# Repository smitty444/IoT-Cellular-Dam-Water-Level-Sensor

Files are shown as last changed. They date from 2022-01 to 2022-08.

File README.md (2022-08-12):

# IOT-Cellular-Dam-Water-Level-Sensor
This is an Arduino Mega based stage sensor developed by interns at the South Carolina Department of Health and Environmental Control (SC DHEC) Dam Safety Program. The purpose of this sensor is to provide a low-cost, open-source alternative to traditional gaging equipment. Both an ultrasonic sensor and a pressure transducer are used to measure stage, and all data is sent via the Hologram cellular network to a graphic user interface (GUI) hosted on Adafruit IO. *Note: this repository was formerly named "DHEC-Stage-Sensor".

<p align="center">
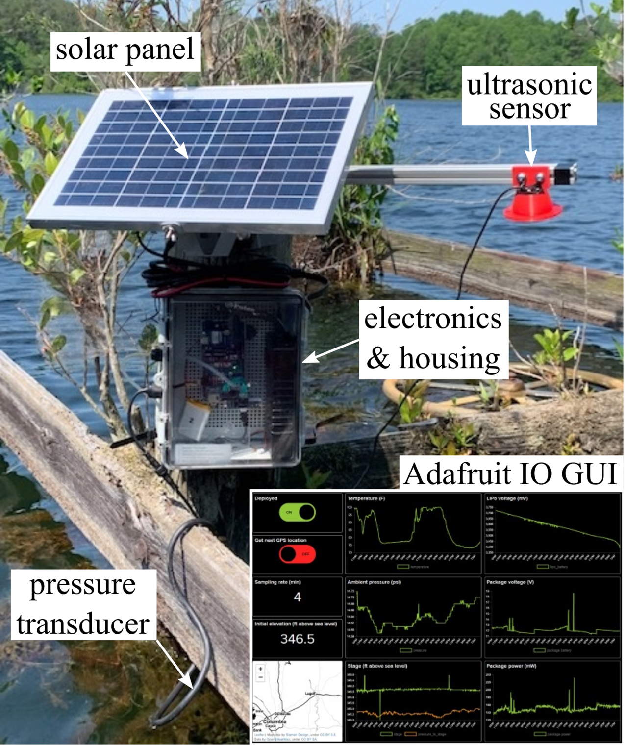
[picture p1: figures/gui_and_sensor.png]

</p>
<p align="center">
Figure 1: Sensor deployed on the primary spillway of a dam transmitting data to the GUI.
</p>

## characteristic data
contains validation data for the sensor, as well as test data for filtering, pressure transducer calibration

## code
contains all the Arduino code for the sensor

## EDA
contains all electronic design automation (EDA) files for the custom datalogging and power PCBs

## field tests
contains data for all field tests performed with the sensor package, as well as Python scripts for visualizing data

# Citation
Cite as:

@Misc{Smith2022DHECStageSensor,     
  author = {Corinne Smith and Parker Lovett and John McCain and Austin Downey},  
  howpublished = {GitHub},  
  title  = {DHEC Stage Sensor},
  year   = {2022},  
  groups = {ARTS-Lab},    
  url    = {https://github.com/ARTS-Laboratory/IoT-Cellular-Dam-Water-Level-Sensor },   
}

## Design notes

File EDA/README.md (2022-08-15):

## Overview
1. All PCBs were designed running KiCAD 6.0
2. Custom schematic symbols are located in lib_and_pretty\ARTS-Lab.lib
3. Custom footprint symbols are located in lib_and_pretty\dhec.pretty

## Datalogger PCB
The datalogger PCB is the main data acquisition and saving board. It contains the DS3231 real-time clock, microSD card module, MPRLS ambient pressure sensor, JSN-SR04 ultrasonic sensor, pressure transducer port, and indicator LEDs. 

<p align="center">
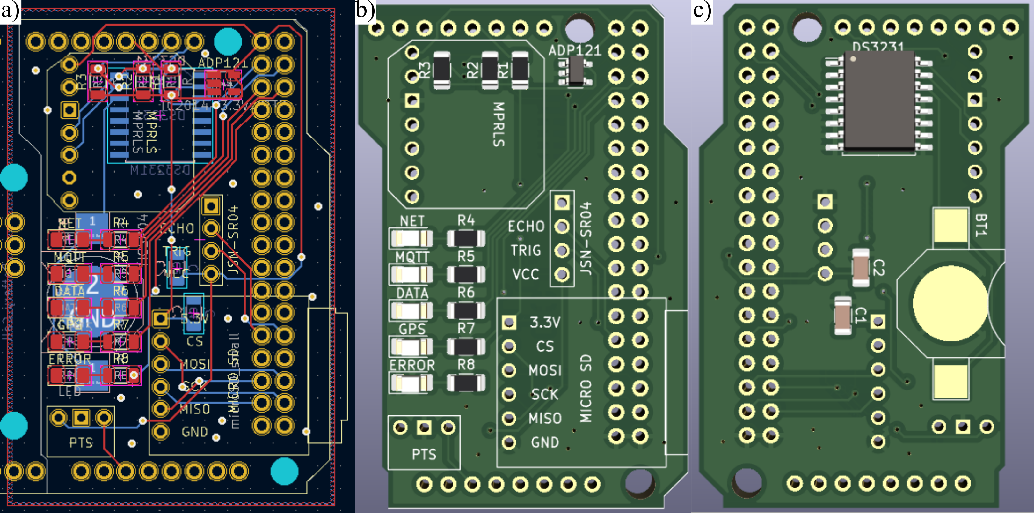
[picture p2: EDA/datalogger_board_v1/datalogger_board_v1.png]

</p>
<p align="center">
Figure 1: Datalogger board showing a) the PCB layout and the 3D rendering of the PCB b) front and c) back.
</p>

## Power control PCB
The power control PCB is used to monitor the package battery voltage and regulate the voltage to 5V for powering the Arduino Mega. It contains the INA219 current sensor and a barrel battery connector. 

<p align="center">
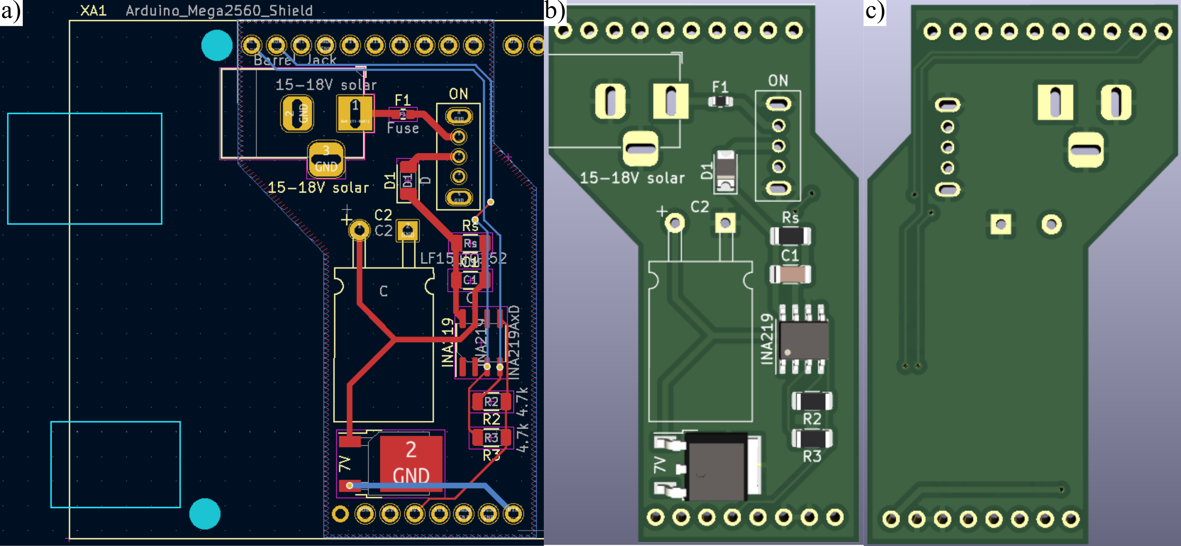
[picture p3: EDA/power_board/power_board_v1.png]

</p>
<p align="center">
Figure 1: Power control board showing a) the PCB layout and the 3D rendering of the PCB b) front and c) back.
</p>

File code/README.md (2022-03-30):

# debugging
- folder contains small sketches for troubleshooting sensors, logic flows, etc

# libraries 
- contains all the necessary libraries for codes

# water level sensor
- contains all codes created for water level sensor package

# syphon sensor
- contains all codes created for the syphon on/off sensor package

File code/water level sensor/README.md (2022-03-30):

# v1.1.x
- contains all codes from early development
- milestones: gps toggle, deployment toggle, sensor communication

# v1.2.x
- focus on power saving modes
- adaptive sampling
- milestones: RTC power down (minutes and seconds), FONA power down

# v2.x
- codes to be used with the v1 of EDA

# WLS_MQTT_toAdafruitIO_v6_STABLE
- Shawn's code for his dashboard, unedited

# working_AdafruitIO_MQTT_Demo_v2_stable
- botletics demo code configured for the SIM7000A hardware
- Publishing feeds: temperature, humidity
- Subscribing feeds: led toggle, led selection
- Outdated from current Adafruit IO dashboard

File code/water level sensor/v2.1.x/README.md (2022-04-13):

# WHS_v2.1.0.ino
- integrate DDASA v1
- Sampling rate can exceed keepAlive time
- built off of WHS_v2.0
- Publishing feeds: location, ultrasonic stage, pressure stage, temperature, ambient pressure, update gps, fona LiPo
- Subscribing feeds: deployment toggle, sampling rate, initial elevation, update gps

# WHS_v2.1.0.noSPI.ino
- Excludes error messages that stop code when SD card or MPRLS are not working
- this was made purely for a quick field test
- datalogging board experienced some issues at the SPI ports from getting wet
- use when you care about just stage readings

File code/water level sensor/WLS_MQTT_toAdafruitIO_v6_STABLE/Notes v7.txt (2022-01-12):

*****Full Disclosure*****

The DHEC-developed version of this arduino app that uses MQTT was never intended to be more than proof-of-concept for further development, and to facilitate USC senior design testing.

This program is based off of a 'Botletics' tutorial & SIMCom Library similar to that which was used for the original USC demo. 

The Botletics SIMCom library has significant limitations & liabilities. Particularly, any elements on the session and transport layers of cellular communication are certainly outside of [frazerss]'s ability to assimilate with confidence with the available resources.

"Substantially advanced cellular networking is indistinguishable from magic." -> Thus there may be inefficiencies or completely backwards problems that are due to misinterpretation of a function's function.

---- At some point, a substantial overhaul of this code may be warranted, if not absolutely necessary. ----

*****Botletics Library, Demo, and Schematic GitHub*****
https://github.com/botletics/SIM7000-LTE-Shield

*****Accessing *****
ZIP File access and extraction:
Extract "Arduino_Functional_Libraries_v7_1-6-2022.zip" and place (beware copying and replacing) the 'Arduino' folder in a user's documents folder.

(If issues exist in running v7, 'v6 Stable' is a version that was burned into a zip with all of the necessary included libraries in the same directory for cross-person sending, but there are some minor updates in apparently necessary delay timings from v6 to v7)

*****SSF Known Issues*****

PRIORITY:
***USB logging is completely non-functional at this time, this should be a priority for data review.
***Pressure sensor is returning exclusively 5V (max PSI reading). Likely broken or otherwise shorted.
**Library management in Arduino environment is problematic, and inhibits attempts at source control.
*Ultrasonic sensor variability during tests at USC was problematic. (Rainfall/interference, moisture, noise... all may play factors in U/S sensor issues.)

NORMAL:
**Suspect that the complete enclosure of cellular antenna substantially decreases cellular transport-level issues.
*High-level functions can likely be optimized for memory and time optimization. (Lower-level library functions may prove to be limiting factor.)
*Subscription Checking of the Publish Frequency Control feed is irregular at best
*Variable Names are Problematic
*Email event can probably be deactivated until data calibration issues can be sorted

LOW:
*Substantial potential for memory optimization exists
*Must break up JSON publish strings into three separate publish events
*Email event process likely needs significant revision

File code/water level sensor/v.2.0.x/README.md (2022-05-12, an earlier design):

# WHS_v2.0 (STABLE)
- compatible with datalogging shield
- AT+CSCLK=1, sleep mode controlled by DTR pin
- copied over, formerly v2.0.1
- Sampling rate does not exceed 5 minutes
- any connectivity issues experienced should be from poor environment or network provider's side
- Publishing feeds: location, ultrasonic stage, pressure stage, temperature, ambient pressure, update gps
- Subscribing feeds: deployment toggle, sampling rate, initial elevation, update gps

# WHS_v2.0.1.ino
- added fona lipo feed

# WHS_v2.0.2.ino
- allow maximum delay to exceed 5 minutes

# WHS_v2.0.3.ino
- add external temperature sensor

# WHS_v2.0.4.ino
- add voltage sensor and integrate with power board

# WHS_v2.0.5.ino
- add median filtering technique

# WHS_v2.0.6.ino
- copied from WHS_v2.0.4
- does not have the median filter in order to send raw data and post process
- add contact sensor feed

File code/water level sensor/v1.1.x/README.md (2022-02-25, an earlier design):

## WHS_v1.1
- created by Corinne
- Publishing feeds: temperature, pressure, stage
- Subscribing feeds: deployment toggle, sampling rate, initial sea level elevation
- main feature is adding a while loop in the setup that will take in all subscriptions
to initialize parameters, then only start data collection once the deployment button
is toggled

## WHS_v1.1.2 
- created by Corinne
- same feeds as v1.1
- pressure sensor added

## WHS_v1.1.3
- created by Corinne
- added location feed & GPS functionality
- added indicator LEDs to display when network is connected, MQTT is connected, data is being collected, the GPS is found, and publishing errors
- NOTE: the Adafrut_FONA.h library had to be modified for this code to suppress a Not Authorized to Connect error

## WHS_v1.1.4
- created by Corinne
- Publishing feeds: location, ultrasonic stage, pressure stage, temperature, ambient pressure
- Subscribing feeds: deployment toggle, sampling rate, initial elevation
- classic datalogger setup with clock and SD card for back up saving

## WHS_v1.1.5
- created by Corinne
- Publishing feeds: location, ultrasonic stage, pressure stage, temperature, ambient pressure, update gps
- Subscribing feeds: deployment toggle, sampling rate, initial elevation, update gps
- gps toggle button that allows you to manually decide when to update the gps to save power

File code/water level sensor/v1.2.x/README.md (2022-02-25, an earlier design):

## WHS_v1.2
- created by Corinne
- Publishing feeds: location, ultrasonic stage, pressure stage, temperature, ambient pressure, update gps, contact sensor
- Subscribing feeds: deployment toggle, sampling rate, initial elevation, update gps
- Incorporate low power mode for Arduino using RTC interrupts
- Only turn GPS on when the update gps toggle is on

## WHS_v1.2.1
- created by Corinne
- add a way to turn off cellular shield

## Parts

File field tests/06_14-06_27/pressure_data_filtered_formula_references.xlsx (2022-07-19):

id |  | value | date | time |  | feet of water offset | true depth | voltage | psi | abs pressure | ambient press | dP | depth | elevation
0F1QFYVAEFYBZHAM9GJWP2SV0E | 151 | 151.78 | 2022-06-14 | 13:09:45 | 17:09:45 | 0 | 1.301 | 0.7253828564 | 1.611961903 | 15.1869619 | 14.6 | 0.586961903 | 1.354003718 | 151.83
0F1QG139KX82V4ZYH7KR3G48CX | 151.06 | 151.84 | 2022-06-14 | 13:13:41 | 17:13:41 | 0.06 | 1.361 | 0.7357771464 | 1.635060325 | 15.21006033 | 14.6 | 0.6100603254 | 1.407287159 | 151.89
0F1QG3CHB8T8NPH5HD4ACRRRBK | 151.14 | 151.92 | 2022-06-14 | 13:17:41 | 17:17:41 | 0.14 | 1.441 | 0.7496361998 | 1.665858222 | 15.24085822 | 14.6 | 0.6408582219 | 1.478331746 | 151.96
0F1QG5NQHE0MTKQ9ETVQTGRFEW | 151.14 | 151.92 | 2022-06-14 | 13:21:41 | 17:21:41 | 0.14 | 1.441 | 0.7496361998 | 1.665858222 | 15.24085822 | 14.6 | 0.6408582219 | 1.478331746 | 151.96
0F1QG7Z2CVQ63WZD7V3MQ28S5T | 151.12 | 151.9 | 2022-06-14 | 13:25:41 | 17:25:41 | 0.12 | 1.421 | 0.7461714365 | 1.658158748 | 15.23315875 | 14.65 | 0.5831587478 | 1.345230599 | 151.82
0F1QGA8717PRDDPKBXBNQ1ER00 | 151.14 | 151.92 | 2022-06-14 | 13:29:40 | 17:29:40 | 0.14 | 1.441 | 0.7496361998 | 1.665858222 | 15.24085822 | 14.65 | 0.5908582219 | 1.362991746 | 151.84
0F1QGCHERRWTEKFDR71H8WXR1A | 151.14 | 151.92 | 2022-06-14 | 13:33:41 | 17:33:41 | 0.14 | 1.441 | 0.7496361998 | 1.665858222 | 15.24085822 | 14.65 | 0.5908582219 | 1.362991746 | 151.84
0F1QGETQB1AMFHYKPXFV95ZX4M | 151.14 | 151.92 | 2022-06-14 | 13:37:41 | 17:37:41 | 0.14 | 1.441 | 0.7496361998 | 1.665858222 | 15.24085822 | 14.68 | 0.5608582219 | 1.293787746 | 151.77
0F1QGH3W16ESDVFEXGNHHS7G7K | 151.14 | 151.92 | 2022-06-14 | 13:41:40 | 17:41:40 | 0.14 | 1.441 | 0.7496361998 | 1.665858222 | 15.24085822 | 14.68 | 0.5608582219 | 1.293787746 | 151.77
0F1QGKD2ZEFWESAWC9PJ93G201 | 151.17 | 151.95 | 2022-06-14 | 13:45:40 | 17:45:40 | 0.17 | 1.471 | 0.7548333449 | 1.677407433 | 15.25240743 | 14.68 | 0.5724074331 | 1.320429467 | 151.80
0F1QGNPFANJTFF0W9ET0W8PPWH | 151.14 | 151.92 | 2022-06-14 | 13:49:41 | 17:49:41 | 0.14 | 1.441 | 0.7496361998 | 1.665858222 | 15.24085822 | 14.69 | 0.5508582219 | 1.270719746 | 151.75
0F1QGQZKA3WBH2EQ65C9JQ2H5F | 151.14 | 151.92 | 2022-06-14 | 13:53:40 | 17:53:40 | 0.14 | 1.441 | 0.7496361998 | 1.665858222 | 15.24085822 | 14.69 | 0.5508582219 | 1.270719746 | 151.75
0F1QGT8VQ2ZMKZ7XHMDJZ4H097 | 151.14 | 151.92 | 2022-06-14 | 13:57:40 | 17:57:40 | 0.14 | 1.441 | 0.7496361998 | 1.665858222 | 15.24085822 | 14.69 | 0.5508582219 | 1.270719746 | 151.75
0F1QGWJ2S78MJJN4AVYY8BM9JH | 151.14 | 151.92 | 2022-06-14 | 14:01:40 | 18:01:40 | 0.14 | 1.441 | 0.7496361998 | 1.665858222 | 15.24085822 | 14.68 | 0.5608582219 | 1.293787746 | 151.77
0F1QGYVCRMBKWJKBB6CYV2XN2K | 151.14 | 151.92 | 2022-06-14 | 14:05:41 | 18:05:41 | 0.14 | 1.441 | 0.7496361998 | 1.665858222 | 15.24085822 | 14.68 | 0.5608582219 | 1.293787746 | 151.77
0F1QH14JZR3X72SJE46X6843ZD | 151.14 | 151.92 | 2022-06-14 | 14:09:40 | 18:09:40 | 0.14 | 1.441 | 0.7496361998 | 1.665858222 | 15.24085822 | 14.68 | 0.5608582219 | 1.293787746 | 151.77
0F1QH3DTSTZVMQBQB5XMWGNT9E | 151.17 | 151.95 | 2022-06-14 | 14:13:40 | 18:13:40 | 0.17 | 1.471 | 0.7548333449 | 1.677407433 | 15.25240743 | 14.68 | 0.5724074331 | 1.320429467 | 151.80
0F1QH5Q2F9WPZRH8V6Y13HDPKT | 151.14 | 151.92 | 2022-06-14 | 14:17:40 | 18:17:40 | 0.14 | 1.441 | 0.7496361998 | 1.665858222 | 15.24085822 | 14.69 | 0.5508582219 | 1.270719746 | 151.75
0F1QH80DAJTYSQ5RYWSQDKKD96 | 151.2 | 151.98 | 2022-06-14 | 14:21:41 | 18:21:41 | 0.2 | 1.501 | 0.7600304899 | 1.688956644 | 15.26395664 | 14.7 | 0.5639566443 | 1.300935187 | 151.78
0F1QHA9H8QEXPMEGT4PWZ9SFG4 | 151.17 | 151.95 | 2022-06-14 | 14:25:40 | 18:25:40 | 0.17 | 1.471 | 0.7548333449 | 1.677407433 | 15.25240743 | 14.7 | 0.5524074331 | 1.274293467 | 151.75
0F1QHCJW1DS4NK0EKEC0HZB0EE | 151.23 | 152.01 | 2022-06-14 | 14:29:41 | 18:29:41 | 0.23 | 1.531 | 0.765227635 | 1.700505855 | 15.27550586 | 14.69 | 0.5855058555 | 1.350644907 | 151.83
0F1QHEW350KSXNPD6PHTD1EY2F | 151.26 | 152.04 | 2022-06-14 | 14:33:41 | 18:33:41 | 0.26 | 1.561 | 0.77042478 | 1.712055067 | 15.28705507 | 14.7 | 0.5870550666 | 1.354218628 | 151.83
0F1QHH5HT3P9SJ2SEA1AG9F6N7 | 151.29 | 152.07 | 2022-06-14 | 14:37:41 | 18:37:41 | 0.29 | 1.591 | 0.775621925 | 1.723604278 | 15.29860428 | 14.69 | 0.6086042778 | 1.403928348 | 151.88
0F1QHKEHRSPR0GGMSQKV6AM2ZD | 151.26 | 152.04 | 2022-06-14 | 14:41:41 | 18:41:41 | 0.26 | 1.561 | 0.77042478 | 1.712055067 | 15.28705507 | 14.69 | 0.5970550666 | 1.377286628 | 151.86
0F1QHNQQXT7P05WJ9JHZJPAENQ | 151.26 | 152.04 | 2022-06-14 | 14:45:40 | 18:45:40 | 0.26 | 1.561 | 0.77042478 | 1.712055067 | 15.28705507 | 14.7 | 0.5870550666 | 1.354218628 | 151.83
0F1QHR12TX8Z382AK9DCKRP3R2 | 151.26 | 152.04 | 2022-06-14 | 14:49:41 | 18:49:41 | 0.26 | 1.561 | 0.77042478 | 1.712055067 | 15.28705507 | 14.69 | 0.5970550666 | 1.377286628 | 151.86
0F1QHTACWEWY4BMYBCQE9Q6CET | 151.2 | 151.98 | 2022-06-14 | 14:53:41 | 18:53:41 | 0.2 | 1.501 | 0.7600304899 | 1.688956644 | 15.26395664 | 14.69 | 0.5739566443 | 1.324003187 | 151.80
0F1QHWKP9QFEBF3839DNB256W7 | 151.2 | 151.98 | 2022-06-14 | 14:57:40 | 18:57:40 | 0.2 | 1.501 | 0.7600304899 | 1.688956644 | 15.26395664 | 14.69 | 0.5739566443 | 1.324003187 | 151.80
0F1QHYWPX1HHM8S75CBKBZRE50 | 151.2 | 151.98 | 2022-06-14 | 15:01:40 | 19:01:40 | 0.2 | 1.501 | 0.7600304899 | 1.688956644 | 15.26395664 | 14.69 | 0.5739566443 | 1.324003187 | 151.80
0F1QJ1608KPG8FPBM2KSMH5S5V | 151.17 | 151.95 | 2022-06-14 | 15:05:41 | 19:05:41 | 0.17 | 1.471 | 0.7548333449 | 1.677407433 | 15.25240743 | 14.69 | 0.5624074331 | 1.297361467 | 151.78
0F1QJ3F76Q78NHN6ZEVKMX6C82 | 151.17 | 151.95 | 2022-06-14 | 15:09:40 | 19:09:40 | 0.17 | 1.471 | 0.7548333449 | 1.677407433 | 15.25240743 | 14.69 | 0.5624074331 | 1.297361467 | 151.78
0F1QJ5RHAJD3SEBYJR37ZEH3ZN | 151.17 | 151.95 | 2022-06-14 | 15:13:41 | 19:13:41 | 0.17 | 1.471 | 0.7548333449 | 1.677407433 | 15.25240743 | 14.69 | 0.5624074331 | 1.297361467 | 151.78
0F1QJ81R95CX469VGSXE1AYVKZ | 151.17 | 151.95 | 2022-06-14 | 15:17:41 | 19:17:41 | 0.17 | 1.471 | 0.7548333449 | 1.677407433 | 15.25240743 | 14.69 | 0.5624074331 | 1.297361467 | 151.78
0F1QJAAYHFSHD758DZTADFVSWG | 151.14 | 151.92 | 2022-06-14 | 15:21:40 | 19:21:40 | 0.14 | 1.441 | 0.7496361998 | 1.665858222 | 15.24085822 | 14.69 | 0.5508582219 | 1.270719746 | 151.75
0F1QJCM8HMCRXHDDMF30N70W11 | 151.17 | 151.95 | 2022-06-14 | 15:25:41 | 19:25:41 | 0.17 | 1.471 | 0.7548333449 | 1.677407433 | 15.25240743 | 14.69 | 0.5624074331 | 1.297361467 | 151.78
0F1QJEXH3GYR92TQBGHQBG2522 | 151.17 | 151.95 | 2022-06-14 | 15:29:41 | 19:29:41 | 0.17 | 1.471 | 0.7548333449 | 1.677407433 | 15.25240743 | 14.69 | 0.5624074331 | 1.297361467 | 151.78
0F1QJH6PMW4N09NXM6473J2HQS | 151.17 | 151.95 | 2022-06-14 | 15:33:41 | 19:33:41 | 0.17 | 1.471 | 0.7548333449 | 1.677407433 | 15.25240743 | 14.69 | 0.5624074331 | 1.297361467 | 151.78
0F1QJKFY8AEG5YP94NH3JV5DXD | 151.17 | 151.95 | 2022-06-14 | 15:37:41 | 19:37:41 | 0.17 | 1.471 | 0.7548333449 | 1.677407433 | 15.25240743 | 14.69 | 0.5624074331 | 1.297361467 | 151.78
0F1QJNS62PM5QD77MH7W9TA7ZY | 151.17 | 151.95 | 2022-06-14 | 15:41:41 | 19:41:41 | 0.17 | 1.471 | 0.7548333449 | 1.677407433 | 15.25240743 | 14.69 | 0.5624074331 | 1.297361467 | 151.78
0F1QJR2G54Y1QBSRTNJN4HJQ63 | 151.14 | 151.92 | 2022-06-14 | 15:45:41 | 19:45:41 | 0.14 | 1.441 | 0.7496361998 | 1.665858222 | 15.24085822 | 14.69 | 0.5508582219 | 1.270719746 | 151.75
0F1QJTBPAV9J0P5KJMD68VT30A | 151.14 | 151.92 | 2022-06-14 | 15:49:41 | 19:49:41 | 0.14 | 1.441 | 0.7496361998 | 1.665858222 | 15.24085822 | 14.69 | 0.5508582219 | 1.270719746 | 151.75
0F1QJWN0EJ5J41K7QHQS26ZBD2 | 151.14 | 151.92 | 2022-06-14 | 15:53:41 | 19:53:41 | 0.14 | 1.441 | 0.7496361998 | 1.665858222 | 15.24085822 | 14.69 | 0.5508582219 | 1.270719746 | 151.75
0F1QJYY84AHWGCVGEHRTKYXTQ4 | 151.14 | 151.92 | 2022-06-14 | 15:57:41 | 19:57:41 | 0.14 | 1.441 | 0.7496361998 | 1.665858222 | 15.24085822 | 14.69 | 0.5508582219 | 1.270719746 | 151.75
0F1QK17DHNHSKHKQSR9G6F03DA | 151.14 | 151.92 | 2022-06-14 | 16:01:41 | 20:01:41 | 0.14 | 1.441 | 0.7496361998 | 1.665858222 | 15.24085822 | 14.69 | 0.5508582219 | 1.270719746 | 151.75
0F1QK3GQPGHY10DYW15T73S1H0 | 151.14 | 151.92 | 2022-06-14 | 16:05:41 | 20:05:41 | 0.14 | 1.441 | 0.7496361998 | 1.665858222 | 15.24085822 | 14.69 | 0.5508582219 | 1.270719746 | 151.75
0F1QK5SZCJNHWB0ASRJ95C4T3A | 151.14 | 151.92 | 2022-06-14 | 16:09:41 | 20:09:41 | 0.14 | 1.441 | 0.7496361998 | 1.665858222 | 15.24085822 | 14.69 | 0.5508582219 | 1.270719746 | 151.75
0F1QK834RN8857MMYFCC8VR9WD | 151.14 | 151.92 | 2022-06-14 | 16:13:41 | 20:13:41 | 0.14 | 1.441 | 0.7496361998 | 1.665858222 | 15.24085822 | 14.69 | 0.5508582219 | 1.270719746 | 151.75
0F1QKACCKG0642WV16YA1866ZP | 151.14 | 151.92 | 2022-06-14 | 16:17:41 | 20:17:41 | 0.14 | 1.441 | 0.7496361998 | 1.665858222 | 15.24085822 | 14.69 | 0.5508582219 | 1.270719746 | 151.75
0F1QKCNN31MVMAGVY06E0Q1BRX | 151.14 | 151.92 | 2022-06-14 | 16:21:41 | 20:21:41 | 0.14 | 1.441 | 0.7496361998 | 1.665858222 | 15.24085822 | 14.69 | 0.5508582219 | 1.270719746 | 151.75
0F1QKEYSP0FJZR5V6EMSYEAK5E | 151.14 | 151.92 | 2022-06-14 | 16:25:40 | 20:25:40 | 0.14 | 1.441 | 0.7496361998 | 1.665858222 | 15.24085822 | 14.69 | 0.5508582219 | 1.270719746 | 151.75
0F1QKH85D59T2HNA5D07PWZCV5 | 151.14 | 151.92 | 2022-06-14 | 16:29:41 | 20:29:41 | 0.14 | 1.441 | 0.7496361998 | 1.665858222 | 15.24085822 | 14.69 | 0.5508582219 | 1.270719746 | 151.75
0F1QKKHBHG8KKVD4TS4V467DXR | 151.14 | 151.92 | 2022-06-14 | 16:33:41 | 20:33:41 | 0.14 | 1.441 | 0.7496361998 | 1.665858222 | 15.24085822 | 14.69 | 0.5508582219 | 1.270719746 | 151.75
0F1QKNTHP81FREDE5ZSQKSV1TG | 151.14 | 151.92 | 2022-06-14 | 16:37:40 | 20:37:40 | 0.14 | 1.441 | 0.7496361998 | 1.665858222 | 15.24085822 | 14.69 | 0.5508582219 | 1.270719746 | 151.75
0F1QKR3RQTRWPXHRP9J5MR3167 | 151.14 | 151.92 | 2022-06-14 | 16:41:40 | 20:41:40 | 0.14 | 1.441 | 0.7496361998 | 1.665858222 | 15.24085822 | 14.69 | 0.5508582219 | 1.270719746 | 151.75
0F1QKTD194HBHXE9RQZGS89DYQ | 151.12 | 151.9 | 2022-06-14 | 16:45:40 | 20:45:40 | 0.12 | 1.421 | 0.7461714365 | 1.658158748 | 15.23315875 | 14.69 | 0.5431587478 | 1.252958599 | 151.73
0F1QKWPEEEAV9ZGG4HN8V1579D | 151.14 | 151.92 | 2022-06-14 | 16:49:41 | 20:49:41 | 0.14 | 1.441 | 0.7496361998 | 1.665858222 | 15.24085822 | 14.69 | 0.5508582219 | 1.270719746 | 151.75
0F1QKYZJ8R3HWW0SGXSGPSWNAG | 151.12 | 151.9 | 2022-06-14 | 16:53:41 | 20:53:41 | 0.12 | 1.421 | 0.7461714365 | 1.658158748 | 15.23315875 | 14.69 | 0.5431587478 | 1.252958599 | 151.73
0F1QM18TT7S4J0H4X0E32W1DN7 | 151.12 | 151.9 | 2022-06-14 | 16:57:41 | 20:57:41 | 0.12 | 1.421 | 0.7461714365 | 1.658158748 | 15.23315875 | 14.7 | 0.5331587478 | 1.229890599 | 151.71
0F1QM3J1RD6YDTWNCB6RCZTFP6 | 150.64 | 151.42 | 2022-06-14 | 17:01:40 | 21:01:40 | -0.36 | 0.941 | 0.6630171159 | 1.473371369 | 15.04837137 | 14.69 | 0.3583713687 | 0.8266910734 | 151.31
0F1QM5V76KHYRDR2E5BC4QZ4EQ | 150.75 | 151.53 | 2022-06-14 | 17:05:40 | 21:05:40 | -0.25 | 1.051 | 0.6820733144 | 1.515718476 | 15.09071848 | 14.7 | 0.3907184764 | 0.9013093814 | 151.38
0F1QM84FRCTBAJWQE1NGNDS9J6 | 150.75 | 151.53 | 2022-06-14 | 17:09:40 | 21:09:40 | -0.25 | 1.051 | 0.6820733144 | 1.515718476 | 15.09071848 | 14.7 | 0.3907184764 | 0.9013093814 | 151.38
0F1QMADW6QHFQF2ND4VW70Z72B | 150.75 | 151.53 | 2022-06-14 | 17:13:41 | 21:13:41 | -0.25 | 1.051 | 0.6820733144 | 1.515718476 | 15.09071848 | 14.7 | 0.3907184764 | 0.9013093814 | 151.38
0F1QMCQ0SYFAEZEDKD7WZ7G5PB | 150.75 | 151.53 | 2022-06-14 | 17:17:41 | 21:17:41 | -0.25 | 1.051 | 0.6820733144 | 1.515718476 | 15.09071848 | 14.7 | 0.3907184764 | 0.9013093814 | 151.38
0F1QMF08JKHN80V4RMWJJMXXD2 | 150.75 | 151.53 | 2022-06-14 | 17:21:41 | 21:21:41 | -0.25 | 1.051 | 0.6820733144 | 1.515718476 | 15.09071848 | 14.7 | 0.3907184764 | 0.9013093814 | 151.38
0F1QMH9HWDCJDDJK0V79CA6A9K | 150.75 | 151.53 | 2022-06-14 | 17:25:41 | 21:25:41 | -0.25 | 1.051 | 0.6820733144 | 1.515718476 | 15.09071848 | 14.69 | 0.4007184764 | 0.9243773814 | 151.40
0F1QMKJPKK2HZ5Q703MN6ZS0JX | 150.75 | 151.53 | 2022-06-14 | 17:29:40 | 21:29:40 | -0.25 | 1.051 | 0.6820733144 | 1.515718476 | 15.09071848 | 14.69 | 0.4007184764 | 0.9243773814 | 151.40
0F1QMNW30TQWF9K7009J92015W | 150.75 | 151.53 | 2022-06-14 | 17:33:41 | 21:33:41 | -0.25 | 1.051 | 0.6820733144 | 1.515718476 | 15.09071848 | 14.69 | 0.4007184764 | 0.9243773814 | 151.40
0F1QMR57JZ0NMFDN6ZGY6GJ3MP | 150.75 | 151.53 | 2022-06-14 | 17:37:41 | 21:37:41 | -0.25 | 1.051 | 0.6820733144 | 1.515718476 | 15.09071848 | 14.69 | 0.4007184764 | 0.9243773814 | 151.40
0F1QMTEF9YZDDHE0YRJJARZZS0 | 150.75 | 151.53 | 2022-06-14 | 17:41:41 | 21:41:41 | -0.25 | 1.051 | 0.6820733144 | 1.515718476 | 15.09071848 | 14.69 | 0.4007184764 | 0.9243773814 | 151.40
0F1QMWQQ2GS6Q6ACJPJP37VF0X | 150.72 | 151.5 | 2022-06-14 | 17:45:41 | 21:45:41 | -0.28 | 1.021 | 0.6768761694 | 1.504169265 | 15.07916927 | 14.69 | 0.3891692652 | 0.8977356611 | 151.38
0F1QMZ0Y1156Y9W0KHY6T3D91T | 150.72 | 151.5 | 2022-06-14 | 17:49:41 | 21:49:41 | -0.28 | 1.021 | 0.6768761694 | 1.504169265 | 15.07916927 | 14.69 | 0.3891692652 | 0.8977356611 | 151.38
0F1QN1A7CQ30WWF90R8JZWZ50M | 150.75 | 151.53 | 2022-06-14 | 17:53:41 | 21:53:41 | -0.25 | 1.051 | 0.6820733144 | 1.515718476 | 15.09071848 | 14.69 | 0.4007184764 | 0.9243773814 | 151.40
0F1QN3KDGY08BZXRHJ2H41THG6 | 150.75 | 151.53 | 2022-06-14 | 17:57:41 | 21:57:41 | -0.25 | 1.051 | 0.6820733144 | 1.515718476 | 15.09071848 | 14.69 | 0.4007184764 | 0.9243773814 | 151.40
0F1QN5X11C8HZA2TAGQ7TZ7AEZ | 150.75 | 151.53 | 2022-06-14 | 18:01:42 | 22:01:42 | -0.25 | 1.051 | 0.6820733144 | 1.515718476 | 15.09071848 | 14.69 | 0.4007184764 | 0.9243773814 | 151.40
0F1QN85XSKTXW6XC1DFEWW0PJ9 | 150.75 | 151.53 | 2022-06-14 | 18:05:41 | 22:05:41 | -0.25 | 1.051 | 0.6820733144 | 1.515718476 | 15.09071848 | 14.69 | 0.4007184764 | 0.9243773814 | 151.40
0F1QNAF8PQR1J5NREPAAAQDTER | 150.72 | 151.5 | 2022-06-14 | 18:09:41 | 22:09:41 | -0.28 | 1.021 | 0.6768761694 | 1.504169265 | 15.07916927 | 14.69 | 0.3891692652 | 0.8977356611 | 151.38
0F1QNCRD9MHBD8CG2B719N604C | 150.72 | 151.5 | 2022-06-14 | 18:13:41 | 22:13:41 | -0.28 | 1.021 | 0.6768761694 | 1.504169265 | 15.07916927 | 14.69 | 0.3891692652 | 0.8977356611 | 151.38
0F1QNF1RZ5JVDR73VFX626NASY | 150.72 | 151.5 | 2022-06-14 | 18:17:41 | 22:17:41 | -0.28 | 1.021 | 0.6768761694 | 1.504169265 | 15.07916927 | 14.69 | 0.3891692652 | 0.8977356611 | 151.38
0F1QNHB1H2A8EW8JRN73NGRANF | 150.72 | 151.5 | 2022-06-14 | 18:21:41 | 22:21:41 | -0.28 | 1.021 | 0.6768761694 | 1.504169265 | 15.07916927 | 14.69 | 0.3891692652 | 0.8977356611 | 151.38
0F1QNKM30WZKZDHA56Z5TBNVRP | 150.72 | 151.5 | 2022-06-14 | 18:25:40 | 22:25:40 | -0.28 | 1.021 | 0.6768761694 | 1.504169265 | 15.07916927 | 14.69 | 0.3891692652 | 0.8977356611 | 151.38
0F1QNNXFDBXK4BAPXHNT3KKG0X | 150.72 | 151.5 | 2022-06-14 | 18:29:41 | 22:29:41 | -0.28 | 1.021 | 0.6768761694 | 1.504169265 | 15.07916927 | 14.69 | 0.3891692652 | 0.8977356611 | 151.38
0F1QNR6SH5PAE1SP3FW4YSGFJZ | 150.72 | 151.5 | 2022-06-14 | 18:33:41 | 22:33:41 | -0.28 | 1.021 | 0.6768761694 | 1.504169265 | 15.07916927 | 14.69 | 0.3891692652 | 0.8977356611 | 151.38
0F1QNTGDRYSB87WTRSD91Y7BMH | 150.72 | 151.5 | 2022-06-14 | 18:37:42 | 22:37:42 | -0.28 | 1.021 | 0.6768761694 | 1.504169265 | 15.07916927 | 14.69 | 0.3891692652 | 0.8977356611 | 151.38
0F1QNWS53RMRXVJ8WDTHKVMK0S | 150.72 | 151.5 | 2022-06-14 | 18:41:41 | 22:41:41 | -0.28 | 1.021 | 0.6768761694 | 1.504169265 | 15.07916927 | 14.68 | 0.3991692652 | 0.9208036611 | 151.40
0F1QNZ2C1ZHN5MAS0V98Q2499B | 150.72 | 151.5 | 2022-06-14 | 18:45:40 | 22:45:40 | -0.28 | 1.021 | 0.6768761694 | 1.504169265 | 15.07916927 | 14.68 | 0.3991692652 | 0.9208036611 | 151.40
0F1QP1BHGYNKMRF8RAQVPWY7DN | 150.72 | 151.5 | 2022-06-14 | 18:49:40 | 22:49:40 | -0.28 | 1.021 | 0.6768761694 | 1.504169265 | 15.07916927 | 14.68 | 0.3991692652 | 0.9208036611 | 151.40
0F1QP3MVJF6QWBRE3EX1HTS0XS | 150.72 | 151.5 | 2022-06-14 | 18:53:41 | 22:53:41 | -0.28 | 1.021 | 0.6768761694 | 1.504169265 | 15.07916927 | 14.68 | 0.3991692652 | 0.9208036611 | 151.40
0F1QP5Y9M3W5F6NT47X63DASH0 | 150.72 | 151.5 | 2022-06-14 | 18:57:41 | 22:57:41 | -0.28 | 1.021 | 0.6768761694 | 1.504169265 | 15.07916927 | 14.68 | 0.3991692652 | 0.9208036611 | 151.40
0F1QP87FRMEYCNQ9KJJP6D1336 | 150.72 | 151.5 | 2022-06-14 | 19:01:41 | 23:01:41 | -0.28 | 1.021 | 0.6768761694 | 1.504169265 | 15.07916927 | 14.68 | 0.3991692652 | 0.9208036611 | 151.40
0F1QPAGJV74DAY9RN2G6RC9K6W | 150.72 | 151.5 | 2022-06-14 | 19:05:41 | 23:05:41 | -0.28 | 1.021 | 0.6768761694 | 1.504169265 | 15.07916927 | 14.68 | 0.3991692652 | 0.9208036611 | 151.40
0F1QPCSYH5ZG1RYC1CYK7P9K9Q | 150.69 | 151.47 | 2022-06-14 | 19:09:41 | 23:09:41 | -0.31 | 0.991 | 0.6716790243 | 1.492620054 | 15.06762005 | 14.69 | 0.3776200541 | 0.8710939407 | 151.35
0F1QPF31KECNS9D4F0DKJ25TKJ | 150.69 | 151.47 | 2022-06-14 | 19:13:41 | 23:13:41 | -0.31 | 0.991 | 0.6716790243 | 1.492620054 | 15.06762005 | 14.68 | 0.3876200541 | 0.8941619407 | 151.37
0F1QPHC9C5VPGH0G72CEKKDT1P | 150.72 | 151.5 | 2022-06-14 | 19:17:41 | 23:17:41 | -0.28 | 1.021 | 0.6768761694 | 1.504169265 | 15.07916927 | 14.68 | 0.3991692652 | 0.9208036611 | 151.40
0F1QPKNHVF27DD7JB36ZS0GJKH | 150.72 | 151.5 | 2022-06-14 | 19:21:41 | 23:21:41 | -0.28 | 1.021 | 0.6768761694 | 1.504169265 | 15.07916927 | 14.69 | 0.3891692652 | 0.8977356611 | 151.38
0F1QPNYPKQQ6733ESBDQRGAZ28 | 150.69 | 151.47 | 2022-06-14 | 19:25:40 | 23:25:40 | -0.31 | 0.991 | 0.6716790243 | 1.492620054 | 15.06762005 | 14.68 | 0.3876200541 | 0.8941619407 | 151.37
0F1QPR83QSHJWA6A84XXRHNC8M | 150.72 | 151.5 | 2022-06-14 | 19:29:41 | 23:29:41 | -0.28 | 1.021 | 0.6768761694 | 1.504169265 | 15.07916927 | 14.69 | 0.3891692652 | 0.8977356611 | 151.38
0F1QPTH6R0113CA0EWA63P40QK | 150.69 | 151.47 | 2022-06-14 | 19:33:40 | 23:33:40 | -0.31 | 0.991 | 0.6716790243 | 1.492620054 | 15.06762005 | 14.69 | 0.3776200541 | 0.8710939407 | 151.35
0F1QPWTHNRVT65VQW155R9QESM | 150.69 | 151.47 | 2022-06-14 | 19:37:41 | 23:37:41 | -0.31 | 0.991 | 0.6716790243 | 1.492620054 | 15.06762005 | 14.69 | 0.3776200541 | 0.8710939407 | 151.35
0F1QPZ3TXY1D6YRJTP37ADG7FS | 150.69 | 151.47 | 2022-06-14 | 19:41:41 | 23:41:41 | -0.31 | 0.991 | 0.6716790243 | 1.492620054 | 15.06762005 | 14.69 | 0.3776200541 | 0.8710939407 | 151.35
0F1QQ1CZKNS2QMAN5MM49VY6R8 | 150.72 | 151.5 | 2022-06-14 | 19:45:41 | 23:45:41 | -0.28 | 1.021 | 0.6768761694 | 1.504169265 | 15.07916927 | 14.69 | 0.3891692652 | 0.8977356611 | 151.38
0F1QQ3P6GV067T1BD49N6QMSDX | 150.69 | 151.47 | 2022-06-14 | 19:49:41 | 23:49:41 | -0.31 | 0.991 | 0.6716790243 | 1.492620054 | 15.06762005 | 14.69 | 0.3776200541 | 0.8710939407 | 151.35
0F1QQ5ZKS98QNKWZSGD3Y6M8CP | 150.69 | 151.47 | 2022-06-14 | 19:53:41 | 23:53:41 | -0.31 | 0.991 | 0.6716790243 | 1.492620054 | 15.06762005 | 14.69 | 0.3776200541 | 0.8710939407 | 151.35
0F1QQ88N88SK169JFQMPTA59SF | 150.69 | 151.47 | 2022-06-14 | 19:57:40 | 23:57:40 | -0.31 | 0.991 | 0.6716790243 | 1.492620054 | 15.06762005 | 14.69 | 0.3776200541 | 0.8710939407 | 151.35
0F1QQAHZC1QEMMQRM5TDCPSBKY | 150.72 | 151.5 | 2022-06-14 | 20:01:41 | 0:01:41 | -0.28 | 1.021 | 0.6768761694 | 1.504169265 | 15.07916927 | 14.68 | 0.3991692652 | 0.9208036611 | 151.40
0F1QQCV6AZ199D9GY729S5WFGV | 150.69 | 151.47 | 2022-06-14 | 20:05:41 | 0:05:41 | -0.31 | 0.991 | 0.6716790243 | 1.492620054 | 15.06762005 | 14.68 | 0.3876200541 | 0.8941619407 | 151.37
0F1QQF4J30P7NMF78EB097J1J9 | 150.69 | 151.47 | 2022-06-14 | 20:09:41 | 0:09:41 | -0.31 | 0.991 | 0.6716790243 | 1.492620054 | 15.06762005 | 14.68 | 0.3876200541 | 0.8941619407 | 151.37
0F1QQHDPK6SKN2WH50BKAYDFQB | 150.69 | 151.47 | 2022-06-14 | 20:13:41 | 0:13:41 | -0.31 | 0.991 | 0.6716790243 | 1.492620054 | 15.06762005 | 14.68 | 0.3876200541 | 0.8941619407 | 151.37
0F1QQKPXJVZXYP8PZDJZT4JA2P | 150.69 | 151.47 | 2022-06-14 | 20:17:41 | 0:17:41 | -0.31 | 0.991 | 0.6716790243 | 1.492620054 | 15.06762005 | 14.68 | 0.3876200541 | 0.8941619407 | 151.37
0F1QQP0ARK0XNCHRAMYKS6K2CF | 150.69 | 151.47 | 2022-06-14 | 20:21:41 | 0:21:41 | -0.31 | 0.991 | 0.6716790243 | 1.492620054 | 15.06762005 | 14.68 | 0.3876200541 | 0.8941619407 | 151.37
0F1QQR9DVJBBX5K5WVEBD3SJAW | 150.69 | 151.47 | 2022-06-14 | 20:25:41 | 0:25:41 | -0.31 | 0.991 | 0.6716790243 | 1.492620054 | 15.06762005 | 14.68 | 0.3876200541 | 0.8941619407 | 151.37
0F1QQTJM3QENKQPK52SDF1BZ1S | 150.69 | 151.47 | 2022-06-14 | 20:29:41 | 0:29:41 | -0.31 | 0.991 | 0.6716790243 | 1.492620054 | 15.06762005 | 14.68 | 0.3876200541 | 0.8941619407 | 151.37
0F1QQWVY47G019YFTMZZ1DQFTP | 150.69 | 151.47 | 2022-06-14 | 20:33:41 | 0:33:41 | -0.31 | 0.991 | 0.6716790243 | 1.492620054 | 15.06762005 | 14.68 | 0.3876200541 | 0.8941619407 | 151.37
0F1QQZ549XQVVHGPFWB8TKZVQ9 | 150.69 | 151.47 | 2022-06-14 | 20:37:41 | 0:37:41 | -0.31 | 0.991 | 0.6716790243 | 1.492620054 | 15.06762005 | 14.68 | 0.3876200541 | 0.8941619407 | 151.37
0F1QR1ECVPXKDGPKDNKMB9YRHP | 150.69 | 151.47 | 2022-06-14 | 20:41:41 | 0:41:41 | -0.31 | 0.991 | 0.6716790243 | 1.492620054 | 15.06762005 | 14.68 | 0.3876200541 | 0.8941619407 | 151.37
0F1QR3QP4VXAHSERBKVGXHYJF3 | 150.69 | 151.47 | 2022-06-14 | 20:45:41 | 0:45:41 | -0.31 | 0.991 | 0.6716790243 | 1.492620054 | 15.06762005 | 14.68 | 0.3876200541 | 0.8941619407 | 151.37
0F1QR6108J6EF2JGHJG85DSJ15 | 150.69 | 151.47 | 2022-06-14 | 20:49:41 | 0:49:41 | -0.31 | 0.991 | 0.6716790243 | 1.492620054 | 15.06762005 | 14.68 | 0.3876200541 | 0.8941619407 | 151.37
0F1QR8A1QNW4JX9SZ8WNSS496R | 150.69 | 151.47 | 2022-06-14 | 20:53:40 | 0:53:40 | -0.31 | 0.991 | 0.6716790243 | 1.492620054 | 15.06762005 | 14.67 | 0.3976200541 | 0.9172299407 | 151.40
0F1QRAKBWGTDKNG0YDQB189M2Z | 150.67 | 151.45 | 2022-06-14 | 20:57:41 | 0:57:41 | -0.33 | 0.971 | 0.668214261 | 1.48492058 | 15.05992058 | 14.67 | 0.3899205799 | 0.8994687938 | 151.38
0F1QRCWJVYAN37KC6GHGGA40A0 | 150.69 | 151.47 | 2022-06-14 | 21:01:41 | 1:01:41 | -0.31 | 0.991 | 0.6716790243 | 1.492620054 | 15.06762005 | 14.67 | 0.3976200541 | 0.9172299407 | 151.40
0F1QRF5YG1FXAFASEKH84VE788 | 150.69 | 151.47 | 2022-06-14 | 21:05:41 | 1:05:41 | -0.31 | 0.991 | 0.6716790243 | 1.492620054 | 15.06762005 | 14.67 | 0.3976200541 | 0.9172299407 | 151.40
0F1QRHF0QX74VSHSC8T7BHPDW6 | 150.69 | 151.47 | 2022-06-14 | 21:09:40 | 1:09:40 | -0.31 | 0.991 | 0.6716790243 | 1.492620054 | 15.06762005 | 14.67 | 0.3976200541 | 0.9172299407 | 151.40
0F1QRKRA2Q0BK9J8KQJHCKGJJZ | 150.69 | 151.47 | 2022-06-14 | 21:13:41 | 1:13:41 | -0.31 | 0.991 | 0.6716790243 | 1.492620054 | 15.06762005 | 14.67 | 0.3976200541 | 0.9172299407 | 151.40
0F1QRP1JJTPZX69E2KYJGKQW4D | 150.69 | 151.47 | 2022-06-14 | 21:17:41 | 1:17:41 | -0.31 | 0.991 | 0.6716790243 | 1.492620054 | 15.06762005 | 14.67 | 0.3976200541 | 0.9172299407 | 151.40
0F1QRRASK0TD53RQ1XGNR1KXCD | 150.69 | 151.47 | 2022-06-14 | 21:21:41 | 1:21:41 | -0.31 | 0.991 | 0.6716790243 | 1.492620054 | 15.06762005 | 14.67 | 0.3976200541 | 0.9172299407 | 151.40
0F1QRTM23304CBQ77SD2A2RSGH | 150.67 | 151.45 | 2022-06-14 | 21:25:41 | 1:25:41 | -0.33 | 0.971 | 0.668214261 | 1.48492058 | 15.05992058 | 14.67 | 0.3899205799 | 0.8994687938 | 151.38
0F1QRWX927B1JBFJNVXPPXA3JN | 150.69 | 151.47 | 2022-06-14 | 21:29:41 | 1:29:41 | -0.31 | 0.991 | 0.6716790243 | 1.492620054 | 15.06762005 | 14.67 | 0.3976200541 | 0.9172299407 | 151.40
0F1QRZ6K79D886JZ76V014M8BQ | 150.67 | 151.45 | 2022-06-14 | 21:33:41 | 1:33:41 | -0.33 | 0.971 | 0.668214261 | 1.48492058 | 15.05992058 | 14.67 | 0.3899205799 | 0.8994687938 | 151.38
0F1QS1FX95BBXK5A8T6K7Y88JT | 150.67 | 151.45 | 2022-06-14 | 21:37:41 | 1:37:41 | -0.33 | 0.971 | 0.668214261 | 1.48492058 | 15.05992058 | 14.67 | 0.3899205799 | 0.8994687938 | 151.38
0F1QS3S2N4WBXXFVCNNKKRAYDV | 150.69 | 151.47 | 2022-06-14 | 21:41:41 | 1:41:41 | -0.31 | 0.991 | 0.6716790243 | 1.492620054 | 15.06762005 | 14.67 | 0.3976200541 | 0.9172299407 | 151.40
0F1QS62AEF9H9218XX7W8J6M0Y | 150.67 | 151.45 | 2022-06-14 | 21:45:41 | 1:45:41 | -0.33 | 0.971 | 0.668214261 | 1.48492058 | 15.05992058 | 14.67 | 0.3899205799 | 0.8994687938 | 151.38
0F1QS8BE7C0B6239N4E7ZBBWX9 | 150.67 | 151.45 | 2022-06-14 | 21:49:40 | 1:49:40 | -0.33 | 0.971 | 0.668214261 | 1.48492058 | 15.05992058 | 14.67 | 0.3899205799 | 0.8994687938 | 151.38
0F1QSAMP1537KTSNA1F33A57AS | 150.69 | 151.47 | 2022-06-14 | 21:53:40 | 1:53:40 | -0.31 | 0.991 | 0.6716790243 | 1.492620054 | 15.06762005 | 14.67 | 0.3976200541 | 0.9172299407 | 151.40
0F1QSCY0VMGSBGBFZRQAE2TT65 | 150.67 | 151.45 | 2022-06-14 | 21:57:41 | 1:57:41 | -0.33 | 0.971 | 0.668214261 | 1.48492058 | 15.05992058 | 14.67 | 0.3899205799 | 0.8994687938 | 151.38
0F1QSF77VP6T1M4SXQ5S35G00T | 150.67 | 151.45 | 2022-06-14 | 22:01:41 | 2:01:41 | -0.33 | 0.971 | 0.668214261 | 1.48492058 | 15.05992058 | 14.67 | 0.3899205799 | 0.8994687938 | 151.38
0F1QSHGEW8AZV4TBNBXQ5K0PCN | 150.67 | 151.45 | 2022-06-14 | 22:05:41 | 2:05:41 | -0.33 | 0.971 | 0.668214261 | 1.48492058 | 15.05992058 | 14.67 | 0.3899205799 | 0.8994687938 | 151.38
0F1QSKSXKXG4FACEJH337YRD5F | 150.67 | 151.45 | 2022-06-14 | 22:09:41 | 2:09:41 | -0.33 | 0.971 | 0.668214261 | 1.48492058 | 15.05992058 | 14.67 | 0.3899205799 | 0.8994687938 | 151.38
0F1QSP30PREK2YR7PNGWX6P1V9 | 150.67 | 151.45 | 2022-06-14 | 22:13:41 | 2:13:41 | -0.33 | 0.971 | 0.668214261 | 1.48492058 | 15.05992058 | 14.67 | 0.3899205799 | 0.8994687938 | 151.38
0F1QSRC6268360CX8RBE815Z3Y | 150.67 | 151.45 | 2022-06-14 | 22:17:41 | 2:17:41 | -0.33 | 0.971 | 0.668214261 | 1.48492058 | 15.05992058 | 14.67 | 0.3899205799 | 0.8994687938 | 151.38
0F1QSTNC7VCCS73F28JE4SXGGQ | 150.67 | 151.45 | 2022-06-14 | 22:21:40 | 2:21:40 | -0.33 | 0.971 | 0.668214261 | 1.48492058 | 15.05992058 | 14.68 | 0.3799205799 | 0.8764007938 | 151.36
0F1QSWYNJMD387W1N0196T9J1G | 150.67 | 151.45 | 2022-06-14 | 22:25:41 | 2:25:41 | -0.33 | 0.971 | 0.668214261 | 1.48492058 | 15.05992058 | 14.68 | 0.3799205799 | 0.8764007938 | 151.36
0F1QSZ7Y2YY5JRN3RJECTMZANG | 150.67 | 151.45 | 2022-06-14 | 22:29:41 | 2:29:41 | -0.33 | 0.971 | 0.668214261 | 1.48492058 | 15.05992058 | 14.68 | 0.3799205799 | 0.8764007938 | 151.36
0F1QT1H49CHSTATM46C65THWZF | 150.67 | 151.45 | 2022-06-14 | 22:33:41 | 2:33:41 | -0.33 | 0.971 | 0.668214261 | 1.48492058 | 15.05992058 | 14.68 | 0.3799205799 | 0.8764007938 | 151.36
0F1QT3TDKDFQZS0RJG5EZR49FC | 150.67 | 151.45 | 2022-06-14 | 22:37:41 | 2:37:41 | -0.33 | 0.971 | 0.668214261 | 1.48492058 | 15.05992058 | 14.68 | 0.3799205799 | 0.8764007938 | 151.36
0F1QT63MJXT4CX3QDAXVNM68FB | 150.67 | 151.45 | 2022-06-14 | 22:41:41 | 2:41:41 | -0.33 | 0.971 | 0.668214261 | 1.48492058 | 15.05992058 | 14.68 | 0.3799205799 | 0.8764007938 | 151.36
0F1QT8CX3BMEB60F4BZ39G0D76 | 150.67 | 151.45 | 2022-06-14 | 22:45:41 | 2:45:41 | -0.33 | 0.971 | 0.668214261 | 1.48492058 | 15.05992058 | 14.68 | 0.3799205799 | 0.8764007938 | 151.36
0F1QTAP416PFF9M6PPK700T7GX | 150.67 | 151.45 | 2022-06-14 | 22:49:41 | 2:49:41 | -0.33 | 0.971 | 0.668214261 | 1.48492058 | 15.05992058 | 14.68 | 0.3799205799 | 0.8764007938 | 151.36
0F1QTCZDAPKFS8AHM909S9ASAY | 150.67 | 151.45 | 2022-06-14 | 22:53:41 | 2:53:41 | -0.33 | 0.971 | 0.668214261 | 1.48492058 | 15.05992058 | 14.68 | 0.3799205799 | 0.8764007938 | 151.36
0F1QTF8JRDQ70WFQ4Q5NJH23ZN | 150.67 | 151.45 | 2022-06-14 | 22:57:41 | 2:57:41 | -0.33 | 0.971 | 0.668214261 | 1.48492058 | 15.05992058 | 14.68 | 0.3799205799 | 0.8764007938 | 151.36
0F1QTHHV8W2D1B71VSA0GS84M9 | 150.64 | 151.42 | 2022-06-14 | 23:01:41 | 3:01:41 | -0.36 | 0.941 | 0.6630171159 | 1.473371369 | 15.04837137 | 14.68 | 0.3683713687 | 0.8497590734 | 151.33
0F1QTKV71DACPTQBD7X1G4KCH9 | 150.67 | 151.45 | 2022-06-14 | 23:05:41 | 3:05:41 | -0.33 | 0.971 | 0.668214261 | 1.48492058 | 15.05992058 | 14.68 | 0.3799205799 | 0.8764007938 | 151.36
0F1QTP4H0R9ZJR0TD9KWB7BMQ9 | 150.67 | 151.45 | 2022-06-14 | 23:09:41 | 3:09:41 | -0.33 | 0.971 | 0.668214261 | 1.48492058 | 15.05992058 | 14.68 | 0.3799205799 | 0.8764007938 | 151.36
0F1QTRDHTPZVZMKZX3T41WAQ5W | 150.67 | 151.45 | 2022-06-14 | 23:13:40 | 3:13:40 | -0.33 | 0.971 | 0.668214261 | 1.48492058 | 15.05992058 | 14.68 | 0.3799205799 | 0.8764007938 | 151.36
0F1QTTPRPH7X6QJRJNA19YTN8M | 150.67 | 151.45 | 2022-06-14 | 23:17:40 | 3:17:40 | -0.33 | 0.971 | 0.668214261 | 1.48492058 | 15.05992058 | 14.69 | 0.3699205799 | 0.8533327938 | 151.33
0F1QTX021PHPH2Q0BZA058XKE9 | 150.67 | 151.45 | 2022-06-14 | 23:21:41 | 3:21:41 | -0.33 | 0.971 | 0.668214261 | 1.48492058 | 15.05992058 | 14.68 | 0.3799205799 | 0.8764007938 | 151.36
0F1QTZ986RZCQ44B3SG2HN9W3J | 150.64 | 151.42 | 2022-06-14 | 23:25:40 | 3:25:40 | -0.36 | 0.941 | 0.6630171159 | 1.473371369 | 15.04837137 | 14.69 | 0.3583713687 | 0.8266910734 | 151.31
0F1QV1JGRE26VANE0NFH4R8YDC | 150.67 | 151.45 | 2022-06-14 | 23:29:41 | 3:29:41 | -0.33 | 0.971 | 0.668214261 | 1.48492058 | 15.05992058 | 14.69 | 0.3699205799 | 0.8533327938 | 151.33
0F1QV3VPXJYCVHSZZG2WC0RQHM | 150.67 | 151.45 | 2022-06-14 | 23:33:40 | 3:33:40 | -0.33 | 0.971 | 0.668214261 | 1.48492058 | 15.05992058 | 14.69 | 0.3699205799 | 0.8533327938 | 151.33
0F1QV6508K23YEE6P0WZJF6H05 | 150.67 | 151.45 | 2022-06-14 | 23:37:41 | 3:37:41 | -0.33 | 0.971 | 0.668214261 | 1.48492058 | 15.05992058 | 14.69 | 0.3699205799 | 0.8533327938 | 151.33
0F1QV8EDEJTEQ5DVN6KJ885DXS | 150.64 | 151.42 | 2022-06-14 | 23:41:41 | 3:41:41 | -0.36 | 0.941 | 0.6630171159 | 1.473371369 | 15.04837137 | 14.68 | 0.3683713687 | 0.8497590734 | 151.33
0F1QVAQN7F30F77ZE8WW81WDF0 | 150.64 | 151.42 | 2022-06-14 | 23:45:41 | 3:45:41 | -0.36 | 0.941 | 0.6630171159 | 1.473371369 | 15.04837137 | 14.69 | 0.3583713687 | 0.8266910734 | 151.31
0F1QVD0VJP3KB567FZM12A7S29 | 150.64 | 151.42 | 2022-06-14 | 23:49:41 | 3:49:41 | -0.36 | 0.941 | 0.6630171159 | 1.473371369 | 15.04837137 | 14.69 | 0.3583713687 | 0.8266910734 | 151.31
0F1QVF9YEN5185RPKPNP23B2JT | 150.64 | 151.42 | 2022-06-14 | 23:53:40 | 3:53:40 | -0.36 | 0.941 | 0.6630171159 | 1.473371369 | 15.04837137 | 14.68 | 0.3683713687 | 0.8497590734 | 151.33
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

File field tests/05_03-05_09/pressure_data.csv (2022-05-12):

id |  | feed_id | date | time |  |  | value
0F0NM4S50VX3K3744G95AQ6EK7 | 153.01 | 1794775 | 5/3/2022 | 10:58:27 AM | 14:58:30 | UTC | 153.01 | 0
0F0NM778ZT6YJ29SDN1WS446D6 | 153.09 | 1794775 | 5/3/2022 | 11:02:42 AM | 15:02:46 | UTC | 153.09 | 0
0F0NM7PZAJ7N5NQTHC47W7PFFZ | 153.12 | 1794775 | 5/3/2022 | 11:03:34 AM | 15:03:37 | UTC | 153.12 | 0
0F0NMA4S4FKK5X24CGH8P9DR20 | 153.12 | 1794775 | 5/3/2022 | 11:07:49 AM | 15:07:52 | UTC | 153.12 | 0
0F0NMCC022KWT0ZRA8JDBR6H4S | 153.12 | 1794775 | 5/3/2022 | 11:11:42 AM | 15:11:45 | UTC | 153.12 | 0
0F0NMEMET3ZCJVNTS8WVAYCKJJ | 153.12 | 1794775 | 5/3/2022 | 11:15:40 AM | 15:15:43 | UTC | 153.12 | 0
0F0NMGXX07V62XDFR1RS785052 | 153.12 | 1794775 | 5/3/2022 | 11:19:40 AM | 15:19:44 | UTC | 153.12 | 0
0F0NMK6XGF462M2W4XGKRZ92FG | 153.12 | 1794775 | 5/3/2022 | 11:23:40 AM | 15:23:43 | UTC | 153.12 | 0
0F0NMNG4JK2VRXZ86WFCZS0Y11 | 153.12 | 1794775 | 5/3/2022 | 11:27:40 AM | 15:27:43 | UTC | 153.12 | 0
0F0NMQSGXMFGSHGC2J19MR7J3R | 153.12 | 1794775 | 5/3/2022 | 11:31:40 AM | 15:31:43 | UTC | 153.12 | 0
0F0NMT2Q3MCWVYYNPHZJ7SGPWS | 153.09 | 1794775 | 5/3/2022 | 11:35:40 AM | 15:35:43 | UTC | 153.09 | 0
0F0NMWC21DFESC6Z1T1TXHVRM4 | 153.09 | 1794775 | 5/3/2022 | 11:39:40 AM | 15:39:43 | UTC | 153.09 | 0
0F0NMYN6M2VWKR5J20NE51P7DC | 153.06 | 1794775 | 5/3/2022 | 11:43:40 AM | 15:43:43 | UTC | 153.06 | 0
0F0NN0YF4F4S1R4GF0364R85NT | 153.03 | 1794775 | 5/3/2022 | 11:47:40 AM | 15:47:43 | UTC | 153.03 | 0
0F0NN37MHXBP02WVQBM3XPQREF | 153.03 | 1794775 | 5/3/2022 | 11:51:40 AM | 15:51:43 | UTC | 153.03 | 0
0F0NN5H0ZKQ19MZ1RWY6KDSFY2 | 153.06 | 1794775 | 5/3/2022 | 11:55:40 AM | 15:55:43 | UTC | 153.06 | 0
0F0NN7TAASSYRXF5CW7X36Q2ME | 153.01 | 1794775 | 5/3/2022 | 11:59:40 AM | 15:59:44 | UTC | 153.01 | 0
0F0NNA3BSDHWQ23M2X836WQ5MW | 153.01 | 1794775 | 5/3/2022 | 12:03:40 PM | 16:03:43 | UTC | 153.01 | 0
0F0NNCCZ9CHQJHCQKJXAG2RYK5 | 153.01 | 1794775 | 5/3/2022 | 12:07:41 PM | 16:07:44 | UTC | 153.01 | 0
0F0NNENXPD6QSYYAZHSKABYSY6 | 153.01 | 1794775 | 5/3/2022 | 12:11:40 PM | 16:11:43 | UTC | 153.01 | 0
0F0NNGZ3V7AYGKFH3ENWW3Y0GT | 153.01 | 1794775 | 5/3/2022 | 12:15:40 PM | 16:15:43 | UTC | 153.01 | 0
0F0NNK8DYPMHYCZ06FDZ57G52C | 152.98 | 1794775 | 5/3/2022 | 12:19:40 PM | 16:19:43 | UTC | 152.98 | 0
0F0NNNHQBZXQQGZGXPWS0V0SNB | 152.98 | 1794775 | 5/3/2022 | 12:23:40 PM | 16:23:43 | UTC | 152.98 | 0
0F0NNQTSGF25HAR49CA9G4H1HJ | 152.98 | 1794775 | 5/3/2022 | 12:27:40 PM | 16:27:43 | UTC | 152.98 | 0
0F0NNT45746ZCX5S8BD7K6AQTB | 152.95 | 1794775 | 5/3/2022 | 12:31:40 PM | 16:31:43 | UTC | 152.95 | 0
0F0NNWD9S4E3XJH4CCBAS137X6 | 152.95 | 1794775 | 5/3/2022 | 12:35:40 PM | 16:35:43 | UTC | 152.95 | 0
0F0NNYPR0KX1ZZVZ5BZZ90Y1J4 | 152.92 | 1794775 | 5/3/2022 | 12:39:40 PM | 16:39:44 | UTC | 152.92 | 0
0F0NP10ESVD6W9PWJD098MNKR6 | 152.92 | 1794775 | 5/3/2022 | 12:43:40 PM | 16:43:45 | UTC | 152.92 | 0
0F0NP392R1MJRQBSTFCMW4EQD4 | 152.95 | 1794775 | 5/3/2022 | 12:47:40 PM | 16:47:43 | UTC | 152.95 | 0
0F0NP5JDFZR766JSR3429X432Q | 152.95 | 1794775 | 5/3/2022 | 12:51:40 PM | 16:51:43 | UTC | 152.95 | 0
0F0NP7VRC9XJB8CS617Y7F9ER2 | 152.92 | 1794775 | 5/3/2022 | 12:55:41 PM | 16:55:44 | UTC | 152.92 | 0
0F0NPA4RA23PE22B4DS1KFPNJE | 152.92 | 1794775 | 5/3/2022 | 12:59:40 PM | 16:59:43 | UTC | 152.92 | 0
0F0NPCE4627GX0GZTNSVJF4SQH | 152.92 | 1794775 | 5/3/2022 | 1:03:40 PM | 17:03:43 | UTC | 152.92 | 0
0F0NPEQE1HS668T4WTQJ8YR5JK | 152.92 | 1794775 | 5/3/2022 | 1:07:40 PM | 17:07:44 | UTC | 152.92 | 0
0F0NPH0GB23ZQ8T29KT9CWSRH1 | 152.92 | 1794775 | 5/3/2022 | 1:11:40 PM | 17:11:43 | UTC | 152.92 | 0
0F0NPK9RVKC056SGP83WRXZF97 | 152.92 | 1794775 | 5/3/2022 | 1:15:40 PM | 17:15:43 | UTC | 152.92 | 0
0F0NPNK28NM2ESJWV0YE1TZ67E | 152.92 | 1794775 | 5/3/2022 | 1:19:40 PM | 17:19:43 | UTC | 152.92 | 0
0F0NPQW7JJ63YHZ68JBSBKS28N | 152.89 | 1794775 | 5/3/2022 | 1:23:40 PM | 17:23:43 | UTC | 152.89 | 0
0F0NPT5FD4Y4NYHCSDFQ08VMJ1 | 152.86 | 1794775 | 5/3/2022 | 1:27:40 PM | 17:27:43 | UTC | 152.86 | 0
0F0NPWERMSPP2WQMHD9BD79PDP | 152.86 | 1794775 | 5/3/2022 | 1:31:40 PM | 17:31:43 | UTC | 152.86 | 0
0F0NPYR165F48VCCAT75320SX6 | 152.86 | 1794775 | 5/3/2022 | 1:35:40 PM | 17:35:43 | UTC | 152.86 | 0
0F0NQ119PCKRM9QPPEZR76779M | 152.86 | 1794775 | 5/3/2022 | 1:39:40 PM | 17:39:43 | UTC | 152.86 | 0
0F0NQ3AHJ9SCBFNB15GDCZ0YQQ | 152.84 | 1794775 | 5/3/2022 | 1:43:40 PM | 17:43:43 | UTC | 152.84 | 0
0F0NQ5KQM3E8YBQ6D067Q22VHD | 152.84 | 1794775 | 5/3/2022 | 1:47:40 PM | 17:47:43 | UTC | 152.84 | 0
0F0NQ7X4VW7TM8M7EVG1JC9Y8F | 152.84 | 1794775 | 5/3/2022 | 1:51:41 PM | 17:51:44 | UTC | 152.84 | 0
0F0NQA68PFSHKP0KT5ZSP4J75C | 152.84 | 1794775 | 5/3/2022 | 1:55:40 PM | 17:55:43 | UTC | 152.84 | 0
0F0NQCFE42GDTGEQPGJ9R7CSR9 | 152.84 | 1794775 | 5/3/2022 | 1:59:40 PM | 17:59:43 | UTC | 152.84 | 0
0F0NQERN2FQYQ3PMXW5KA1EA42 | 152.81 | 1794775 | 5/3/2022 | 2:03:40 PM | 18:03:43 | UTC | 152.81 | 0
0F0NQH36878VDM1795XT71MZDS | 152.84 | 1794775 | 5/3/2022 | 2:07:43 PM | 18:07:47 | UTC | 152.84 | 0
0F0NQKB5BGRKCYNM5ZHH27TS6A | 152.84 | 1794775 | 5/3/2022 | 2:11:40 PM | 18:11:43 | UTC | 152.84 | 0
0F0NQNMBJD21YVAQBH21SSE8RQ | 152.84 | 1794775 | 5/3/2022 | 2:15:40 PM | 18:15:43 | UTC | 152.84 | 0
0F0NQQXM37AZD2S8JGJ94RC2X2 | 152.84 | 1794775 | 5/3/2022 | 2:19:40 PM | 18:19:43 | UTC | 152.84 | 0
0F0NQT6V2RDGESKYN0NF6AEQVE | 152.84 | 1794775 | 5/3/2022 | 2:23:40 PM | 18:23:43 | UTC | 152.84 | 0
0F0NQWG3JC79KDF4Z4S1R6Q0CS | 152.81 | 1794775 | 5/3/2022 | 2:27:40 PM | 18:27:43 | UTC | 152.81 | 0
0F0NQYSQVV9SS3J8MD0WZ2TT77 | 152.84 | 1794775 | 5/3/2022 | 2:31:41 PM | 18:31:44 | UTC | 152.84 | 0
0F0NR12NG3B4FCVYSNNJPYY5J2 | 152.84 | 1794775 | 5/3/2022 | 2:35:40 PM | 18:35:43 | UTC | 152.84 | 0
0F0NR3BTYC85MX544SKYCJ8HM6 | 152.84 | 1794775 | 5/3/2022 | 2:39:40 PM | 18:39:43 | UTC | 152.84 | 0
0F0NR5N4XEMN4FK0973QEYEHMG | 152.84 | 1794775 | 5/3/2022 | 2:43:40 PM | 18:43:43 | UTC | 152.84 | 0
0F0NR7YKRM71TB8X6JBF2W2HWG | 152.81 | 1794775 | 5/3/2022 | 2:47:41 PM | 18:47:44 | UTC | 152.81 | 0
0F0NRA7J2BAT6GD49CH1E1BR9Y | 152.84 | 1794775 | 5/3/2022 | 2:51:40 PM | 18:51:43 | UTC | 152.84 | 0
0F0NRCGR9AS1TBSZ53GYVXZKPA | 152.84 | 1794775 | 5/3/2022 | 2:55:40 PM | 18:55:43 | UTC | 152.84 | 0
0F0NRET4PH2TTAE5503C9J25YC | 152.84 | 1794775 | 5/3/2022 | 2:59:40 PM | 18:59:43 | UTC | 152.84 | 0
0F0NRH3B01GVW7KACS8FE2N6CD | 152.89 | 1794775 | 5/3/2022 | 3:03:40 PM | 19:03:43 | UTC | 152.89 | 0
0F0NRKCFGT6JNJJP7781YH35RD | 152.84 | 1794775 | 5/3/2022 | 3:07:40 PM | 19:07:43 | UTC | 152.84 | 0
0F0NRNNTDG2K136V1J2P58VCJH | 152.84 | 1794775 | 5/3/2022 | 3:11:40 PM | 19:11:43 | UTC | 152.84 | 0
0F0NRQZ9YG6X7DMP52YGW1VE8N | 152.86 | 1794775 | 5/3/2022 | 3:15:41 PM | 19:15:44 | UTC | 152.86 | 0
0F0NRT88BGPG6Q986P4B6DZ124 | 152.75 | 1794775 | 5/3/2022 | 3:19:40 PM | 19:19:43 | UTC | 152.75 | 0
0F0NRWHG2C415A9MGR937QJ5AV | 152.27 | 1794775 | 5/3/2022 | 3:23:40 PM | 19:23:43 | UTC | 152.27 | 0
0F0NRYTWHAZF9W060E8D6G7TCJ | 151.96 | 1794775 | 5/3/2022 | 3:27:40 PM | 19:27:43 | UTC | 151.96 | 0
0F0NS1485PY186C3YH4N4J6DA6 | 152.55 | 1794775 | 5/3/2022 | 3:31:41 PM | 19:31:44 | UTC | 152.55 | 0
0F0NS3DAF222948WJBKT3XD34S | 152.61 | 1794775 | 5/3/2022 | 3:35:40 PM | 19:35:43 | UTC | 152.61 | 0
0F0NS5PF2EC5270KPK4FZEKKV1 | 152.64 | 1794775 | 5/3/2022 | 3:39:40 PM | 19:39:43 | UTC | 152.64 | 0
0F0NS7ZQM6JGQ80SN15VZ60HD6 | 152.64 | 1794775 | 5/3/2022 | 3:43:40 PM | 19:43:43 | UTC | 152.64 | 0
0F0NSA90525SE10H0V78N74HXT | 152.64 | 1794775 | 5/3/2022 | 3:47:40 PM | 19:47:43 | UTC | 152.64 | 0
0F0NSCJ7Y52HA8JV654BAHNYPM | 152.61 | 1794775 | 5/3/2022 | 3:51:40 PM | 19:51:43 | UTC | 152.61 | 0
0F0NSEVEWBQH8K3591HHESS4FA | 152.64 | 1794775 | 5/3/2022 | 3:55:40 PM | 19:55:43 | UTC | 152.64 | 0
0F0NSH4N2F9RK3RM2C7BDEXX6Q | 152.64 | 1794775 | 5/3/2022 | 3:59:40 PM | 19:59:43 | UTC | 152.64 | 0
0F0NSKDWSVD5SPT728E4ZDGWFK | 152.61 | 1794775 | 5/3/2022 | 4:03:40 PM | 20:03:43 | UTC | 152.61 | 0
0F0NSNQ6459N4537DKTR9EVHWF | 152.61 | 1794775 | 5/3/2022 | 4:07:40 PM | 20:07:43 | UTC | 152.61 | 0
0F0NSR0DVNH9X0T44WA660RERA | 152.64 | 1794775 | 5/3/2022 | 4:11:40 PM | 20:11:43 | UTC | 152.64 | 0
0F0NST9NRP3PDFWDKA0EK9KQJT | 152.64 | 1794775 | 5/3/2022 | 4:15:40 PM | 20:15:43 | UTC | 152.64 | 0
0F0NSWSDCHXTHCBPT6C6T2MK1B | 152.64 | 1794775 | 5/3/2022 | 4:20:04 PM | 20:20:04 | UTC | 152.64 | 0
0F0NSX6P104E1384GKACYSM65P | 152.61 | 1794775 | 5/3/2022 | 4:20:45 PM | 20:20:48 | UTC | 152.61 | 0
0F0NSZEF2A9HPQ7FKM7MT6Q42B | 152.61 | 1794775 | 5/3/2022 | 4:24:40 PM | 20:24:43 | UTC | 152.61 | 0
0F0NT1QNB2EKK9WAC6AWHQD71D | 152.58 | 1794775 | 5/3/2022 | 4:28:40 PM | 20:28:43 | UTC | 152.58 | 0
0F0NT40W7D8GNVFRYBG1TPARFB | 152.58 | 1794775 | 5/3/2022 | 4:32:40 PM | 20:32:43 | UTC | 152.58 | 0
0F0NTAYN4AH2BC0RF8RWQNBAW3 | 152.5 | 1794775 | 5/3/2022 | 4:44:46 PM | 20:44:50 | UTC | 152.5 | 0
0F0NVTN8NJWKSF9RRD8Z9BH88F | 152.53 | 1794775 | 5/3/2022 | 6:08:09 PM | 22:08:12 | UTC | 152.53 | 0
0F0NVWP569BB1TYSY9SRK7V9A3 | 152.58 | 1794775 | 5/3/2022 | 6:11:41 PM | 22:11:45 | UTC | 152.58 | 0
0F0NVYZ184BHKP3HQ9A9Z77ZSX | 152.75 | 1794775 | 5/3/2022 | 6:15:40 PM | 22:15:43 | UTC | 152.75 | 0
0F0NW18HJB342A824CWSXRV7VN | 152.86 | 1794775 | 5/3/2022 | 6:19:41 PM | 22:19:44 | UTC | 152.86 | 0
0F0NW3PC8F1YFF8E8XRAG5DDVZ | 152.92 | 1794775 | 5/3/2022 | 6:23:56 PM | 22:23:59 | UTC | 152.92 | 0
0F0NW5TMMQ94DNY4RBFG7VH595 | 152.95 | 1794775 | 5/3/2022 | 6:27:40 PM | 22:27:43 | UTC | 152.95 | 0
0F0NW83TRZW82YG33K8A5KK3WN | 153.01 | 1794775 | 5/3/2022 | 6:31:40 PM | 22:31:43 | UTC | 153.01 | 0
0F0NWAD1RZCCN33HVC02AM4M6T | 153.06 | 1794775 | 5/3/2022 | 6:35:40 PM | 22:35:43 | UTC | 153.06 | 0
0F0NWCPCN1JFP7CZA5VD5NPE2W | 153.09 | 1794775 | 5/3/2022 | 6:39:40 PM | 22:39:43 | UTC | 153.09 | 0
0F0NWEZGGB6HXT54VPKWRE0JRH | 153.12 | 1794775 | 5/3/2022 | 6:43:39 PM | 22:43:43 | UTC | 153.12 | 0
0F0NWH8TN2G7HVV9GMXBWXKBS9 | 153.15 | 1794775 | 5/3/2022 | 6:47:40 PM | 22:47:43 | UTC | 153.15 | 0
0F0NWKJ4MJ9BNX58YPEFJ0WW0N | 153.15 | 1794775 | 5/3/2022 | 6:51:40 PM | 22:51:43 | UTC | 153.15 | 0
0F0NWNVNRTR8JQYH66JVN45JK7 | 153.17 | 1794775 | 5/3/2022 | 6:55:40 PM | 22:55:44 | UTC | 153.17 | 0
0F0NWR4KHBSJBSP0Y2Y1MCXH9J | 153.2 | 1794775 | 5/3/2022 | 6:59:40 PM | 22:59:43 | UTC | 153.2 | 0
0F0NWTDSQEMBMGHBK56JNNWB3W | 153.2 | 1794775 | 5/3/2022 | 7:03:40 PM | 23:03:43 | UTC | 153.2 | 0
0F0NWWPYZPGGM14BA0TV9P4RVW | 153.23 | 1794775 | 5/3/2022 | 7:07:39 PM | 23:07:43 | UTC | 153.23 | 0
0F0NWZ0AMNWRY58WMX17XAJDGF | 153.23 | 1794775 | 5/3/2022 | 7:11:40 PM | 23:11:43 | UTC | 153.23 | 0
0F0NX19G0K9WW27TEGHGPHF5S6 | 153.23 | 1794775 | 5/3/2022 | 7:15:40 PM | 23:15:43 | UTC | 153.23 | 0
0F0NX3JQ0ZMDKNT7KV749VDCGP | 153.23 | 1794775 | 5/3/2022 | 7:19:40 PM | 23:19:43 | UTC | 153.23 | 0
0F0NX5VYQM0PYY9BT4CYQ6HDK0 | 153.26 | 1794775 | 5/3/2022 | 7:23:40 PM | 23:23:43 | UTC | 153.26 | 0
0F0NX859M2WH07CQARWVESD6XT | 153.26 | 1794775 | 5/3/2022 | 7:27:40 PM | 23:27:43 | UTC | 153.26 | 0
0F0NXAEHBVW6564PH8DHSG677V | 153.26 | 1794775 | 5/3/2022 | 7:31:40 PM | 23:31:43 | UTC | 153.26 | 0
0F0NXCQN6ZJ7F67X99H1W5S372 | 153.29 | 1794775 | 5/3/2022 | 7:35:39 PM | 23:35:43 | UTC | 153.29 | 0
0F0NXF0ZC2CC01B62WDXNQMKN1 | 153.32 | 1794775 | 5/3/2022 | 7:39:40 PM | 23:39:43 | UTC | 153.32 | 0
0F0NXHA8MSKACDYBEN6987G9G5 | 153.32 | 1794775 | 5/3/2022 | 7:43:40 PM | 23:43:43 | UTC | 153.32 | 0
0F0NXKKE32MEHNB2CWBG5MG72S | 153.32 | 1794775 | 5/3/2022 | 7:47:40 PM | 23:47:43 | UTC | 153.32 | 0
0F0NXNX3257C10SX5X57PTRGMP | 153.34 | 1794775 | 5/3/2022 | 7:51:40 PM | 23:51:44 | UTC | 153.34 | 0
0F0NXR5VYENPWWNR66V7X1DCYK | 153.37 | 1794775 | 5/3/2022 | 7:55:39 PM | 23:55:43 | UTC | 153.37 | 0
0F0NXTF6VJRBD65A23PDTHQ8K6 | 153.37 | 1794775 | 5/3/2022 | 7:59:40 PM | 23:59:43 | UTC | 153.37 | 0
0F0NXWRFBMQQBKR755A2XY1JFN | 153.37 | 1794775 | 5/3/2022 | 8:03:40 PM | 0:03:43 | UTC | 153.37 | 0
0F0NXZ1MWA8BFTET8V2Z8TPYEJ | 153.4 | 1794775 | 5/3/2022 | 8:07:40 PM | 0:07:43 | UTC | 153.4 | 0
0F0NY1B0G4VACH2ZXEW55PRJYB | 153.4 | 1794775 | 5/3/2022 | 8:11:40 PM | 0:11:43 | UTC | 153.4 | 0
0F0NY3M7G37KNGSVJCZ904EAV2 | 153.43 | 1794775 | 5/3/2022 | 8:15:40 PM | 0:15:43 | UTC | 153.43 | 0
0F0NY5XEEDME2J7FHK6205M3EK | 153.43 | 1794775 | 5/3/2022 | 8:19:40 PM | 0:19:43 | UTC | 153.43 | 0
0F0NY86NBQM4T8SQWAFKFRC422 | 153.43 | 1794775 | 5/3/2022 | 8:23:40 PM | 0:23:43 | UTC | 153.43 | 0
0F0NYAG9MYERQJEJYT74EJ8QPE | 153.46 | 1794775 | 5/3/2022 | 8:27:41 PM | 0:27:44 | UTC | 153.46 | 0
0F0NYCSDEPRD4PBPHMNPCE3R9Q | 153.46 | 1794775 | 5/3/2022 | 8:31:41 PM | 0:31:44 | UTC | 153.46 | 0
0F0NYF2BTCSBJ93357N2AS3D5Z | 153.46 | 1794775 | 5/3/2022 | 8:35:40 PM | 0:35:43 | UTC | 153.46 | 0
0F0NYHBN9R3J0QH7GXSX0DJCNJ | 153.49 | 1794775 | 5/3/2022 | 8:39:40 PM | 0:39:43 | UTC | 153.49 | 0
0F0NYKMSQXTCACNEY5NN40KNHP | 153.46 | 1794775 | 5/3/2022 | 8:43:40 PM | 0:43:43 | UTC | 153.46 | 0
0F0NYNY5DPVSKW7EMY5D9S2JSX | 153.49 | 1794775 | 5/3/2022 | 8:47:40 PM | 0:47:43 | UTC | 153.49 | 0
0F0NYR7A13NB5NEWK5AEE3JE6H | 153.49 | 1794775 | 5/3/2022 | 8:51:40 PM | 0:51:43 | UTC | 153.49 | 0
0F0NYTGKB3D2B7KKTY053739QR | 153.49 | 1794775 | 5/3/2022 | 8:55:40 PM | 0:55:43 | UTC | 153.49 | 0
0F0NYWT0MXN3J90V53353S8948 | 153.49 | 1794775 | 5/3/2022 | 8:59:40 PM | 0:59:44 | UTC | 153.49 | 0
0F0NYZ32YJVRZ82XX9H4WRD7XS | 153.49 | 1794775 | 5/3/2022 | 9:03:40 PM | 1:03:43 | UTC | 153.49 | 0
0F0NZ1CAKVXNJJDWRYAMCXC1B9 | 153.49 | 1794775 | 5/3/2022 | 9:07:40 PM | 1:07:43 | UTC | 153.49 | 0
0F0NZ3NHJGMBBYJPWKVY723XS0 | 153.51 | 1794775 | 5/3/2022 | 9:11:40 PM | 1:11:43 | UTC | 153.51 | 0
0F0NZ5Z13EJ05CAYTT0P45SZ13 | 153.51 | 1794775 | 5/3/2022 | 9:15:40 PM | 1:15:44 | UTC | 153.51 | 0
0F0NZ87YQYSWRX4G4N9CBHW1ZQ | 153.51 | 1794775 | 5/3/2022 | 9:19:39 PM | 1:19:43 | UTC | 153.51 | 0
0F0NZAH9J5V25K571HNED0BG8S | 153.51 | 1794775 | 5/3/2022 | 9:23:40 PM | 1:23:43 | UTC | 153.51 | 0
0F0NZCTGN5KJ1PCKFS2TN6BNAQ | 153.51 | 1794775 | 5/3/2022 | 9:27:40 PM | 1:27:43 | UTC | 153.51 | 0
0F0NZF3S2C5ZGEZ2NC76VF689C | 153.51 | 1794775 | 5/3/2022 | 9:31:40 PM | 1:31:43 | UTC | 153.51 | 0
0F0NZHCYGA8G87D1EZN0K5DZTB | 153.51 | 1794775 | 5/3/2022 | 9:35:40 PM | 1:35:43 | UTC | 153.51 | 0
0F0NZKP7WXDM30KJTXMSPFRF1J | 153.51 | 1794775 | 5/3/2022 | 9:39:40 PM | 1:39:43 | UTC | 153.51 | 0
0F0NZNZN3DEZKF9PHCQ5JPSVQW | 153.54 | 1794775 | 5/3/2022 | 9:43:40 PM | 1:43:43 | UTC | 153.54 | 0
0F0NZR8Q9XF7TWVXBXXJ6DWYB1 | 153.54 | 1794775 | 5/3/2022 | 9:47:40 PM | 1:47:43 | UTC | 153.54 | 0
0F0NZTHY9KSPSE25D6ZJJKH023 | 153.54 | 1794775 | 5/3/2022 | 9:51:40 PM | 1:51:43 | UTC | 153.54 | 0
0F0NZWV6T0GW31651XZ1WS6BH0 | 153.57 | 1794775 | 5/3/2022 | 9:55:40 PM | 1:55:43 | UTC | 153.57 | 0
0F0NZZ4C8JM529MN5YBYT30H9B | 153.54 | 1794775 | 5/3/2022 | 9:59:39 PM | 1:59:43 | UTC | 153.54 | 0
0F0P01DT7FV8V1RB0R3GE5GQHF | 153.57 | 1794775 | 5/3/2022 | 10:03:40 PM | 2:03:43 | UTC | 153.57 | 0
0F0P03PYVJHD0MVAKRPFD13WET | 153.54 | 1794775 | 5/3/2022 | 10:07:40 PM | 2:07:43 | UTC | 153.54 | 0
0F0P0603HPSNMXG70742QBH7XV | 153.57 | 1794775 | 5/3/2022 | 10:11:39 PM | 2:11:43 | UTC | 153.57 | 0
0F0P089C0AYWCKWVXTZW1EFJSZ | 153.57 | 1794775 | 5/3/2022 | 10:15:40 PM | 2:15:43 | UTC | 153.57 | 0
0F0P0AJZEMP30SBCPR4TFTYABM | 153.57 | 1794775 | 5/3/2022 | 10:19:40 PM | 2:19:44 | UTC | 153.57 | 0
0F0P0CVVPF5JVB3CRGMPCS9D68 | 153.57 | 1794775 | 5/3/2022 | 10:23:40 PM | 2:23:43 | UTC | 153.57 | 0
0F0P0F52J02WTYAHPGKS82NDKH | 153.57 | 1794775 | 5/3/2022 | 10:27:39 PM | 2:27:43 | UTC | 153.57 | 0
0F0P0HECK1T1BPBY3NSDWXXRJM | 153.57 | 1794775 | 5/3/2022 | 10:31:40 PM | 2:31:43 | UTC | 153.57 | 0
0F0P0KQJQ9KFEG1PEAVSMKS6MJ | 153.6 | 1794775 | 5/3/2022 | 10:35:40 PM | 2:35:43 | UTC | 153.6 | 0
0F0P0P0TG3G002HWYN6H1AK0T1 | 153.6 | 1794775 | 5/3/2022 | 10:39:40 PM | 2:39:43 | UTC | 153.6 | 0
0F0P0RA5CDF785DHQ8BE29835G | 153.6 | 1794775 | 5/3/2022 | 10:43:40 PM | 2:43:43 | UTC | 153.6 | 0
0F0P0TKBJCW0R8P3QA8RY1YPCE | 153.6 | 1794775 | 5/3/2022 | 10:47:40 PM | 2:47:43 | UTC | 153.6 | 0
0F0P0WWGYAQWV4S6ZSE39XJEEA | 153.6 | 1794775 | 5/3/2022 | 10:51:39 PM | 2:51:43 | UTC | 153.6 | 0
0F0P0Z5WPVHHBQJ98NA3JZKJYR | 153.6 | 1794775 | 5/3/2022 | 10:55:40 PM | 2:55:43 | UTC | 153.6 | 0
0F0P11F7FHRD8DC44VDD6F814D | 153.6 | 1794775 | 5/3/2022 | 10:59:40 PM | 2:59:43 | UTC | 153.6 | 0
0F0P13R908NK98P7VQPE2NK81N | 153.6 | 1794775 | 5/3/2022 | 11:03:40 PM | 3:03:43 | UTC | 153.6 | 0
0F0P161JCTN30P0V4GQM8R8WRN | 153.6 | 1794775 | 5/3/2022 | 11:07:40 PM | 3:07:43 | UTC | 153.6 | 0
0F0P18ATWRSY4ZH97VP6NF76FP | 153.63 | 1794775 | 5/3/2022 | 11:11:40 PM | 3:11:43 | UTC | 153.63 | 0
0F0P1AM1T15KVT2TNN77F88QRP | 153.63 | 1794775 | 5/3/2022 | 11:15:40 PM | 3:15:43 | UTC | 153.63 | 0
0F0P1CX80KZ28B5A4ZDKFP5PEE | 153.63 | 1794775 | 5/3/2022 | 11:19:40 PM | 3:19:43 | UTC | 153.63 | 0
0F0P1F6J5FVC2PNXBP080DHJ5V | 153.6 | 1794775 | 5/3/2022 | 11:23:40 PM | 3:23:43 | UTC | 153.6 | 0
0F0P1HFS2H35KS8PC778DX70VB | 153.6 | 1794775 | 5/3/2022 | 11:27:40 PM | 3:27:43 | UTC | 153.6 | 0
0F0P1KS0T7QHTXM6ERGGDHNV2S | 153.63 | 1794775 | 5/3/2022 | 11:31:40 PM | 3:31:43 | UTC | 153.63 | 0
0F0P1P2675DCXZ0SS6KHWXPBZ2 | 153.63 | 1794775 | 5/3/2022 | 11:35:39 PM | 3:35:43 | UTC | 153.63 | 0
0F0P1RBE1599FJ8GEVX15D7FWA | 153.63 | 1794775 | 5/3/2022 | 11:39:39 PM | 3:39:43 | UTC | 153.63 | 0
0F0P1TMPG8W92EP9BMNKQA683C | 153.63 | 1794775 | 5/3/2022 | 11:43:40 PM | 3:43:43 | UTC | 153.63 | 0
0F0P1WXY7QC7TWACHAWCNGTMFK | 153.63 | 1794775 | 5/3/2022 | 11:47:40 PM | 3:47:43 | UTC | 153.63 | 0
0F0P1Z75726XAS6EQ788NNCVP9 | 153.63 | 1794775 | 5/3/2022 | 11:51:39 PM | 3:51:43 | UTC | 153.63 | 0
0F0P21GFC23FSKJ7EWSQ2ZRYT4 | 153.65 | 1794775 | 5/3/2022 | 11:55:40 PM | 3:55:43 | UTC | 153.65 | 0
0F0P23SMRB0HCJHETJM1YR3QYF | 153.63 | 1794775 | 5/3/2022 | 11:59:39 PM | 3:59:43 | UTC | 153.63 | 0
0F0P262YSJXN4PW1G8KSQ129K2 | 153.63 | 1794775 | 5/4/2022 | 12:03:40 AM | 4:03:43 | UTC | 153.63 | 0
0F0P28C52RVD9XMSP4ADD0ZPJ9 | 153.63 | 1794775 | 5/4/2022 | 12:07:40 AM | 4:07:43 | UTC | 153.63 | 0
0F0P2ANE9BZY3WM293S80F2SBA | 153.63 | 1794775 | 5/4/2022 | 12:11:40 AM | 4:11:43 | UTC | 153.63 | 0
0F0P2CYP29P3VA85P3TK22QJQV | 153.63 | 1794775 | 5/4/2022 | 12:15:40 AM | 4:15:43 | UTC | 153.63 | 0
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

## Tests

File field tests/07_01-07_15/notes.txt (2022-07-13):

Deployed on Spring lake dam

Initial sea level: 178.9 but read as 178

** BATTERY CHANGES **
7/5/22: changed out small lipo battery, sea level was 178.16 + 0.9

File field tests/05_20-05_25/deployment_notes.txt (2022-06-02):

----------------------------------------------------------------
Deployment Dates: May 20 2022 11:07 - May 25 2022 10:51
Deployment Location: Clemson Sandhills Dam
Rain event?: Yes, May 21
Cause of failure: small LiPo battery discharged
----------------------------------------------------------------
Notes:
- Solar panel was effective in charging the 12V battery back to full each day
- Solar panel was mounted in full sun
- Package and solar panel mounted on primary spillway
- Temperature exceeded 100F, at which point the temperature sensor stopped sending data to Adafruit, even though other sensors would

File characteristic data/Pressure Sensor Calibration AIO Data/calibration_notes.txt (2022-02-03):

- The offset tends to change, but the slope remains relativley constant at 0.027
- one way to address this is to not let the sensor get dry
- if we put the sensor in water and set the initial elevation, then we only have to care about the change 
   in water depth, i.e. the slope

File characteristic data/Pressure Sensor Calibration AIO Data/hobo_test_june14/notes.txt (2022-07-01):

This HOBO sensor system was deployed with the DHEC sensor from June 14 - June 26 2022. 
The primary purpose is to determine a function to calibrate the pressure transducer.
Data from the DHEC sensor is found in field_tests/06_14-06_26

HOBO sensor serial numbers: 
Wet sensor SN: 1181041
Dry sensor SN: 1181936

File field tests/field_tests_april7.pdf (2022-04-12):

# Field Tests

### Corinne Smith

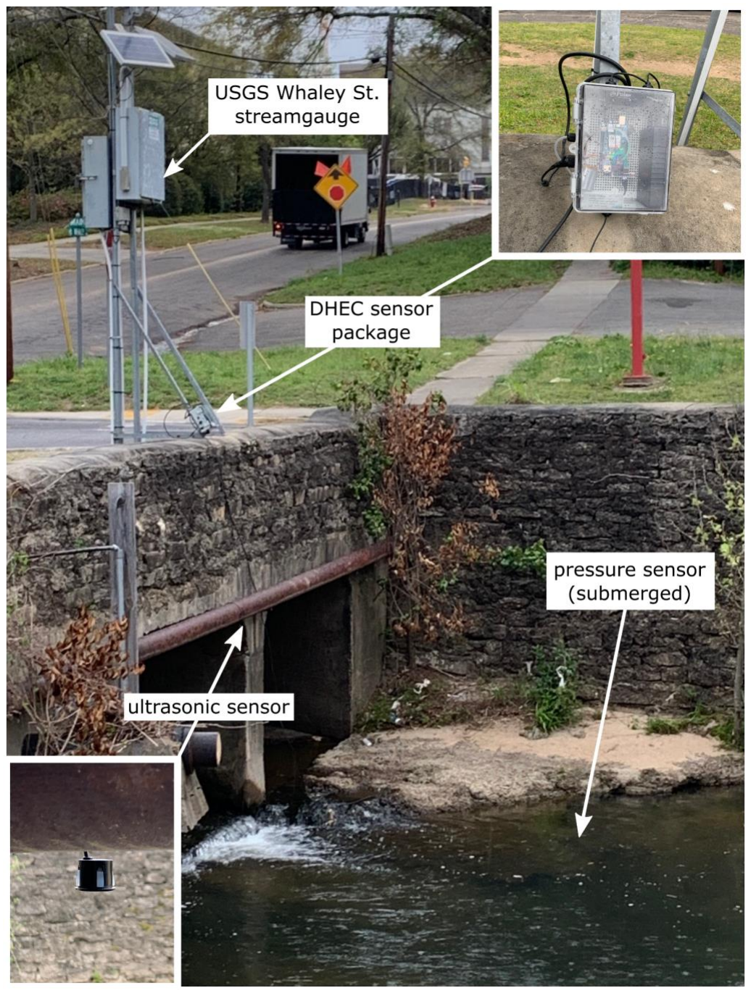
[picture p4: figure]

3/31

- Fixed on USGS Whaley St streamgage
- Ultrasonic sensor was fixed to the pipe, pressure sensor was not fixed
- Caused problems to pressure sensor when the flow rate picked up
- Solution: deploy pressure sensor to the side of the main flow
- Data session: 9:00 – 18:32
- Cause of failure: network would not reconnect, so Adafruit IO was completely unresponsive
- Possibly encountered a Network Denied status
- Ultrasonic had noisy readings between major rainfall periods
- Possible something was stuck under the sensor that gave false readings

## Results

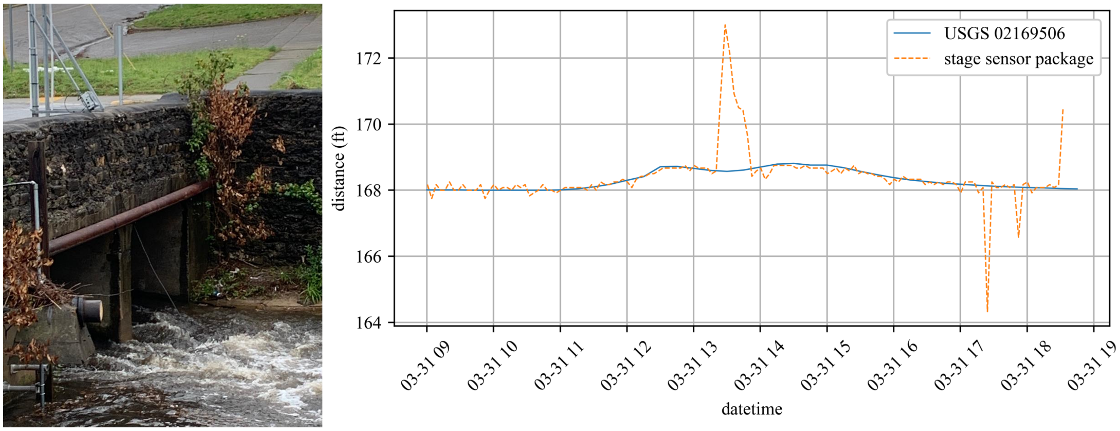
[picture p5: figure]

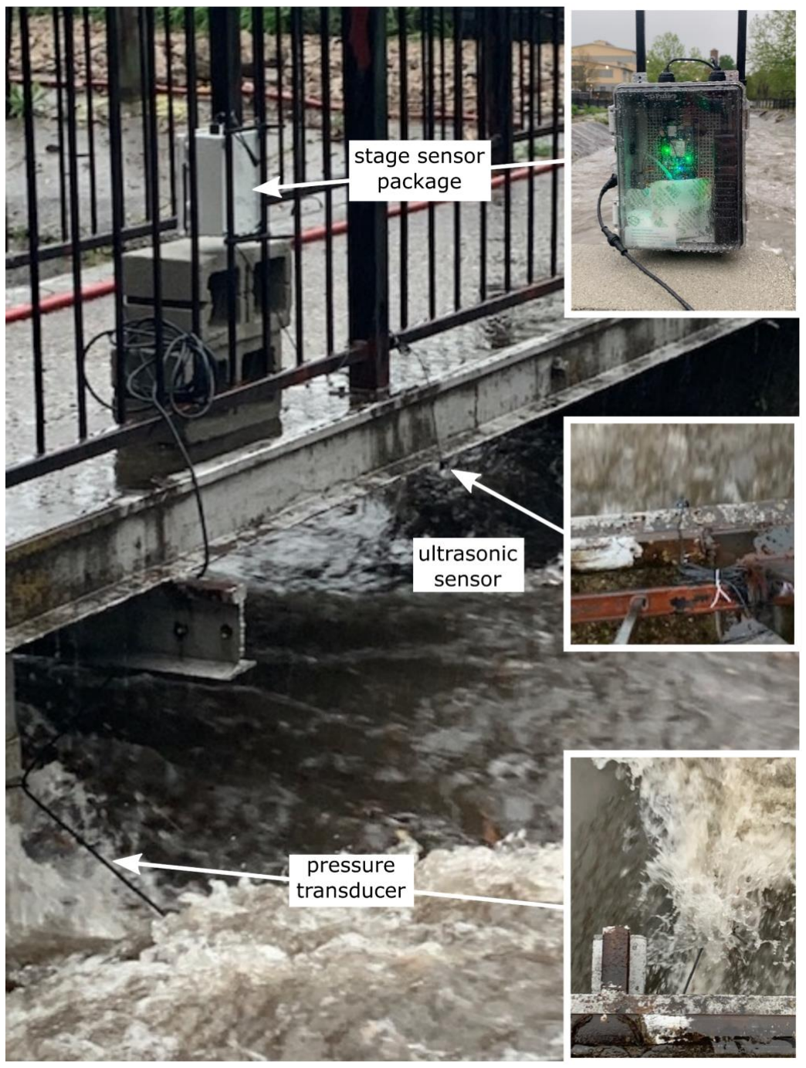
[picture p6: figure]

4/5

- Severe thunderstorms and tornado warning
- Deployed behind 300 Main on bridge
- Channel profile differs from USGS; peaks should line up, but magnitude may not
- Pressure sensor was secured to bridge leg, ultrasonic sensor was draped over side
- Data collection timeframe: 13:50 – 20:42
- Cause of failure: waterproofing issues shorted datalogging board
- Solution: add glue to further waterproof area around cable glands
- Some noisy readings on ultrasonic sensor towards end of deployment
- Possible cause: sensor may not be as “waterproof” as datasheet claims

## Results

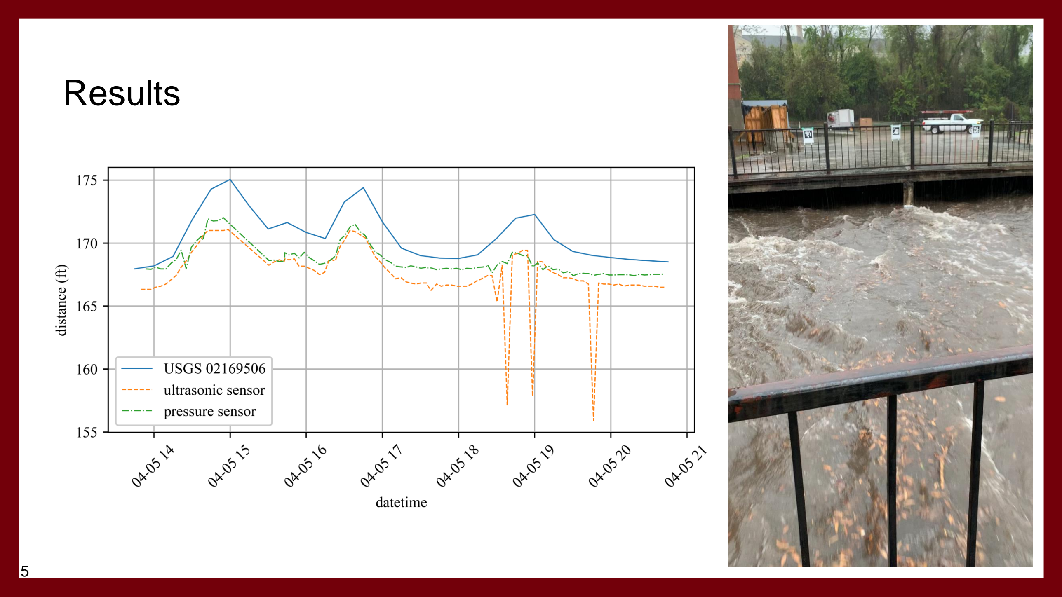
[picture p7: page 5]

4/6-4/7

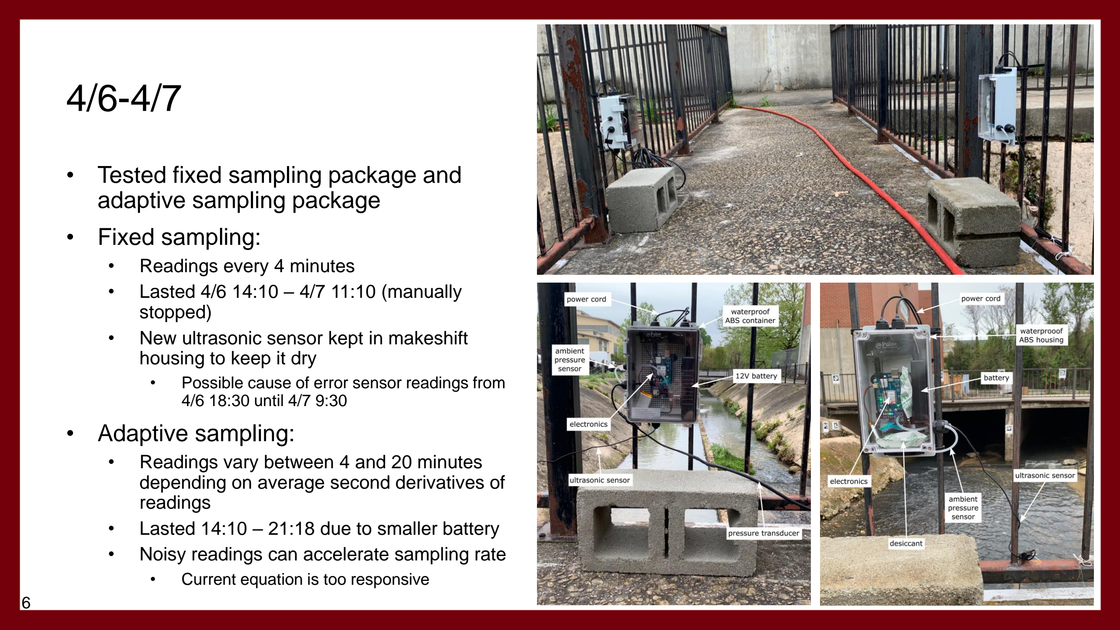
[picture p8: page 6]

- Tested fixed sampling package and adaptive sampling package
- Fixed sampling:
- Readings every 4 minutes
- Lasted 4/6 14:10 – 4/7 11:10 (manually stopped)
- New ultrasonic sensor kept in makeshift housing to keep it dry
- Possible cause of error sensor readings from 4/6 18:30 until 4/7 9:30
- Adaptive sampling:
- Readings vary between 4 and 20 minutes depending on average second derivatives of readings
- Lasted 14:10 – 21:18 due to smaller battery
- Noisy readings can accelerate sampling rate
- Current equation is too responsive

## Results

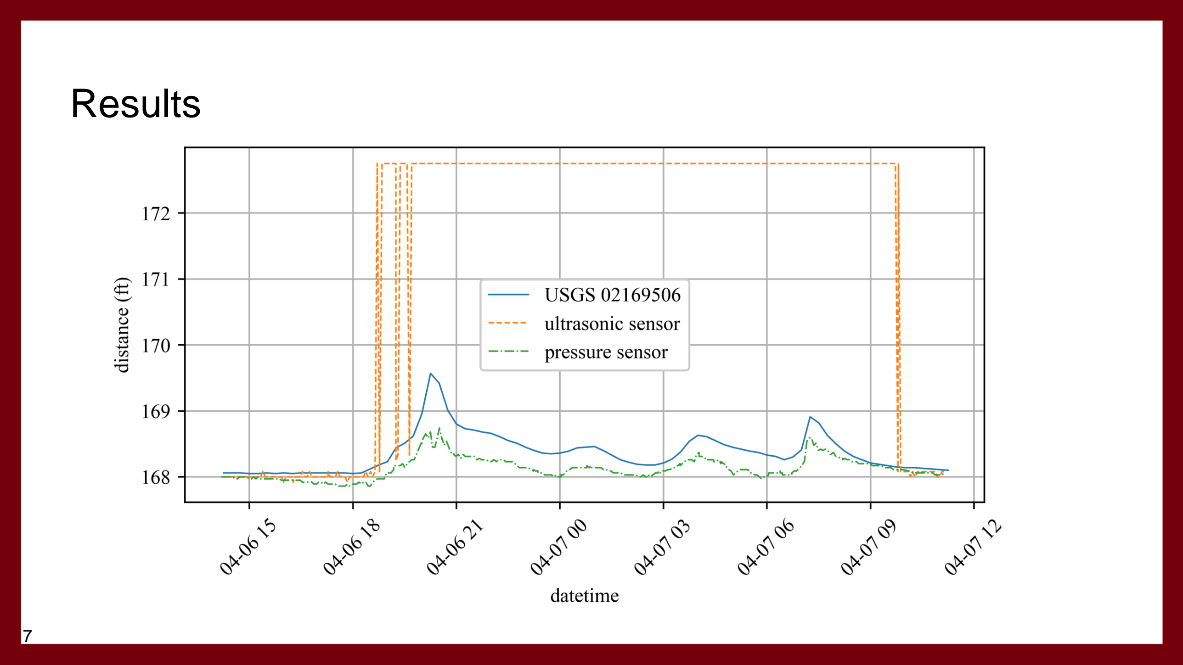
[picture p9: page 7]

## Results

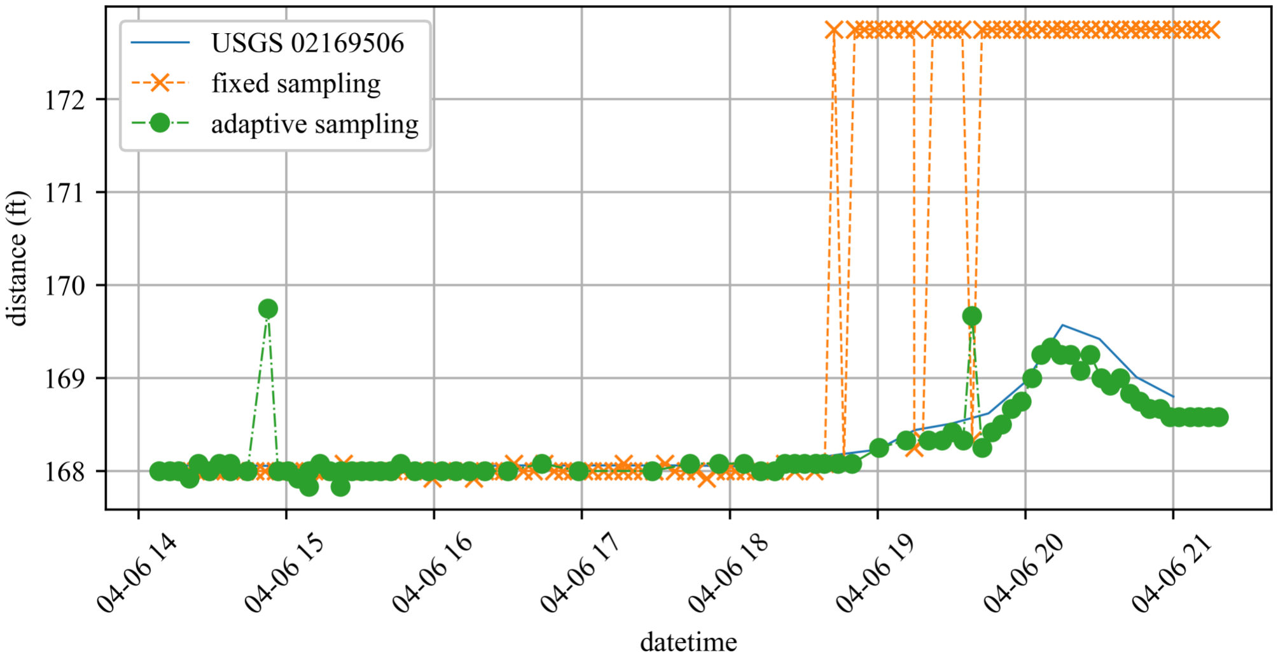
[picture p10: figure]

## Improvements

- Switch to a two-transducer ultrasonic sensor
- Two transducers reduces angle spread, which increases accuracy by reducing area that sensor is capturing
- Average multiple sensor readings to reduce outliers
- Design waterproofing housing for sensor
- Make a less responsive time equation (and test more with adaptive sampling package)
- Secure pressure transducer and ultrasonic sensor to structure better
- Implement a trigger that notifies if readings haven’t been taken after a certain timeframe

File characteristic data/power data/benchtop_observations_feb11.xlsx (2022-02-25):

Event | Current | Time
11.1V on barrel
Net connection | 100
MQTT connection | 110
Subscription waiting | 110
Data collection | 120
Sleep | 50-60
GPS on | 120
Sleep after GPS was on | 60
Data after GPS was on | 120
5v on VIN
before net | 60
net to mqtt | 60
mqtt to subscribe loop | 60
data collection | 70
sleep | 30
gps | 70
sleep after gps | 40
data after gps | 70
 | 5V pin reads 3.8V, too close to reg limits
7.4V on VIN
before net | 100-90
net to mqtt | 100
mqtt to subscribe loop | 110
data collection | 120-110
sleep | 50
gps | 120
sleep after gps | 60
data after gps | 120
 | 5V pin reads 4.96V, checks out
7.4V on barrel jack
before net | 100-90
net to mqtt | 100
mqtt to subscribe loop | 100-110
data collection | 110-120
sleep | 50
gps | 120
sleep after gps | 60
data after gps | 120 | no clear change in wattage after GPS has been turned on either, may just need to find an AT command to turn it back off
12V on barrel jack try 2
before net | 100-90
net to mqtt | 100
mqtt to subscribe loop | 110
data collection | 120-110
sleep | 50
gps | 120
sleep after gps | 60
data after gps | 120
 | 5V pin reads 4.96V, same as with 7.4V
12V on barrel jack SPD1168X
before net | 0.97 | 22.39
net to mqtt | 0.102 | 22.42
mqtt to subscribe loop | 0.11 | variable
data collection | 0.121-0.113 | 8
sleep | 0.053 | 20 (set by user)
gps | 0.121 | 21.35 (unsuccessful)
sleep after gps | 0.62 | 20 (set by user) | (Only caused by LED! Without led 0.53)
data after gps | 0.121 | 8 | (Only caused by LED! Without led 0.113)
12V on barrel jack SPD1168X no sleep
before net | 0.94
net to mqtt | 0.102
mqtt to subscribe loop | 0.11
data collection | 0.122 - 0.112
sleep | 0.1
gps | 0.12
sleep after gps | 0.109
data after gps | 0.119
12V on barrel jack SPD1168X no sleep |  |  | mAH
before net | 94 | 22 | 0.5744444444
net to mqtt | 102 | 22 | 0.6233333333
mqtt to subscribe loop | 110 | 20 | 0.6111111111
data collection (1) | 122 | 1 | 0.03388888889
data collection (2) | 112 | 7 | 0.2177777778
sleep | 53 | 292 | 4.298888889
gps | 120 | 21.35 | 0.7116666667
initialization consumption: |  | 1.808888889
regular cycle consumption: |  | 4.550555556 |  | duration with sleep: | 2.289
cycle with GPS consumption: |  | 5.262222222 |  | duration no sleep: | 1.246

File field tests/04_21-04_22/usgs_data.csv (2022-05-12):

 |  | date | time |  |  |  | stage | temperature
USGS | 2169000 | 4/21/2022 | 15:30 | EDT | 5.97 | 154.63 | 155 | 14.9
USGS | 2169000 | 4/21/2022 | 15:45 | EDT | 5.93 | 154.59 | 154.96 | 14.8
USGS | 2169000 | 4/21/2022 | 16:00 | EDT | 5.91 | 154.57 | 154.94 | 14.8
USGS | 2169000 | 4/21/2022 | 16:15 | EDT | 5.88 | 154.54 | 154.91 | 14.8
USGS | 2169000 | 4/21/2022 | 16:30 | EDT | 5.86 | 154.52 | 154.89 | 14.8
USGS | 2169000 | 4/21/2022 | 16:45 | EDT | 5.83 | 154.49 | 154.86 | 14.7
USGS | 2169000 | 4/21/2022 | 17:00 | EDT | 5.82 | 154.48 | 154.85 | 14.7
USGS | 2169000 | 4/21/2022 | 17:15 | EDT | 5.81 | 154.47 | 154.84 | 14.7
USGS | 2169000 | 4/21/2022 | 17:30 | EDT | 5.79 | 154.45 | 154.82 | 14.6
USGS | 2169000 | 4/21/2022 | 17:45 | EDT | 5.78 | 154.44 | 154.81 | 14.6
USGS | 2169000 | 4/21/2022 | 18:00 | EDT | 5.77 | 154.43 | 154.8 | 14.6
USGS | 2169000 | 4/21/2022 | 18:15 | EDT | 5.77 | 154.43 | 154.8 | 14.5
USGS | 2169000 | 4/21/2022 | 18:30 | EDT | 5.76 | 154.42 | 154.79 | 14.5
USGS | 2169000 | 4/21/2022 | 18:45 | EDT | 5.76 | 154.42 | 154.79 | 14.4
USGS | 2169000 | 4/21/2022 | 19:00 | EDT | 5.75 | 154.41 | 154.78 | 14.4
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

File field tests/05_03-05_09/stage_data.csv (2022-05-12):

 |  |  | date | time |  |  | value | adaptive index | adaptive value
0F0NJQPDRJXMENSYHWX61DW5M4 | 153 | 1793320 | 5/3/2022 | 9:39:42 AM | 13:39:42 | UTC | 153 | 1 | 153 | 0
0F0NJT7999G4E5HH99HHKH4P6C | 153 | 1793320 | 5/3/2022 | 9:44:07 AM | 13:44:07 | UTC | 153 | 2 | 153 | 0
0F0NJXPKSRJBQ8WAA7AC0D6Y2S | 153.25 | 1793320 | 5/3/2022 | 9:50:12 AM | 13:50:12 | UTC | 153.25 | 3 | 153.25 | 0
0F0NJZP8HF8RG365QKV08D1JWJ | 152.42 | 1793320 | 5/3/2022 | 9:53:41 AM | 13:53:41 | UTC | 152.42 | 4 | 152.42 | 0
0F0NM4R60VDQANZM3WNMMC0HX7 | 153 | 1793320 | 5/3/2022 | 10:58:27 AM | 14:58:27 | UTC | 153 | 5 | 153 | 0
0F0NM769279931YKHYYXZYRMA1 | 153 | 1793320 | 5/3/2022 | 11:02:42 AM | 15:02:42 | UTC | 153 | 6 | 153 | 0
0F0NM7P03MXMFY87XH234CH9K3 | 153 | 1793320 | 5/3/2022 | 11:03:34 AM | 15:03:34 | UTC | 153 | 7 | 153 | 0
0F0NMA3SWRW5TD514BHWAYF0Z5 | 153 | 1793320 | 5/3/2022 | 11:07:49 AM | 15:07:49 | UTC | 153 | 11 | 153 | 0
0F0NMCB0VVYKTFTS1PY2FKWZX7 | 153 | 1793320 | 5/3/2022 | 11:11:42 AM | 15:11:42 | UTC | 153 | 15 | 153 | 0
0F0NMEKFHNVDS8CANYTDE6VJWJ | 153 | 1793320 | 5/3/2022 | 11:15:40 AM | 15:15:40 | UTC | 153 | 19 | 153 | 0
0F0NMGWXJBT11FHRV2F50JVWW0 | 153 | 1793320 | 5/3/2022 | 11:19:40 AM | 15:19:40 | UTC | 153 | 23 | 153 | 0
0F0NMK5Y89X48QQDZEPRES7CVD | 153 | 1793320 | 5/3/2022 | 11:23:40 AM | 15:23:40 | UTC | 153 | 27 | 153 | 0
0F0NMNF5AP266YJV44F9623FB0 | 153 | 1793320 | 5/3/2022 | 11:27:40 AM | 15:27:40 | UTC | 153 | 31 | 153 | 0
0F0NMQRGX1E1KQGBBSGB8SMDS7 | 153 | 1793320 | 5/3/2022 | 11:31:40 AM | 15:31:40 | UTC | 153 | 35 | 153 | 0
0F0NMT1QW03MZ530XF26HHQHN7 | 153 | 1793320 | 5/3/2022 | 11:35:40 AM | 15:35:40 | UTC | 153 | 39 | 153 | 0
0F0NMWB2RW3T0333TMXF4BX99J | 153 | 1793320 | 5/3/2022 | 11:39:40 AM | 15:39:40 | UTC | 153 | 43 | 153 | 0
0F0NMYM6MJYEQQ8F5YF3VGA6FE | 153 | 1793320 | 5/3/2022 | 11:43:40 AM | 15:43:40 | UTC | 153 | 47 | 153 | 0
0F0NN0XG2PD08EKNME9VPJ11JB | 153 | 1793320 | 5/3/2022 | 11:47:40 AM | 15:47:40 | UTC | 153 | 51 | 153 | 0
0F0NN36NAARWAYDRQ8RHXPKSP5 | 153 | 1793320 | 5/3/2022 | 11:51:40 AM | 15:51:40 | UTC | 153 | 55 | 153 | 0
0F0NN5G1QBWH1476B3A3GFPPBV | 153 | 1793320 | 5/3/2022 | 11:55:40 AM | 15:55:40 | UTC | 153 | 59 | 153 | 0
0F0NN7SB4BYVRGQS7C3445P45C | 153 | 1793320 | 5/3/2022 | 11:59:40 AM | 15:59:40 | UTC | 153 | 63 | 153 | 0
0F0NNA2CHCEMSQHF5MT7C2VYG9 | 153 | 1793320 | 5/3/2022 | 12:03:40 PM | 16:03:40 | UTC | 153 | 67 | 152.92 | 0
0F0NNCC01BY86MXDE9ZPSZTA2Q | 153 | 1793320 | 5/3/2022 | 12:07:41 PM | 16:07:41 | UTC | 153 | 71 | 153.25 | 0
0F0NNEMW1EP94G45YR05X3FREJ | 153 | 1793320 | 5/3/2022 | 12:11:40 PM | 16:11:40 | UTC | 153 | 75 | 153.08 | 0
0F0NNGY4K8K7W5PFTA3A7E3162 | 153 | 1793320 | 5/3/2022 | 12:15:40 PM | 16:15:40 | UTC | 153 | 79 | 153.08 | 0
0F0NNK7EPCACG379P0B7CZ0PGD | 153 | 1793320 | 5/3/2022 | 12:19:40 PM | 16:19:40 | UTC | 153 | 83 | 153.08 | 0
0F0NNNGQ7G3AAM3546TGACFVJR | 153 | 1793320 | 5/3/2022 | 12:23:40 PM | 16:23:40 | UTC | 153 | 87 | 153 | 0
0F0NNQST8JY953TK2YRAY9WDZD | 153 | 1793320 | 5/3/2022 | 12:27:40 PM | 16:27:40 | UTC | 153 | 91 | 153 | 0
0F0NNT3565EQB9RGT2Z385CW3V | 153 | 1793320 | 5/3/2022 | 12:31:40 PM | 16:31:40 | UTC | 153 | 95 | 153 | 0
0F0NNWCAJ43AA1PGAMC8B3N7HN | 153 | 1793320 | 5/3/2022 | 12:35:40 PM | 16:35:40 | UTC | 153 | 99 | 153 | 0
0F0NNYNRJPPF77EGW3K8N70081 | 153 | 1793320 | 5/3/2022 | 12:39:40 PM | 16:39:40 | UTC | 153 | 103 | 153 | 0
0F0NP0Z09ZXAE3MT8GMD1N00RA | 153 | 1793320 | 5/3/2022 | 12:43:40 PM | 16:43:40 | UTC | 153 | 107 | 153 | 0
0F0NP3811H79H59ZGQ7XZQDWWR | 153 | 1793320 | 5/3/2022 | 12:47:40 PM | 16:47:40 | UTC | 153 | 111 | 153 | 0
0F0NP5HBWH7WR1NHB6PMBF668B | 153 | 1793320 | 5/3/2022 | 12:51:40 PM | 16:51:40 | UTC | 153 | 115 | 153 | 0
0F0NP7TS4235H1FSSK6MDF8NG8 | 153 | 1793320 | 5/3/2022 | 12:55:41 PM | 16:55:41 | UTC | 153 | 119 | 153 | 0
0F0NPA3S2CFQ0Q70BGMGRVT8BP | 153 | 1793320 | 5/3/2022 | 12:59:40 PM | 16:59:40 | UTC | 153 | 123 | 153 | 0
0F0NPCD36YD0GF0QZW86Q6CP39 | 153 | 1793320 | 5/3/2022 | 1:03:40 PM | 17:03:40 | UTC | 153 | 127 | 153 | 0
0F0NPEPA3G0H4XY422X7BZK4RR | 153 | 1793320 | 5/3/2022 | 1:07:40 PM | 17:07:40 | UTC | 153 | 131 | 153 | 0
0F0NPGZH3HCBX5TFFV9TBGKPCA | 153 | 1793320 | 5/3/2022 | 1:11:40 PM | 17:11:40 | UTC | 153 | 135 | 153 | 0
0F0NPK8R1RH4D85GP4ZFZSR2M9 | 153 | 1793320 | 5/3/2022 | 1:15:40 PM | 17:15:40 | UTC | 153 | 139 | 153 | 0
0F0NPNJ2YHD3TDYCCFCP8FZPFP | 153 | 1793320 | 5/3/2022 | 1:19:40 PM | 17:19:40 | UTC | 153 | 143 | 153 | 0
0F0NPQV8AJWPMZ8RNTSND072VG | 153 | 1793320 | 5/3/2022 | 1:23:40 PM | 17:23:40 | UTC | 153 | 147 | 153 | 0
0F0NPT4G3Y039ZBY1TSNKTJ05P | 153 | 1793320 | 5/3/2022 | 1:27:40 PM | 17:27:40 | UTC | 153 | 151 | 153 | 0
0F0NPWDSDD726WEKWNPHM48H03 | 153 | 1793320 | 5/3/2022 | 1:31:40 PM | 17:31:40 | UTC | 153 | 155 | 153 | 0
0F0NPYQ1XQWWFSY93AQCQRJG7F | 153 | 1793320 | 5/3/2022 | 1:35:40 PM | 17:35:40 | UTC | 153 | 159 | 153 | 0
0F0NQ10AEZG84V1MJPYWXGEDCS | 153 | 1793320 | 5/3/2022 | 1:39:40 PM | 17:39:40 | UTC | 153 | 163 | 153 | 0
0F0NQ39FW6HWDZ0YTX1XR6AR20 | 153 | 1793320 | 5/3/2022 | 1:43:40 PM | 17:43:40 | UTC | 153 | 167 | 153 | 0
0F0NQ5JRCGRKSX70EDYTVV6YQK | 153 | 1793320 | 5/3/2022 | 1:47:40 PM | 17:47:40 | UTC | 153 | 171 | 153 | 0
0F0NQ7W5W1N3NREZ373AAR2E04 | 153 | 1793320 | 5/3/2022 | 1:51:41 PM | 17:51:41 | UTC | 153 | 175 | 153 | 0
0F0NQA59EDDRNEMFG8178JP2HP | 153 | 1793320 | 5/3/2022 | 1:55:40 PM | 17:55:40 | UTC | 153 | 179 | 153 | 0
0F0NQCEE3TAZRBAX8174XPECNX | 153 | 1793320 | 5/3/2022 | 1:59:40 PM | 17:59:40 | UTC | 153 | 183 | 153 | 0
0F0NQEQNTGAD5305TQF6A3J0K4 | 153 | 1793320 | 5/3/2022 | 2:03:40 PM | 18:03:40 | UTC | 153 | 187 | 152.92 | 0
0F0NQH1ZZMV53VMR0W75SN99AN | 153 | 1793320 | 5/3/2022 | 2:07:43 PM | 18:07:43 | UTC | 153 | 191 | 153 | 0
0F0NQKA63Q9G9VP38A72X6FTCY | 153 | 1793320 | 5/3/2022 | 2:11:40 PM | 18:11:40 | UTC | 153 | 195 | 152.92 | 0
0F0NQNKCA9VW070ADGDKR6KRJT | 152.92 | 1793320 | 5/3/2022 | 2:15:40 PM | 18:15:40 | UTC | 152.92 | 199 | 152.92 | 0
0F0NQQWMTCYT9QWFKZ2E869JPS | 153 | 1793320 | 5/3/2022 | 2:19:40 PM | 18:19:40 | UTC | 153 | 203 | 153 | 0
0F0NQT5VSR0VF57M5ZC3BTJCE3 | 153 | 1793320 | 5/3/2022 | 2:23:40 PM | 18:23:40 | UTC | 153 | 207 | 152.92 | 0
0F0NQWF4ABQAZER9283XX07E3M | 153 | 1793320 | 5/3/2022 | 2:27:40 PM | 18:27:40 | UTC | 153 | 211 | 152.92 | 0
0F0NQYRMSPTHHNBJFHERZV3P52 | 153 | 1793320 | 5/3/2022 | 2:31:41 PM | 18:31:41 | UTC | 153 | 215 | 152.92 | 0
0F0NR11KTHKFH17PZDZN7G0KHA | 153 | 1793320 | 5/3/2022 | 2:35:40 PM | 18:35:40 | UTC | 153 | 219 | 152.92 | 0
0F0NR3AVKXT14SB0QDGD5XHCTY | 153 | 1793320 | 5/3/2022 | 2:39:40 PM | 18:39:40 | UTC | 153 | 223 | 152.92 | 0
0F0NR5M5QPB1KSYSVPAK0WDVXK | 153 | 1793320 | 5/3/2022 | 2:43:40 PM | 18:43:40 | UTC | 153 | 227 | 152.92 | 0
0F0NR7XMF9SXBY1YN13PMJS9HX | 153 | 1793320 | 5/3/2022 | 2:47:41 PM | 18:47:41 | UTC | 153 | 231 | 152.92 | 0
0F0NRA6JTDSKMNJA0YDGN9RYYH | 153 | 1793320 | 5/3/2022 | 2:51:40 PM | 18:51:40 | UTC | 153 | 235 | 152.92 | 0
0F0NRCFS17YN9TSY3HX3Q008T0 | 153 | 1793320 | 5/3/2022 | 2:55:40 PM | 18:55:40 | UTC | 153 | 239 | 152.92 | 0
0F0NRES5JR22X8ZYQ0ZAQX0CZ7 | 153 | 1793320 | 5/3/2022 | 2:59:40 PM | 18:59:40 | UTC | 153 | 243 | 152.92 | 0
0F0NRH2BNN4NPK893BDT86N4DN | 153 | 1793320 | 5/3/2022 | 3:03:40 PM | 19:03:40 | UTC | 153 | 247 | 152.92 | 0
0F0NRKBG8F1XE21VVQB495142P | 152.92 | 1793320 | 5/3/2022 | 3:07:40 PM | 19:07:40 | UTC | 152.92 | 251 | 152.92 | 0
0F0NRNMV6HFDV40C2BYW1MFXVM | 152.92 | 1793320 | 5/3/2022 | 3:11:40 PM | 19:11:40 | UTC | 152.92 | 255 | 152.92 | 0
0F0NRQY94DK85ACN083G5PAWPE | 153 | 1793320 | 5/3/2022 | 3:15:41 PM | 19:15:41 | UTC | 153 | 259 | 152.92 | 0
0F0NRT793GNNKSSREQNJDMRWWP | 153 | 1793320 | 5/3/2022 | 3:19:40 PM | 19:19:40 | UTC | 153 | 263 | 152.92 | 0
0F0NRWGGTM0ME68AD7T3JZDV26 | 153.25 | 1793320 | 5/3/2022 | 3:23:40 PM | 19:23:40 | UTC | 153.25 | 267 | 152.92 | 0
0F0NRYSXA558XHD7JSQT1366NC | 153 | 1793320 | 5/3/2022 | 3:27:40 PM | 19:27:40 | UTC | 153 | 271 | 152.92 | 0
0F0NS138X93AEPWFPQNX8N4RK5 | 153.17 | 1793320 | 5/3/2022 | 3:31:41 PM | 19:31:41 | UTC | 153.17 | 275 | 152.92 | 0
0F0NS3C9N5PQKJQVHBR0DM35PY | 153.17 | 1793320 | 5/3/2022 | 3:35:40 PM | 19:35:40 | UTC | 153.17 | 279 | 152.92 | 0
0F0NS5NDFV3A3VHDG510F1QFSS | 153.08 | 1793320 | 5/3/2022 | 3:39:40 PM | 19:39:40 | UTC | 153.08 | 283 | 152.92 | 0
0F0NS7YR0JJWRQN3NX517X33Q6 | 153.08 | 1793320 | 5/3/2022 | 3:43:40 PM | 19:43:40 | UTC | 153.08 | 287 | 152.92 | 0
0F0NSA80W7S742XHA21T1Z4GKW | 153.08 | 1793320 | 5/3/2022 | 3:47:40 PM | 19:47:40 | UTC | 153.08 | 291 | 152.92 | 0
0F0NSCH8N65BGCYTXMB4FXWV83 | 153.08 | 1793320 | 5/3/2022 | 3:51:40 PM | 19:51:40 | UTC | 153.08 | 295 | 152.92 | 0
0F0NSETFKKJR1REBT9VH2PTQET | 153.08 | 1793320 | 5/3/2022 | 3:55:40 PM | 19:55:40 | UTC | 153.08 | 299 | 152.92 | 0
0F0NSH3NTKZ8NZYK8RSXQGRXV0 | 153.08 | 1793320 | 5/3/2022 | 3:59:40 PM | 19:59:40 | UTC | 153.08 | 303 | 152.92 | 0
0F0NSKCXJ4314SWRGDEZ00FG81 | 153.08 | 1793320 | 5/3/2022 | 4:03:40 PM | 20:03:40 | UTC | 153.08 | 307 | 152.92 | 0
0F0NSNP6VXKPRRKC5BJ9F5YNHM | 153.08 | 1793320 | 5/3/2022 | 4:07:40 PM | 20:07:40 | UTC | 153.08 | 311 | 152.92 | 0
0F0NSQZEKCXJJKNFVQAZZHXDMS | 153.08 | 1793320 | 5/3/2022 | 4:11:40 PM | 20:11:40 | UTC | 153.08 | 315 | 152.92 | 0
0F0NST8PF8JNSWBCKSW09GT8DJ | 153 | 1793320 | 5/3/2022 | 4:15:40 PM | 20:15:40 | UTC | 153 | 319 | 152.92 | 0
0F0NSWSDAA00P1NZ4XYBAD1QHP | 153 | 1793320 | 5/3/2022 | 4:20:04 PM | 20:20:04 | UTC | 153 | 323 | 153 | 0
0F0NSX5PRPTDZZRQJVKF1HDPW0 | 153 | 1793320 | 5/3/2022 | 4:20:45 PM | 20:20:45 | UTC | 153 | 327 | 153 | 0
0F0NSZDFTG52KEPZFHQA8A742W | 153 | 1793320 | 5/3/2022 | 4:24:40 PM | 20:24:40 | UTC | 153 | 331 | 153 | 0
0F0NT1PN8TMXNRQXZ9PRBRA1GB | 153 | 1793320 | 5/3/2022 | 4:28:40 PM | 20:28:40 | UTC | 153 | 335 | 153 | 0
0F0NT3ZX1V5246X9A85ZTC43T1 | 153 | 1793320 | 5/3/2022 | 4:32:40 PM | 20:32:40 | UTC | 153 | 339 | 153 | 0
0F0NTAXNVTVDWWA5H5AZWC4RPP | 153 | 1793320 | 5/3/2022 | 4:44:46 PM | 20:44:46 | UTC | 153 | 343 | 153 | 0
0F0NVTM9ETHEYC6X8YP7WKSP34 | 153 | 1793320 | 5/3/2022 | 6:08:09 PM | 22:08:09 | UTC | 153 | 347 | 153 | 0
0F0NVWMYYM68P67XPGYJRTD0AP | 153 | 1793320 | 5/3/2022 | 6:11:41 PM | 22:11:41 | UTC | 153 | 351 | 153 | 0
0F0NVYY222V6R80BY3HVJYYTPX | 153 | 1793320 | 5/3/2022 | 6:15:40 PM | 22:15:40 | UTC | 153 | 355 | 153 | 0
0F0NW17JDC5BWJ2ANVMM39K2W6 | 153 | 1793320 | 5/3/2022 | 6:19:41 PM | 22:19:41 | UTC | 153 | 359 | 153 | 0
0F0NW3NCYYDGF5RM2AT384TCGJ | 153 | 1793320 | 5/3/2022 | 6:23:56 PM | 22:23:56 | UTC | 153 | 363 | 153 | 0
0F0NW5SND97D9QCDSZV90GXPR5 | 153 | 1793320 | 5/3/2022 | 6:27:40 PM | 22:27:40 | UTC | 153 | 367 | 153 | 0
0F0NW82VKCXMX4XFCEPC5NTWFS | 153 | 1793320 | 5/3/2022 | 6:31:40 PM | 22:31:40 | UTC | 153 | 371 | 153 | 0
0F0NWAC2HR87VCPAZ8P8V88B8P | 153 | 1793320 | 5/3/2022 | 6:35:40 PM | 22:35:40 | UTC | 153 | 375 | 153 | 0
0F0NWCNDEB2QGZVCNYPM05BHB8 | 153 | 1793320 | 5/3/2022 | 6:39:40 PM | 22:39:40 | UTC | 153 | 379 | 153 | 0
0F0NWEYH7TGCMYH9RXRMSQXW3Y | 153 | 1793320 | 5/3/2022 | 6:43:39 PM | 22:43:39 | UTC | 153 | 383 | 153 | 0
0F0NWH7VCXEP7Z6ZZ8AB78BYZ7 | 153 | 1793320 | 5/3/2022 | 6:47:40 PM | 22:47:40 | UTC | 153 | 387 | 153 | 0
0F0NWKH5D143MSA7P17T2YHZ8S | 153 | 1793320 | 5/3/2022 | 6:51:40 PM | 22:51:40 | UTC | 153 | 391 | 153 | 0
0F0NWNTA10DEK1N1B1BP1P8WTA | 153 | 1793320 | 5/3/2022 | 6:55:40 PM | 22:55:40 | UTC | 153 | 395 | 153 | 0
0F0NWR3M3YH2P67QS12A884JBK | 153 | 1793320 | 5/3/2022 | 6:59:40 PM | 22:59:40 | UTC | 153 | 399 | 153 | 0
0F0NWTCTCJVBAZ3NGG9QANAX26 | 153 | 1793320 | 5/3/2022 | 7:03:40 PM | 23:03:40 | UTC | 153 | 403 | 153 | 0
0F0NWWNZPXMAYE8Q14PRTPSC7P | 153 | 1793320 | 5/3/2022 | 7:07:39 PM | 23:07:39 | UTC | 153 | 407 | 153 | 0
0F0NWYZBC4FYJRQXSCS1X0PCHS | 153 | 1793320 | 5/3/2022 | 7:11:40 PM | 23:11:40 | UTC | 153 | 411 | 153 | 0
0F0NX18GRW0FH15WEDS2VXNDVQ | 153 | 1793320 | 5/3/2022 | 7:15:40 PM | 23:15:40 | UTC | 153 | 415 | 153 | 0
0F0NX3HQRXW6E741V0VKKEYBFJ | 153 | 1793320 | 5/3/2022 | 7:19:40 PM | 23:19:40 | UTC | 153 | 419 | 153 | 0
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

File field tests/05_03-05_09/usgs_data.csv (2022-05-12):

 |  | date | time |  |  | stage | temperature
USGS | 2169000 | 5/3/2022 | 9:30 | EDT | 3.97 | 153 | 15.3
USGS | 2169000 | 5/3/2022 | 9:45 | EDT | 3.97 | 153 | 15.3
USGS | 2169000 | 5/3/2022 | 10:00 | EDT | 3.97 | 153 | 15.3
USGS | 2169000 | 5/3/2022 | 10:15 | EDT | 3.97 | 153 | 15.4
USGS | 2169000 | 5/3/2022 | 10:30 | EDT | 3.97 | 153 | 15.4
USGS | 2169000 | 5/3/2022 | 10:45 | EDT | 3.97 | 153 | 15.5
USGS | 2169000 | 5/3/2022 | 11:00 | EDT | 3.97 | 153 | 15.6
USGS | 2169000 | 5/3/2022 | 11:15 | EDT | 3.97 | 153 | 15.6
USGS | 2169000 | 5/3/2022 | 11:30 | EDT | 3.97 | 153 | 15.7
USGS | 2169000 | 5/3/2022 | 11:45 | EDT | 3.97 | 153 | 15.7
USGS | 2169000 | 5/3/2022 | 12:00 | EDT | 3.97 | 153 | 15.8
USGS | 2169000 | 5/3/2022 | 12:15 | EDT | 3.97 | 153 | 15.9
USGS | 2169000 | 5/3/2022 | 12:30 | EDT | 3.97 | 153 | 16
USGS | 2169000 | 5/3/2022 | 12:45 | EDT | 3.96 | 152.99 | 16
USGS | 2169000 | 5/3/2022 | 13:00 | EDT | 3.97 | 153 | 16.1
USGS | 2169000 | 5/3/2022 | 13:15 | EDT | 3.97 | 153 | 16.1
USGS | 2169000 | 5/3/2022 | 13:30 | EDT | 3.97 | 153 | 16.2
USGS | 2169000 | 5/3/2022 | 13:45 | EDT | 3.97 | 153 | 16.2
USGS | 2169000 | 5/3/2022 | 14:00 | EDT | 3.97 | 153 | 16.3
USGS | 2169000 | 5/3/2022 | 14:15 | EDT | 3.97 | 153 | 16.3
USGS | 2169000 | 5/3/2022 | 14:30 | EDT | 3.97 | 153 | 16.4
USGS | 2169000 | 5/3/2022 | 14:45 | EDT | 3.97 | 153 | 16.4
USGS | 2169000 | 5/3/2022 | 15:00 | EDT | 3.97 | 153 | 16.4
USGS | 2169000 | 5/3/2022 | 15:15 | EDT | 3.99 | 153.02 | 16.4
USGS | 2169000 | 5/3/2022 | 15:30 | EDT | 4.01 | 153.04 | 16.5
USGS | 2169000 | 5/3/2022 | 15:45 | EDT | 4.01 | 153.04 | 16.4
USGS | 2169000 | 5/3/2022 | 16:00 | EDT | 4.01 | 153.04 | 16.4
USGS | 2169000 | 5/3/2022 | 16:15 | EDT | 4.01 | 153.04 | 16.4
USGS | 2169000 | 5/3/2022 | 16:30 | EDT | 4.01 | 153.04 | 16.4
USGS | 2169000 | 5/3/2022 | 16:45 | EDT | 4 | 153.03 | 16.4
USGS | 2169000 | 5/3/2022 | 17:00 | EDT | 4 | 153.03 | 16.4
USGS | 2169000 | 5/3/2022 | 17:15 | EDT | 4 | 153.03 | 16.5
USGS | 2169000 | 5/3/2022 | 17:30 | EDT | 4 | 153.03 | 16.5
USGS | 2169000 | 5/3/2022 | 17:45 | EDT | 3.99 | 153.02 | 16.5
USGS | 2169000 | 5/3/2022 | 18:00 | EDT | 3.99 | 153.02 | 16.5
USGS | 2169000 | 5/3/2022 | 18:15 | EDT | 3.99 | 153.02 | 16.5
USGS | 2169000 | 5/3/2022 | 18:30 | EDT | 3.99 | 153.02 | 16.4
USGS | 2169000 | 5/3/2022 | 18:45 | EDT | 3.99 | 153.02 | 16.4
USGS | 2169000 | 5/3/2022 | 19:00 | EDT | 3.99 | 153.02 | 16.4
USGS | 2169000 | 5/3/2022 | 19:15 | EDT | 3.99 | 153.02 | 16.3
USGS | 2169000 | 5/3/2022 | 19:30 | EDT | 3.99 | 153.02 | 16.3
USGS | 2169000 | 5/3/2022 | 19:45 | EDT | 3.99 | 153.02 | 16.2
USGS | 2169000 | 5/3/2022 | 20:00 | EDT | 3.99 | 153.02 | 16.2
USGS | 2169000 | 5/3/2022 | 20:15 | EDT | 3.99 | 153.02 | 16.2
USGS | 2169000 | 5/3/2022 | 20:30 | EDT | 3.99 | 153.02 | 16.1
USGS | 2169000 | 5/3/2022 | 20:45 | EDT | 3.99 | 153.02 | 16.1
USGS | 2169000 | 5/3/2022 | 21:00 | EDT | 3.99 | 153.02 | 16
USGS | 2169000 | 5/3/2022 | 21:15 | EDT | 3.99 | 153.02 | 16
USGS | 2169000 | 5/3/2022 | 21:30 | EDT | 3.99 | 153.02 | 16
USGS | 2169000 | 5/3/2022 | 21:45 | EDT | 3.99 | 153.02 | 15.9
USGS | 2169000 | 5/3/2022 | 22:00 | EDT | 3.99 | 153.02 | 15.9
USGS | 2169000 | 5/3/2022 | 22:15 | EDT | 3.99 | 153.02 | 15.9
USGS | 2169000 | 5/3/2022 | 22:30 | EDT | 3.99 | 153.02 | 15.9
USGS | 2169000 | 5/3/2022 | 22:45 | EDT | 3.99 | 153.02 | 15.8
USGS | 2169000 | 5/3/2022 | 23:00 | EDT | 3.99 | 153.02 | 15.8
USGS | 2169000 | 5/3/2022 | 23:15 | EDT | 3.99 | 153.02 | 15.8
USGS | 2169000 | 5/3/2022 | 23:30 | EDT | 3.99 | 153.02 | 15.8
USGS | 2169000 | 5/3/2022 | 23:45 | EDT | 3.98 | 153.01 | 15.8
USGS | 2169000 | 5/4/2022 | 0:00 | EDT | 3.98 | 153.01 | 15.7
USGS | 2169000 | 5/4/2022 | 0:15 | EDT | 3.98 | 153.01 | 15.7
USGS | 2169000 | 5/4/2022 | 0:30 | EDT | 3.98 | 153.01 | 15.7
USGS | 2169000 | 5/4/2022 | 0:45 | EDT | 3.98 | 153.01 | 15.7
USGS | 2169000 | 5/4/2022 | 1:00 | EDT | 3.98 | 153.01 | 15.6
USGS | 2169000 | 5/4/2022 | 1:15 | EDT | 3.98 | 153.01 | 15.6
USGS | 2169000 | 5/4/2022 | 1:30 | EDT | 3.98 | 153.01 | 15.6
USGS | 2169000 | 5/4/2022 | 1:45 | EDT | 3.98 | 153.01 | 15.6
USGS | 2169000 | 5/4/2022 | 2:00 | EDT | 3.98 | 153.01 | 15.6
USGS | 2169000 | 5/4/2022 | 2:15 | EDT | 3.98 | 153.01 | 15.6
USGS | 2169000 | 5/4/2022 | 2:30 | EDT | 3.97 | 153 | 15.6
USGS | 2169000 | 5/4/2022 | 2:45 | EDT | 3.97 | 153 | 15.6
USGS | 2169000 | 5/4/2022 | 3:00 | EDT | 3.97 | 153 | 15.6
USGS | 2169000 | 5/4/2022 | 3:15 | EDT | 3.97 | 153 | 15.6
USGS | 2169000 | 5/4/2022 | 3:30 | EDT | 3.97 | 153 | 15.6
USGS | 2169000 | 5/4/2022 | 3:45 | EDT | 3.97 | 153 | 15.6
USGS | 2169000 | 5/4/2022 | 4:00 | EDT | 3.97 | 153 | 15.5
USGS | 2169000 | 5/4/2022 | 4:15 | EDT | 3.97 | 153 | 15.5
USGS | 2169000 | 5/4/2022 | 4:30 | EDT | 3.97 | 153 | 15.5
USGS | 2169000 | 5/4/2022 | 4:45 | EDT | 3.97 | 153 | 15.5
USGS | 2169000 | 5/4/2022 | 5:00 | EDT | 3.97 | 153 | 15.5
USGS | 2169000 | 5/4/2022 | 5:15 | EDT | 3.97 | 153 | 15.5
USGS | 2169000 | 5/4/2022 | 5:30 | EDT | 3.97 | 153 | 15.4
USGS | 2169000 | 5/4/2022 | 5:45 | EDT | 3.97 | 153 | 15.4
USGS | 2169000 | 5/4/2022 | 6:00 | EDT | 3.97 | 153 | 15.4
USGS | 2169000 | 5/4/2022 | 6:15 | EDT | 3.97 | 153 | 15.4
USGS | 2169000 | 5/4/2022 | 6:30 | EDT | 3.97 | 153 | 15.3
USGS | 2169000 | 5/4/2022 | 6:45 | EDT | 3.97 | 153 | 15.3
USGS | 2169000 | 5/4/2022 | 7:00 | EDT | 3.97 | 153 | 15.3
USGS | 2169000 | 5/4/2022 | 7:15 | EDT | 3.97 | 153 | 15.2
USGS | 2169000 | 5/4/2022 | 7:30 | EDT | 3.97 | 153 | 15.2
USGS | 2169000 | 5/4/2022 | 7:45 | EDT | 3.97 | 153 | 15.2
USGS | 2169000 | 5/4/2022 | 8:00 | EDT | 3.97 | 153 | 15.2
USGS | 2169000 | 5/4/2022 | 8:15 | EDT | 3.97 | 153 | 15.2
USGS | 2169000 | 5/4/2022 | 8:30 | EDT | 3.97 | 153 | 15.2
USGS | 2169000 | 5/4/2022 | 8:45 | EDT | 3.97 | 153 | 15.2
USGS | 2169000 | 5/4/2022 | 9:00 | EDT | 3.97 | 153 | 15.2
USGS | 2169000 | 5/4/2022 | 9:15 | EDT | 3.97 | 153 | 15.2
USGS | 2169000 | 5/4/2022 | 9:30 | EDT | 3.97 | 153 | 15.2
USGS | 2169000 | 5/4/2022 | 9:45 | EDT | 3.97 | 153 | 15.2
USGS | 2169000 | 5/4/2022 | 10:00 | EDT | 3.97 | 153 | 15.2
USGS | 2169000 | 5/4/2022 | 10:15 | EDT | 3.97 | 153 | 15.3
USGS | 2169000 | 5/4/2022 | 10:30 | EDT | 3.97 | 153 | 15.3
USGS | 2169000 | 5/4/2022 | 10:45 | EDT | 3.97 | 153 | 15.4
USGS | 2169000 | 5/4/2022 | 11:00 | EDT | 3.97 | 153 | 15.4
USGS | 2169000 | 5/4/2022 | 11:15 | EDT | 3.97 | 153 | 15.5
USGS | 2169000 | 5/4/2022 | 11:30 | EDT | 3.97 | 153 | 15.5
USGS | 2169000 | 5/4/2022 | 11:45 | EDT | 3.97 | 153 | 15.6
USGS | 2169000 | 5/4/2022 | 12:00 | EDT | 3.97 | 153 | 15.6
USGS | 2169000 | 5/4/2022 | 12:15 | EDT | 3.97 | 153 | 15.7
USGS | 2169000 | 5/4/2022 | 12:30 | EDT | 3.97 | 153 | 15.8
USGS | 2169000 | 5/4/2022 | 12:45 | EDT | 3.97 | 153 | 15.8
USGS | 2169000 | 5/4/2022 | 13:00 | EDT | 3.97 | 153 | 15.9
USGS | 2169000 | 5/4/2022 | 13:15 | EDT | 3.97 | 153 | 16
USGS | 2169000 | 5/4/2022 | 13:30 | EDT | 3.97 | 153 | 16
USGS | 2169000 | 5/4/2022 | 13:45 | EDT | 3.97 | 153 | 16.1
USGS | 2169000 | 5/4/2022 | 14:00 | EDT | 3.97 | 153 | 16.2
USGS | 2169000 | 5/4/2022 | 14:15 | EDT | 3.97 | 153 | 16.2
USGS | 2169000 | 5/4/2022 | 14:30 | EDT | 3.97 | 153 | 16.2
USGS | 2169000 | 5/4/2022 | 14:45 | EDT | 3.97 | 153 | 16.3
USGS | 2169000 | 5/4/2022 | 15:00 | EDT | 3.97 | 153 | 16.4
USGS | 2169000 | 5/4/2022 | 15:15 | EDT | 3.97 | 153 | 16.4
USGS | 2169000 | 5/4/2022 | 15:30 | EDT | 3.97 | 153 | 16.4
USGS | 2169000 | 5/4/2022 | 15:45 | EDT | 3.97 | 153 | 16.5
USGS | 2169000 | 5/4/2022 | 16:00 | EDT | 3.97 | 153 | 16.5
USGS | 2169000 | 5/4/2022 | 16:15 | EDT | 3.97 | 153 | 16.6
USGS | 2169000 | 5/4/2022 | 16:30 | EDT | 3.97 | 153 | 16.6
USGS | 2169000 | 5/4/2022 | 16:45 | EDT | 3.97 | 153 | 16.7
USGS | 2169000 | 5/4/2022 | 17:00 | EDT | 3.97 | 153 | 16.7
USGS | 2169000 | 5/4/2022 | 17:15 | EDT | 3.97 | 153 | 16.7
USGS | 2169000 | 5/4/2022 | 17:30 | EDT | 3.97 | 153 | 16.8
USGS | 2169000 | 5/4/2022 | 17:45 | EDT | 3.97 | 153 | 16.8
USGS | 2169000 | 5/4/2022 | 18:00 | EDT | 3.97 | 153 | 16.8
USGS | 2169000 | 5/4/2022 | 18:15 | EDT | 3.97 | 153 | 16.8
USGS | 2169000 | 5/4/2022 | 18:30 | EDT | 3.97 | 153 | 16.8
USGS | 2169000 | 5/4/2022 | 18:45 | EDT | 3.97 | 153 | 16.8
USGS | 2169000 | 5/4/2022 | 19:00 | EDT | 3.97 | 153 | 16.8
USGS | 2169000 | 5/4/2022 | 19:15 | EDT | 3.97 | 153 | 16.8
USGS | 2169000 | 5/4/2022 | 19:30 | EDT | 3.97 | 153 | 16.7
USGS | 2169000 | 5/4/2022 | 19:45 | EDT | 3.97 | 153 | 16.7
USGS | 2169000 | 5/4/2022 | 20:00 | EDT | 3.97 | 153 | 16.6
USGS | 2169000 | 5/4/2022 | 20:15 | EDT | 3.97 | 153 | 16.6
USGS | 2169000 | 5/4/2022 | 20:30 | EDT | 3.97 | 153 | 16.6
USGS | 2169000 | 5/4/2022 | 20:45 | EDT | 3.97 | 153 | 16.6
USGS | 2169000 | 5/4/2022 | 21:00 | EDT | 3.97 | 153 | 16.5
USGS | 2169000 | 5/4/2022 | 21:15 | EDT | 3.97 | 153 | 16.5
USGS | 2169000 | 5/4/2022 | 21:30 | EDT | 3.97 | 153 | 16.4
USGS | 2169000 | 5/4/2022 | 21:45 | EDT | 3.97 | 153 | 16.4
USGS | 2169000 | 5/4/2022 | 22:00 | EDT | 3.97 | 153 | 16.3
USGS | 2169000 | 5/4/2022 | 22:15 | EDT | 3.97 | 153 | 16.3
USGS | 2169000 | 5/4/2022 | 22:30 | EDT | 3.97 | 153 | 16.3
USGS | 2169000 | 5/4/2022 | 22:45 | EDT | 3.97 | 153 | 16.2
USGS | 2169000 | 5/4/2022 | 23:00 | EDT | 3.97 | 153 | 16.2
USGS | 2169000 | 5/4/2022 | 23:15 | EDT | 3.97 | 153 | 16.1
USGS | 2169000 | 5/4/2022 | 23:30 | EDT | 3.97 | 153 | 16.1
USGS | 2169000 | 5/4/2022 | 23:45 | EDT | 3.96 | 152.99 | 16.1
USGS | 2169000 | 5/5/2022 | 0:00 | EDT | 3.96 | 152.99 | 16
USGS | 2169000 | 5/5/2022 | 0:15 | EDT | 3.97 | 153 | 16
USGS | 2169000 | 5/5/2022 | 0:30 | EDT | 3.96 | 152.99 | 15.9
USGS | 2169000 | 5/5/2022 | 0:45 | EDT | 3.96 | 152.99 | 15.9
USGS | 2169000 | 5/5/2022 | 1:00 | EDT | 3.96 | 152.99 | 15.9
USGS | 2169000 | 5/5/2022 | 1:15 | EDT | 3.96 | 152.99 | 15.8
USGS | 2169000 | 5/5/2022 | 1:30 | EDT | 3.96 | 152.99 | 15.8
USGS | 2169000 | 5/5/2022 | 1:45 | EDT | 3.96 | 152.99 | 15.8
USGS | 2169000 | 5/5/2022 | 2:00 | EDT | 3.96 | 152.99 | 15.7
USGS | 2169000 | 5/5/2022 | 2:15 | EDT | 3.96 | 152.99 | 15.7
USGS | 2169000 | 5/5/2022 | 2:30 | EDT | 3.96 | 152.99 | 15.7
USGS | 2169000 | 5/5/2022 | 2:45 | EDT | 3.96 | 152.99 | 15.7
USGS | 2169000 | 5/5/2022 | 3:00 | EDT | 3.96 | 152.99 | 15.6
USGS | 2169000 | 5/5/2022 | 3:15 | EDT | 3.96 | 152.99 | 15.6
USGS | 2169000 | 5/5/2022 | 3:30 | EDT | 3.96 | 152.99 | 15.6
USGS | 2169000 | 5/5/2022 | 3:45 | EDT | 3.96 | 152.99 | 15.6
USGS | 2169000 | 5/5/2022 | 4:00 | EDT | 3.96 | 152.99 | 15.6
USGS | 2169000 | 5/5/2022 | 4:15 | EDT | 3.97 | 153 | 15.6
USGS | 2169000 | 5/5/2022 | 4:30 | EDT | 3.96 | 152.99 | 15.6
USGS | 2169000 | 5/5/2022 | 4:45 | EDT | 3.97 | 153 | 15.6
USGS | 2169000 | 5/5/2022 | 5:00 | EDT | 3.97 | 153 | 15.6
USGS | 2169000 | 5/5/2022 | 5:15 | EDT | 3.96 | 152.99 | 15.5
USGS | 2169000 | 5/5/2022 | 5:30 | EDT | 3.96 | 152.99 | 15.5
USGS | 2169000 | 5/5/2022 | 5:45 | EDT | 3.97 | 153 | 15.5
USGS | 2169000 | 5/5/2022 | 6:00 | EDT | 3.97 | 153 | 15.5
USGS | 2169000 | 5/5/2022 | 6:15 | EDT | 3.97 | 153 | 15.4
USGS | 2169000 | 5/5/2022 | 6:30 | EDT | 3.96 | 152.99 | 15.4
USGS | 2169000 | 5/5/2022 | 6:45 | EDT | 3.96 | 152.99 | 15.4
USGS | 2169000 | 5/5/2022 | 7:00 | EDT | 3.96 | 152.99 | 15.4
USGS | 2169000 | 5/5/2022 | 7:15 | EDT | 3.96 | 152.99 | 15.3
USGS | 2169000 | 5/5/2022 | 7:30 | EDT | 3.96 | 152.99 | 15.3
USGS | 2169000 | 5/5/2022 | 7:45 | EDT | 3.97 | 153 | 15.3
USGS | 2169000 | 5/5/2022 | 8:00 | EDT | 3.96 | 152.99 | 15.3
USGS | 2169000 | 5/5/2022 | 8:15 | EDT | 3.96 | 152.99 | 15.3
USGS | 2169000 | 5/5/2022 | 8:30 | EDT | 3.96 | 152.99 | 15.3
USGS | 2169000 | 5/5/2022 | 8:45 | EDT | 3.96 | 152.99 | 15.3
USGS | 2169000 | 5/5/2022 | 9:00 | EDT | 3.97 | 153 | 15.3
USGS | 2169000 | 5/5/2022 | 9:15 | EDT | 3.96 | 152.99 | 15.3
USGS | 2169000 | 5/5/2022 | 9:30 | EDT | 3.96 | 152.99 | 15.3
USGS | 2169000 | 5/5/2022 | 9:45 | EDT | 3.96 | 152.99 | 15.3
USGS | 2169000 | 5/5/2022 | 10:00 | EDT | 3.97 | 153 | 15.3
USGS | 2169000 | 5/5/2022 | 10:15 | EDT | 3.96 | 152.99 | 15.4
USGS | 2169000 | 5/5/2022 | 10:30 | EDT | 3.96 | 152.99 | 15.4
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

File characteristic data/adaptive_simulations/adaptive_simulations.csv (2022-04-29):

true signal | adaptive | adaptive_2 | adaptive_3_index | adaptive_3 | adaptive_4_index | adaptive_4 | adaptive_5_index | adaptive_5 | adaptive_6_index | adaptive_6 |  | adaptive_7_index | adaptive_7
166.75 | 166.75 | 166.75 | 5 | 166.75 | 5 | 166.75 | 5 | 166.75 | 5 | 166.756 |  | 5 | 166.756
167.08 | 167.08 | 167.08 | 6 | 167.08 | 6 | 167.08 | 6 | 167.08 | 6 | 167.08 | 0.07 | 6 | 167.08 | 0.07
167.42 | 167.42 | 167.42 | 7 | 167.42 | 7 | 167.42 | 7 | 167.42 | 10 | 169.25 | 0.5 | 10 | 169.25 | 0.5
168.08 |  |  | 11 | 169.75 | 9 | 168.58 | 11 | 169.75 | 11 | 169.75 | 0.6 | 11 | 169.75 | 0.6
168.58 |  |  | 14 | 171 | 10 | 169.25 | 12 | 170.33 | 12 | 170.33 | 0.72 | 12 | 170.33 | 0.72
169.25 | 169.75 | 169.75 | 15 | 171 | 11 | 169.75 | 13 | 170.58 | 13 | 170.58 | 0.77 | 13 | 170.58 | 0.77
169.75 |  |  | 16 | 171 | 12 | 170.33 | 14 | 171 | 14 | 171 | 0.78 | 14 | 171 | 0.78
170.33 |  |  | 17 | 171 | 13 | 170.58 | 15 | 171 | 15 | 171 | 0.35 | 15 | 171 | 0.35
170.58 |  |  | 18 | 171.08 | 14 | 171 | 16 | 171 | 17 | 171 | 0.25 | 17 | 171 | 0.25
171 | 171 | 171 | 20 | 168.5 | 15 | 171 | 17 | 171 | 20 | 168.5 | 0.63 | 21 | 168.67 | 0.6
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

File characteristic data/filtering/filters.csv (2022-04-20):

true signal | kalman | moving average | median | last replacement
166.75 |  | 166.5 | 166.75 | 166.75
167.08 |  | 166.65 | 167.08 | 167.08
167.42 | 158.65 | 166.87 | 167.42 | 167.42
168.08 | 162.33 | 167.18 | 168.08 | 168.08
168.58 | 164.77 | 167.58 | 168.58 | 168.58
169.25 | 166.52 | 168.08 | 169.25 | 169.25
169.75 | 167.78 | 168.62 | 169.75 | 169.75
170.33 | 168.78 | 169.2 | 170.33 | 170.33
170.58 | 169.48 | 169.7 | 170.58 | 170.58
171 | 170.07 | 170.18 | 171 | 171
171 | 170.44 | 170.53 | 171 | 171
171 | 170.66 | 170.78 | 171 | 171
171 | 170.79 | 170.92 | 171 | 171
171.08 | 170.9 | 171.02 | 171.08 | 171.08
168.25 | 169.87 | 170.47 | 168.25 | 168.25
168.5 | 169.33 | 169.97 | 168.5 | 168.5
168.67 | 169.07 | 169.5 | 168.67 | 168.67
168.58 | 168.88 | 169.02 | 168.58 | 168.58
168.75 | 168.83 | 168.55 | 168.75 | 168.75
168.67 | 168.77 | 168.63 | 168.67 | 168.67
168.75 | 168.76 | 168.68 | 168.75 | 168.75
168.17 | 168.53 | 168.58 | 168.17 | 168.17
168.17 | 168.39 | 168.5 | 168.17 | 168.17
168 | 168.24 | 168.35 | 168 | 168
167.83 | 168.08 | 168.18 | 167.83 | 167.83
167.5 | 167.85 | 167.93 | 167.5 | 167.5
167.67 | 167.78 | 167.83 | 167.67 | 167.67
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

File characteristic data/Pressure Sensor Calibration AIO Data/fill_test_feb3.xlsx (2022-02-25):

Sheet: unprocessed data
2022-02-03 | 10:59:27 | 105 | 0.51 | 0.29 | 0.67 | 0.03 | 0.08 | -0.17 | Test Feb 3
2022-02-03 | 10:59:30 | 105 | 0.51 | 0.29 | 0.67 | 0.03 | 0.08 | -0.17 | Temperature: 68
2022-02-03 | 10:59:32 | 105 | 0.51 | 0.29 | 0.67 | 0.03 | 0.08 | -0.17 | Pressure atm: 30.18 in
2022-02-03 | 10:59:34 | 106 | 0.52 | 0.3 | 0.7 | 0.05 | 0.1 | -0.14
2022-02-03 | 10:59:36 | 105 | 0.51 | 0.29 | 0.67 | 0.03 | 0.08 | -0.17
2022-02-03 | 10:59:38 | 105 | 0.51 | 0.29 | 0.67 | 0.03 | 0.08 | -0.17
2022-02-03 | 10:59:40 | 105 | 0.51 | 0.29 | 0.67 | 0.03 | 0.08 | -0.17
2022-02-03 | 10:59:43 | 105 | 0.51 | 0.29 | 0.67 | 0.03 | 0.08 | -0.17
2022-02-03 | 10:59:45 | 105 | 0.51 | 0.29 | 0.67 | 0.03 | 0.08 | -0.17
2022-02-03 | 10:59:47 | 105 | 0.51 | 0.29 | 0.67 | 0.03 | 0.08 | -0.17
2022-02-03 | 10:59:49 | 105 | 0.51 | 0.29 | 0.67 | 0.03 | 0.08 | -0.17
2022-02-03 | 10:59:51 | 106 | 0.52 | 0.3 | 0.7 | 0.05 | 0.1 | -0.14
2022-02-03 | 10:59:53 | 105 | 0.51 | 0.29 | 0.67 | 0.03 | 0.08 | -0.17
2022-02-03 | 10:59:56 | 105 | 0.51 | 0.29 | 0.67 | 0.03 | 0.08 | -0.17
2022-02-03 | 10:59:58 | 105 | 0.51 | 0.29 | 0.67 | 0.03 | 0.08 | -0.17
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

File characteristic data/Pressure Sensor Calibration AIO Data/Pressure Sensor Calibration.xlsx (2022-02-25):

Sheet: Sheet1
depth-equivalent PSI | Voltage | Depth |  | Testing occurred at 1009.0mb atmospheric
6.852813853 | 3.12 | 15.83 |  | 3.079
6.493506494 | 2.98 | 15 |  | 2.923
6.060606061 | 2.81 | 14
5.627705628 | 2.64 | 13
5.194805195 | 2.48 | 12 |  |  |  | If you know your reading to 1/10th of a foot,
4.761904762 | 2.3 | 11
4.329004329 | 2.13 | 10
3.896103896 | 1.96 | 9
3.463203463 | 1.79 | 8
3.03030303 | 1.61 | 7
2.597402597 | 1.44 | 6
2.218614719 |  | 5.125 |  | 1.295 | 1720hrs
2.164502165 | 1.27 | 5 | 1721hrs |  |  | 5.1 | 27.205972
1.731601732 | 1.09 | 4 |  |  |  | 5 | 26.62769
1.298701299 | 0.91 | 3 |  |  |  | 4.9 | 26.049408
0.8658008658 | 0.74 | 2 |  |  |  | 4.8 | 25.471126
0.4329004329 | 0.56 | 1 |  |  |  | 4.7 | 24.892844
0 | 0.38 | 0 |  | 0.362 |  | 4.6 | 24.314562
 |  |  |  |  |  | 4.5 | 23.73628
 |  |  |  |  |  | 4.4 | 23.157998
0.1 |  | 0.231 |  |  |  | 4.3 | 22.579716
 |  |  |  |  |  | 4.2 | 22.001434
 |  |  |  |  |  | 4.1 | 21.423152
 |  |  |  |  |  | 4 | 20.84487
 |  |  |  |  |  | 3.9 | 20.266588
 |  |  |  |  |  | 3.8 | 19.688306
 |  |  |  |  |  | 3.7 | 19.110024
 |  |  |  |  |  | 3.6 | 18.531742
 |  |  |  |  |  | 3.5 | 17.95346
 |  |  |  |  |  | 3.4 | 17.375178
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

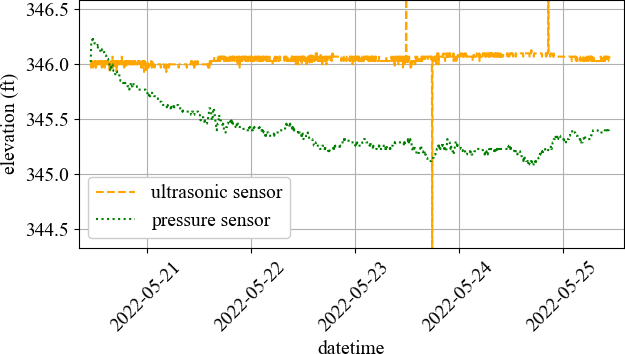
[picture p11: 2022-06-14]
field tests/05_20-05_25/data_zoomed.png

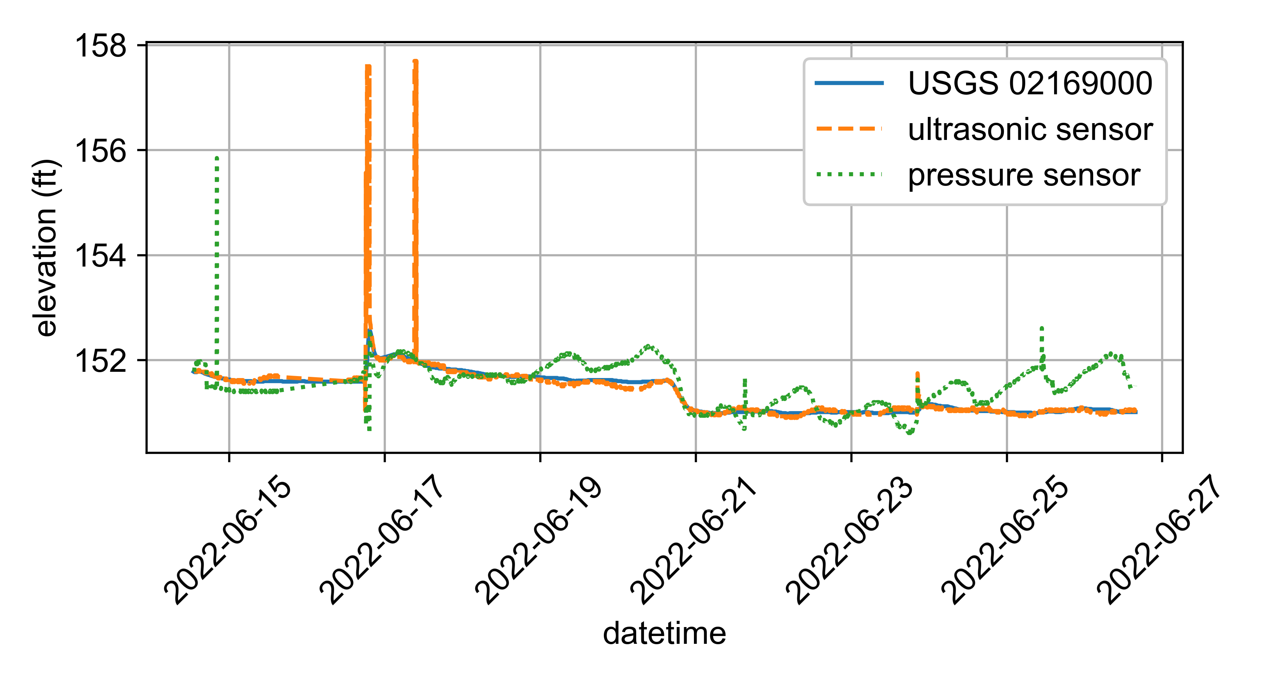
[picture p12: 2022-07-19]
field tests/06_14-06_27/data.png

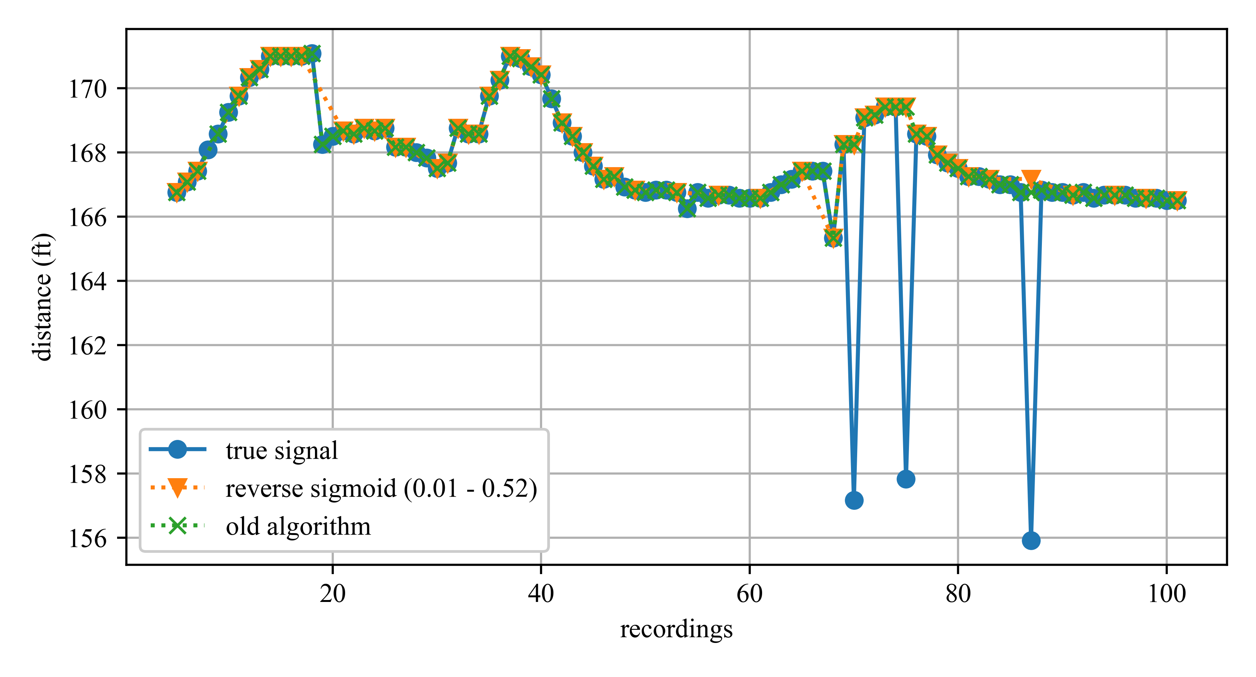
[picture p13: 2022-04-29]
characteristic data/adaptive_simulations/algorithm_comparison.png

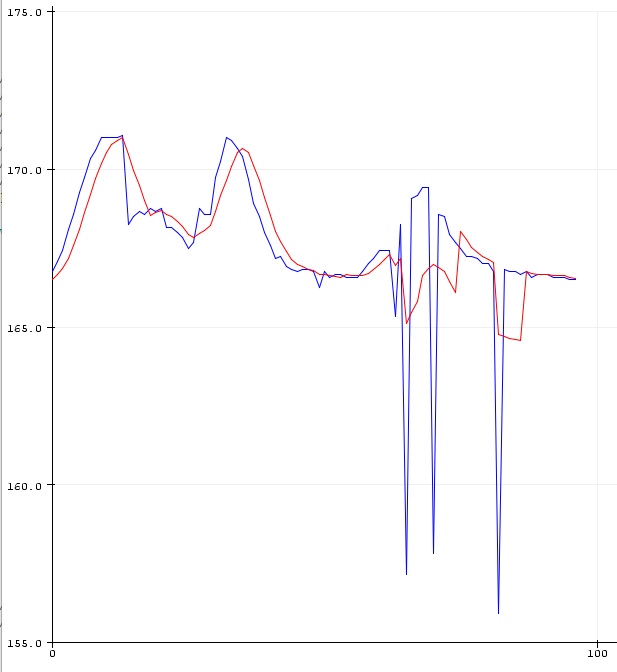
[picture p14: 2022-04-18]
characteristic data/filtering/arduino_plots/moving_average_filter.PNG

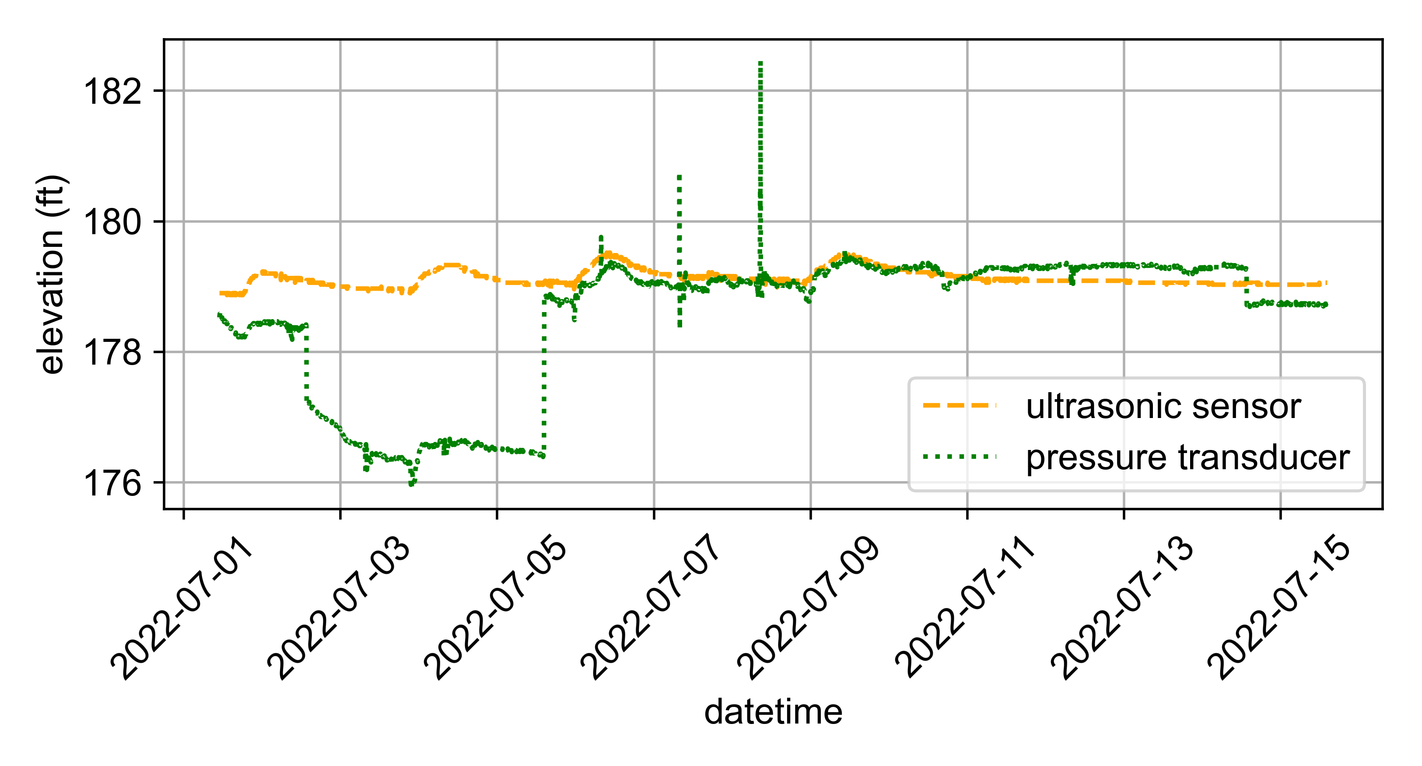
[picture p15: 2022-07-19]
field tests/07_01-07_15/data_filtered.png

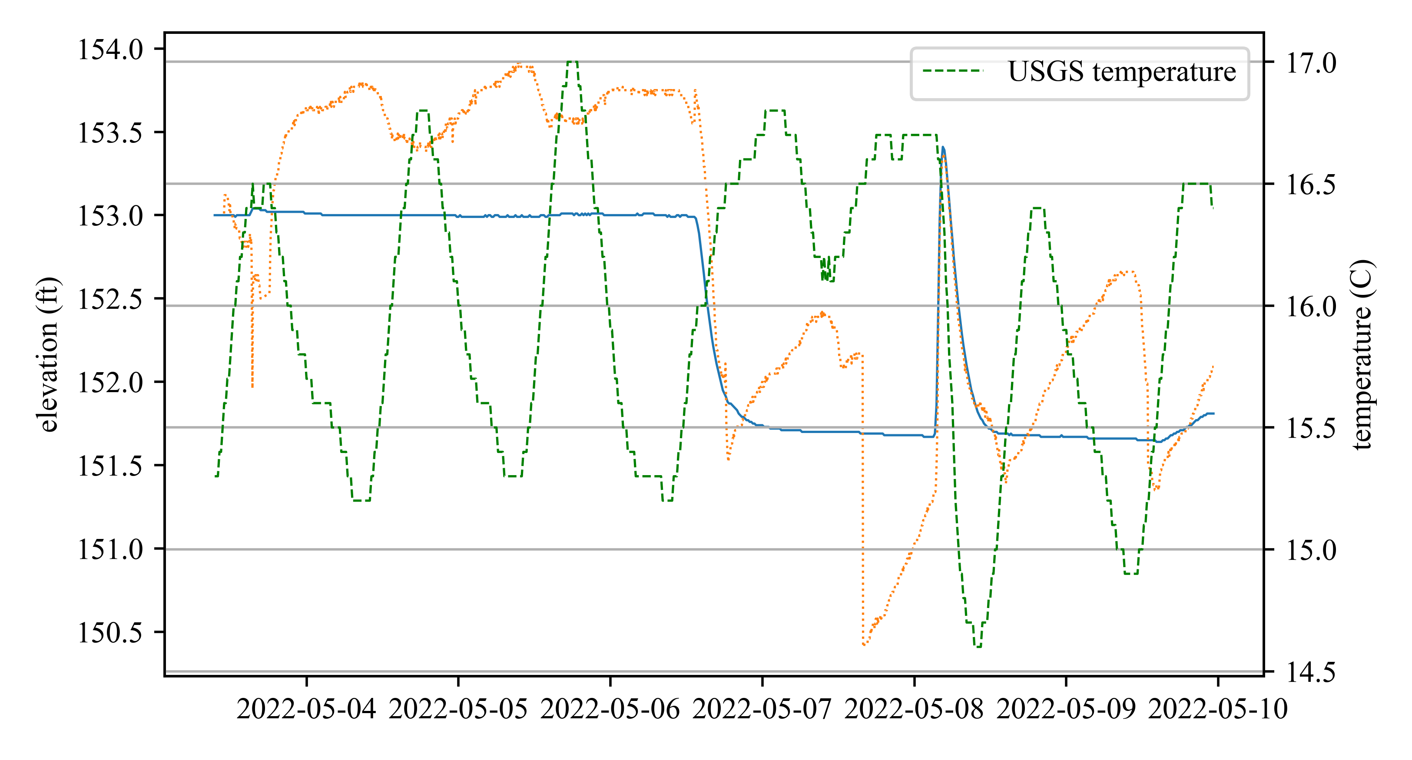
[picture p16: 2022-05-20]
field tests/05_03-05_09/temperature_drift.png

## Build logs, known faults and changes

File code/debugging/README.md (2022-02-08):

## bmp280_altimeter
- tests functionalities of BMP280

## clock calibration
- calibrates the DS3231 real-time clock

## deploy_switch_tester
- full fona program to troubleshoot deployment toggle logic

## gps_update_tester
- test the functionality of a publish/subscribe gps update location toggle

## i2c_scanner
- scans for i2c device addresses

## interrupt_tester 
- test the RTC interrupt capabilities

## mprls_tester
- tests the Adafruit MPRLS ported pressure sensor

## ping_tester
- tests the JSN-SR04 ultrasonic sensor with the NewPing library

## pressure_test_field
- uses serial input to read a known water depth, then takes pressure sensor reading when a button is pushed. Used when calibrating the sensor. 

## pressure_tester
- tests the pressure transducer using analog input and two different calibration equations

## pub_sub_tester
- test the ability to both publish and subscribe to the sampling_rate feed

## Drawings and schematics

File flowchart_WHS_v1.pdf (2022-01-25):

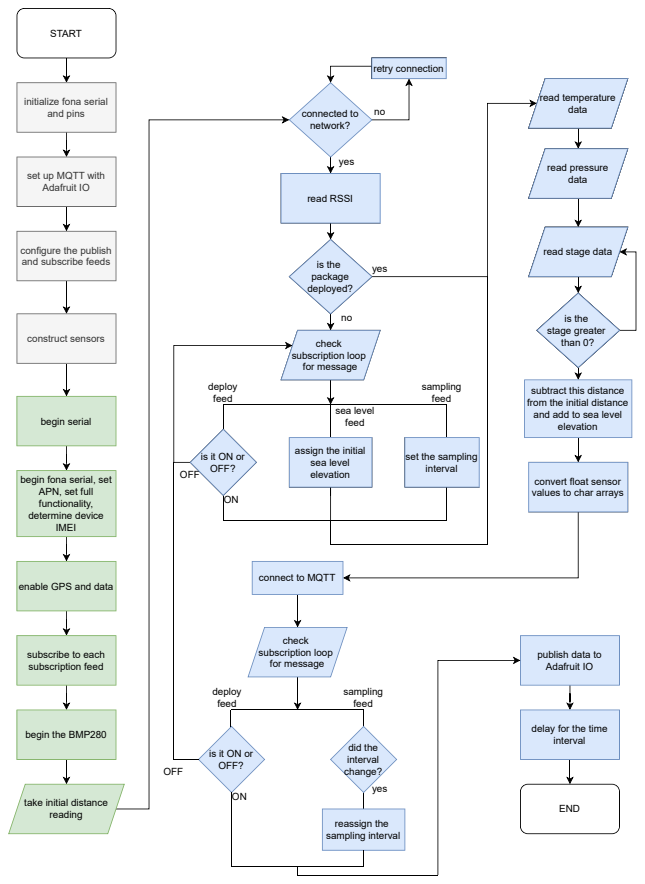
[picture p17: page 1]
START; construct sensors; begin serial; begin the BMP280; connected to network?; read RSSI; is the package deployed?; check subscription loop for message; read temperature data; deploy feed; sea level feed; yes; retry connection; read pressure data; is the stage greater than 0?; OFF? OFF; did the interval change?; sampling feed; reassign the sampling interval; END

initialize fona serial
and pins

set up MQTT with
Adafruit IO

configure the publish
and subscribe feeds

read stage data

subtract this distance
from the initial distance
and add to sea level
elevation

OFF?
OFF

assign the initial
sea level

set the sampling
interval

begin fona serial, set
APN, set full
functionality,
determine device
IMEI

convert float sensor
values to char arrays

connect to MQTT

enable GPS and data

subscribe to each
subscription feed

publish data to

delay for the time

take initial distance
reading

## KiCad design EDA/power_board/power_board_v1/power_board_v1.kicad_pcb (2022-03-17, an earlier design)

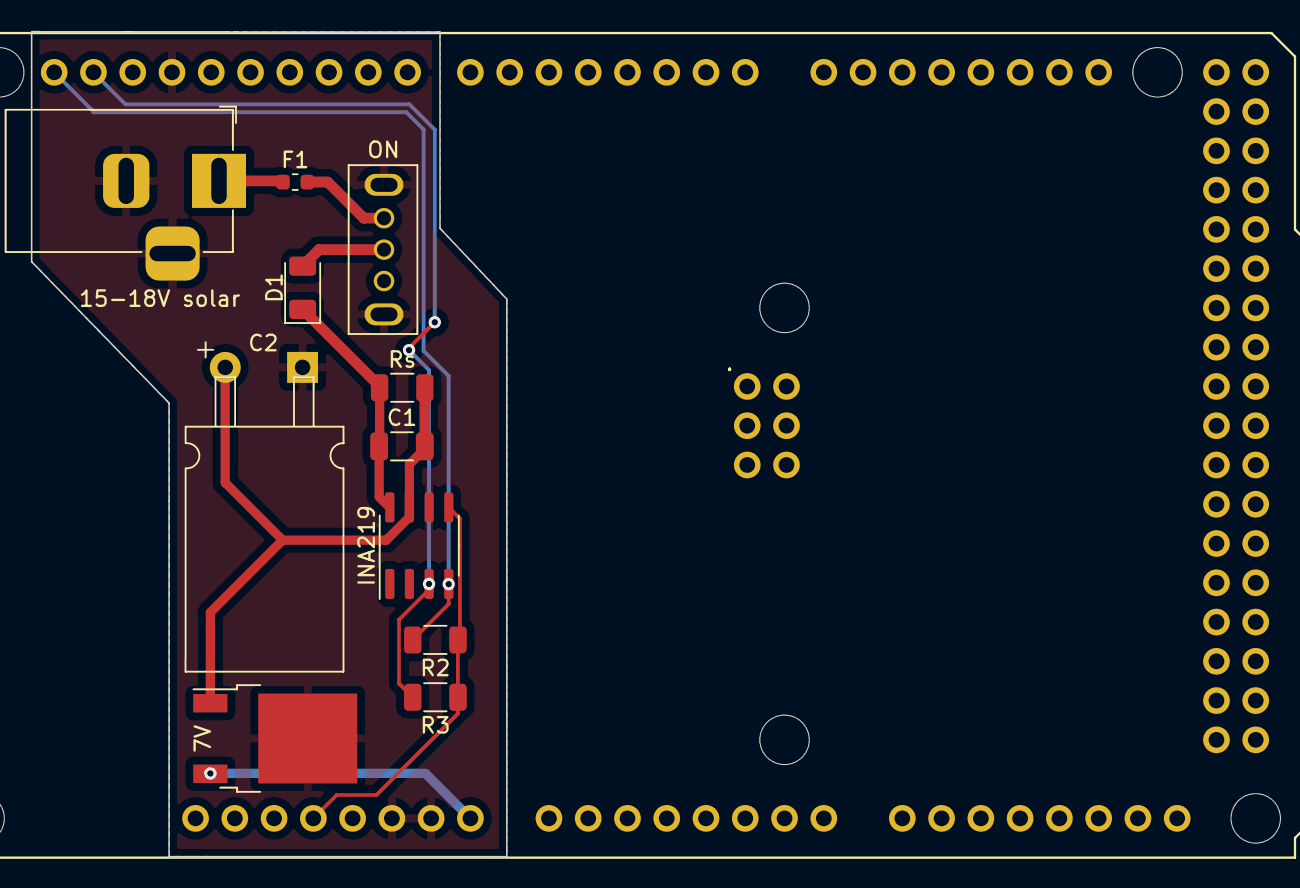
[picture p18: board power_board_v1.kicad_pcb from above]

Board: 2 copper layers, 30.7 x 53.4 mm, 12 parts (0 on the bottom side), 10 nets.

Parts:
7V: LF15_TO252; TO-252-2
15-18V solar: Barrel_Jack; BarrelJack_Horizontal
C1: C; C_1206_3216Metric
C2: C; CP_Radial_D10.0mm_P5.00mm_L16.00mm_bent
D1: D; D_1206_3216Metric
F1: Fuse; Fuse_0603_1608Metric
INA219: INA219AxD; SOIC-8_3.9x4.9mm_P1.27mm
ON: grounded_DIP_switch; grounded_switch
R2, R3: 4.7k; R_1206_3216Metric
Rs: shunt; R_1206_3216Metric
XA1: Arduino_Mega2560_Shield

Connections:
GND: 7V.2 (GND), 15-18V solar.2, 15-18V solar.3, C2.2, INA219.6 (GND), ON.4, ON.5, XA1.GND1 (GND), XA1.GND2 (GND), XA1.GND3 (GND)
unnamed: C1.1, D1.1 (K), INA219.8 (IN+), Rs.1
unnamed: 7V.1 (VI), C1.2, C2.1, INA219.7 (IN-), Rs.2
unnamed: D1.2 (A), ON.2
unnamed: 15-18V solar.1, F1.1
unnamed: F1.2, ON.1
unnamed: INA219.5 (VS), R2.1, R3.1, XA1.3V3 (3.3V)
unnamed: INA219.4 (SCL), R2.2, XA1.SCL
unnamed: INA219.3 (SDA), R3.2, XA1.SDA
unnamed: 7V.3 (VO), XA1.VIN

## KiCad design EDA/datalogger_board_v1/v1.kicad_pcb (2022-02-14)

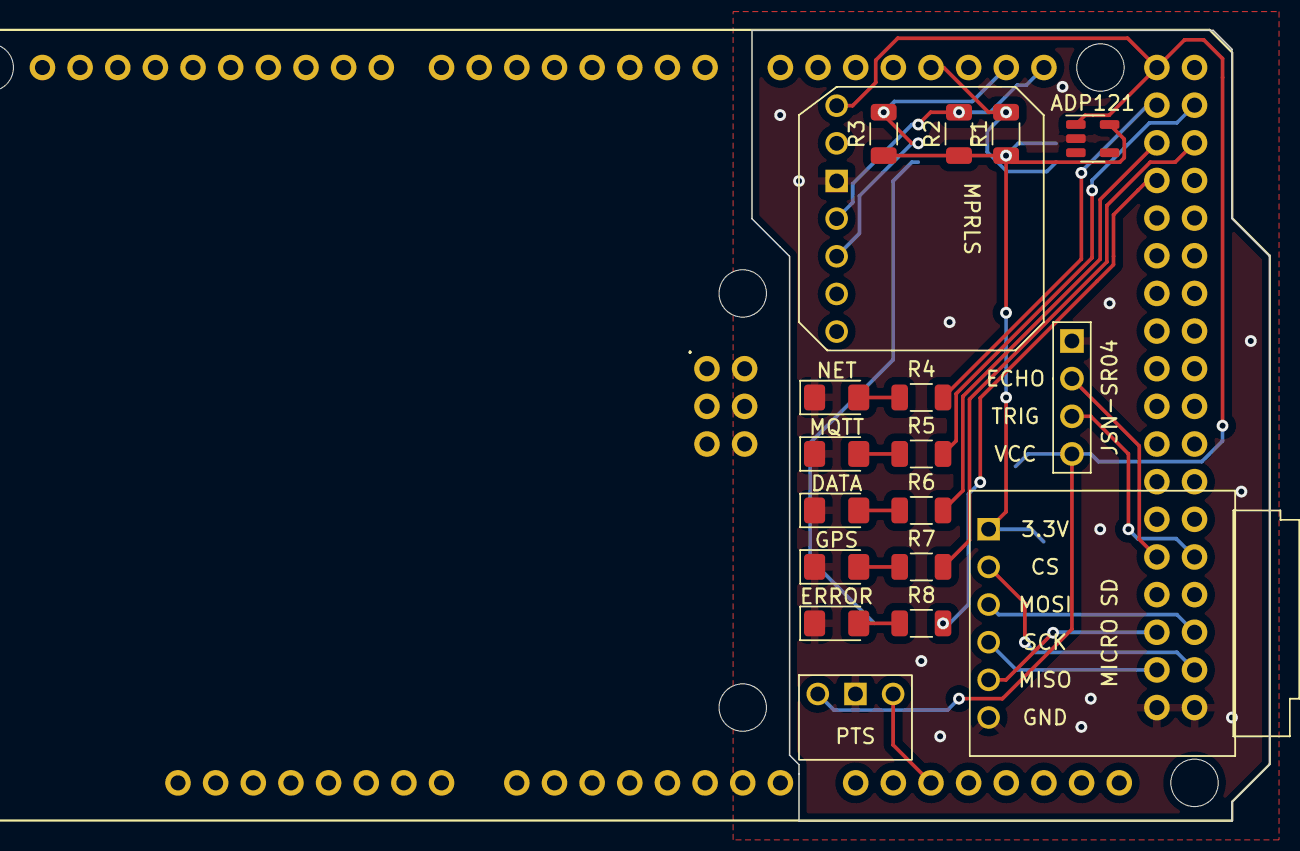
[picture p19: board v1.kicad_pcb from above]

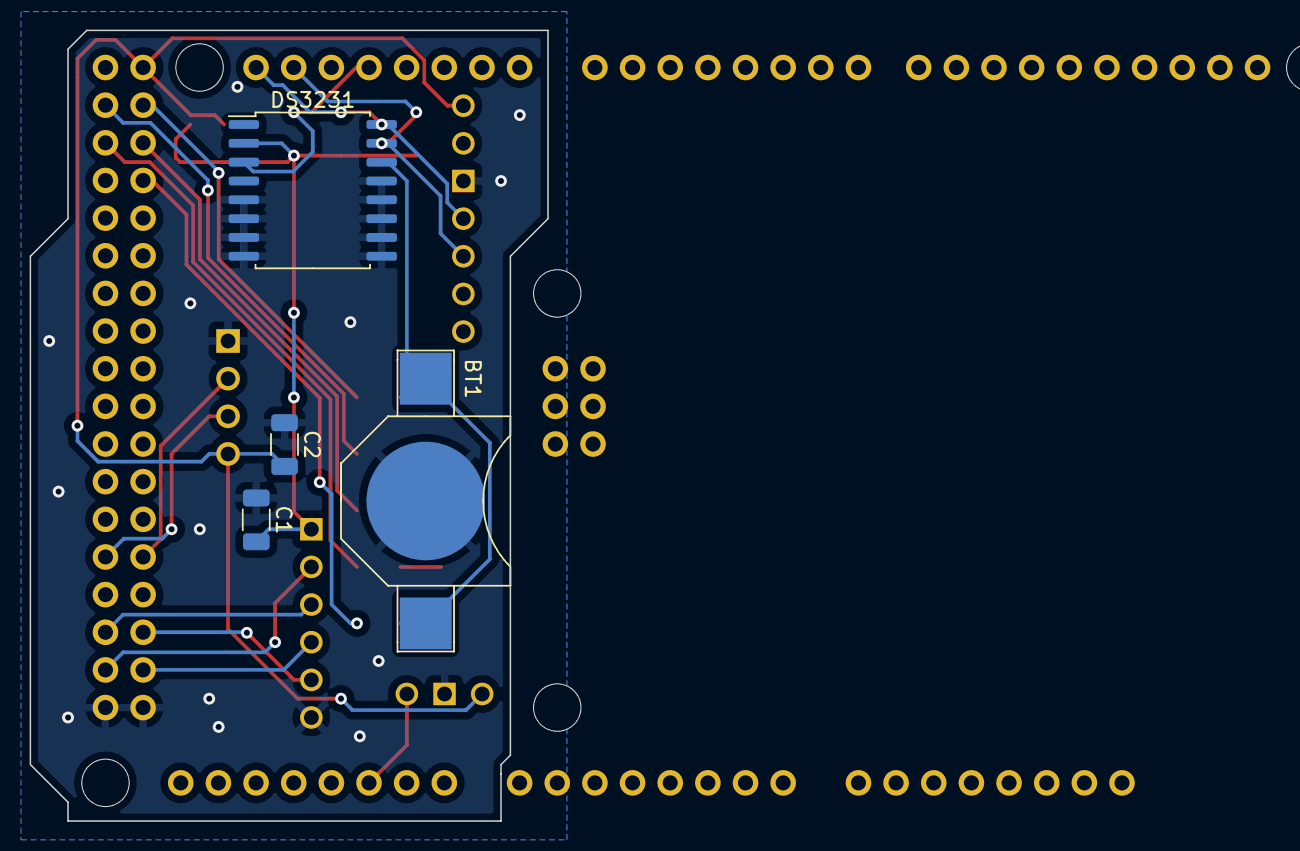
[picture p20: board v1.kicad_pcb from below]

Board: 2 copper layers, 34.9 x 53.3 mm, 23 parts (4 on the bottom side), 24 nets.

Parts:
ADP121: TC2014-3.3VxCTTR; SOT-23-5
BT1: Battery_Cell; battery_holder_10mm
C1, C2: C; C_1206_3216Metric
DATA: LED; LED_1206_3216Metric_Pad1.42x1.75mm_HandSolder
DS3231: DS3231M; SOIC-16W_7.5x10.3mm_P1.27mm
ERROR: LED; LED_1206_3216Metric_Pad1.42x1.75mm_HandSolder
GPS: LED; LED_1206_3216Metric_Pad1.42x1.75mm_HandSolder
JSN-SR04: HCSR04
MICRO SD: microSD_small; small_microSD_v2
MPRLS: MPRLS
MQTT: LED; LED_1206_3216Metric_Pad1.42x1.75mm_HandSolder
NET: LED; LED_1206_3216Metric_Pad1.42x1.75mm_HandSolder
PTS: Pressure_transducer; pressure_sensor
R1, R2, R3, R4, R5, R6, R7, R8: R; R_1206_3216Metric
XA1: Arduino_Mega2560_Shield

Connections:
GND: ADP121.2 (GND), BT1.2 (-), C1.1, C2.1, DATA.1 (K), DS3231.5 (GND), DS3231.6 (GND), DS3231.7 (GND), DS3231.8 (GND), DS3231.9 (GND), DS3231.10 (GND), DS3231.11 (GND), DS3231.12 (GND), DS3231.13 (GND), ERROR.1 (K), GPS.1 (K), JSN-SR04.1 (GND), MICRO SD.6 (GND), MPRLS.3 (GND), MQTT.1 (K), NET.1 (K), PTS.2 (GND), XA1.GND5 (GND), XA1.GND6 (GND)
unnamed: BT1.1 (+), DS3231.14 (VBAT)
unnamed: NET.2 (A), R4.2
unnamed: MQTT.2 (A), R5.2
unnamed: DATA.2 (A), R6.2
unnamed: GPS.2 (A), R7.2
unnamed: ERROR.2 (A), R8.2
unnamed: ADP121.5 (VOUT), C1.2, DS3231.2 (VCC), MICRO SD.1 (3.3V), R1.1, R2.1, R3.1
unnamed: MICRO SD.2 (CS), XA1.D53 (D53_SS)
unnamed: MICRO SD.3 (MOSI), XA1.D51
unnamed: MICRO SD.4 (CLK), XA1.D52
unnamed: MICRO SD.5 (MISO), XA1.D50
unnamed: DS3231.16 (SCL), MPRLS.4 (SCL), R2.2, XA1.D21 (D21_SCL)
unnamed: DS3231.15 (SDA), MPRLS.5 (SDA), R3.2, XA1.D20 (D20_SDA)
unnamed: R4.1, XA1.D22
unnamed: R5.1, XA1.D23
unnamed: R6.1, XA1.D24
unnamed: R7.1, XA1.D25
unnamed: R8.1, XA1.D26
unnamed: ADP121.1 (VIN), C2.2, JSN-SR04.4 (VCC), MPRLS.1 (VIN), PTS.1 (5V), XA1.5V3 (5V)
unnamed: PTS.3 (Sig), XA1.A10
unnamed: DS3231.3 (~INT/SQW), R1.2, XA1.D18 (D18_TX1)
unnamed: JSN-SR04.2 (ECHO), XA1.D46
unnamed: JSN-SR04.3 (TRIG), XA1.D47

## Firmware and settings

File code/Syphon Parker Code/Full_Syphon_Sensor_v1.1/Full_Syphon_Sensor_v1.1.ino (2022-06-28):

//Parker Lovett
//Created: 6/1/2022 Last Edited: 6/2/2022
//Test to wake from sleep AND send data to Adafruit
//..............RTC is not hooked up yet on this version..................
//WORKS PIN 2 INT0 ON ARDUINO MEGA 2560

#include <avr/sleep.h>
#include <avr/power.h>
#include <avr/interrupt.h>

//COPIED---------------------------------------------------------------------------------------------------------------------
#include "Adafruit_FONA.h"            // from botletics: https://github.com/botletics/SIM7000-LTE-Shield/tree/master/Code
#include "Adafruit_MQTT.h"            // from adafruit:  https://github.com/adafruit/Adafruit_MQTT_Library
#include "Adafruit_MQTT_FONA.h"
#include <Adafruit_MCP9808.h>         // MCP9808 (TEMPERATURE) SENSOR LIBRARY 
#include <SD.h>                       // SD CARD LIBRARY
#include <SPI.h>                      // SERIAL PERIPHERAL INTERFACE LIBRARY
#include <DS3232RTC.h>                // RTC LIBRARY https://github.com/JChristensen/DS3232RTC
#include <Wire.h>                     // I2C COMMUNICATION LIBRARY
#include <OneWire.h>                  // 1 WIRE COMMUNICATION LIBRARY
#include <DallasTemperature.h>        // EXTERNAL DS18B20 TEMPERATURE SENSOR LIBRARY
#include <Adafruit_INA219.h>          // INA219 CURRENT SENSOR LIBRARY

//CLOCK OBJ


DS3232RTC RTC;
 //1 hz pulse for the external D-FF 

/*
   SPI PINS FOR MEGA:
      SCK - 13, 52
      MISO - 12, 50
      MOSI - 11, 51
      SS - general GPIO (53 here)
*/

#define SIMCOM_7000                   // cellular MCU we are using

// FONA PINS -------------------------
#define FONA_PWRKEY 6
#define FONA_RST 7
#define FONA_DTR 8
#define FONA_TX 10
#define FONA_RX 11

// indicator LEDs
#define redLed 26                      // MQTT publish error
#define yellowLed 24                   // data collection occurring
#define greenLed 23                    // MQTT connected
#define blueLed 22                     // network connected
#define whiteLed 25                    // GPS error
//#define interrupt 5                    // interrupt pin for RTC (NOTE: 5 is INT5, the hardware interrupt that is on pin 18)
//#define interruptPin 18                //


//int sampling_rate = 2;                // initialize the delay between loops. This can be changed with subscribe
//const int keepAlive_mins = round(MQTT_CONN_KEEPALIVE / 60);
//int liquid_level = 0;

// send AT commands via fona's software serial
#include <SoftwareSerial.h>
SoftwareSerial fonaSS = SoftwareSerial(FONA_TX, FONA_RX);
SoftwareSerial *fonaSerial = &fonaSS;

// construct an instance of the LTE fona
Adafruit_FONA_LTE fona = Adafruit_FONA_LTE();

// MQTT SETUP WITH ADAFRUIT IO --------------
#define AIO_SERVER      "io.adafruit.com"
//#define AIO_SERVERPORT  ####
//#define AIO_USERNAME    "YOUR USER"
//#define AIO_KEY         "YOUR KEY"

// pass in fona class and server details to mqtt class
Adafruit_MQTT_FONA mqtt(&fona, AIO_SERVER, AIO_SERVERPORT, AIO_USERNAME, AIO_KEY);

//************************************ UNCOMMENT FOR FEEDS BELONGING TO SENSOR 1 *****************
// THE PUBLISHING FEEDS ----------------------------
//Adafruit_MQTT_Publish feed_location = Adafruit_MQTT_Publish(&mqtt, AIO_USERNAME "/feeds/whs-3.location/csv");
Adafruit_MQTT_Publish feed_fona_lipo = Adafruit_MQTT_Publish(&mqtt, AIO_USERNAME "/feeds/syphon-sensor.lipo-battery");
//Adafruit_MQTT_Publish feed_external_temp = Adafruit_MQTT_Publish(&mqtt, AIO_USERNAME "/feeds/whs-3.external-temperature");
Adafruit_MQTT_Publish feed_voltage = Adafruit_MQTT_Publish(&mqtt, AIO_USERNAME "/feeds/syphon-sensor.package-battery");
Adafruit_MQTT_Publish feed_sensorVal = Adafruit_MQTT_Publish(&mqtt, AIO_USERNAME "/feeds/syphon-sensor.syphonbool");

// THE SUBSCRIBING FEEDS ---------------------------
Adafruit_MQTT_Subscribe feed_deploy = Adafruit_MQTT_Subscribe(&mqtt, AIO_USERNAME "/feeds/syphon-sensor.deploy");


// define the SS for SD card
#define chipSelect 53

// construct the MCP9808
//Adafruit_MCP9808 tempsensor = Adafruit_MCP9808();

// contact sensor define
#define contactSensor 5
//pinMode(contactSensor, INPUT);

/*
// construct the DS18B20
#define ONE_WIRE_BUS 4
OneWire oneWire(ONE_WIRE_BUS);
DallasTemperature ds18b20(&oneWire);

//construct RTC
DS3232RTC RTC;
*/

// construct the INA219
//Adafruit_INA219 ina219;

// some global variables
uint8_t readline(char *buff, uint8_t maxbuff, uint16_t timeout = 0);
char imei[16] = {0};
bool deployed = false;
bool new_time = false;
bool new_loc = false;

//END COPIED---------------------------------------------------------------------------------------------------------------------

int counter = 0;
int n = counter;
int sleepCount = 3;
double contactValTime = 0;
int counterTimes = 0;
int contactVal = 0;
int prevContactVal = 0;
int sendCount = 0;
void setup() {  //--------------------------------------------------------------------------------SETUP----------------------------------
  Serial.begin(9600);
  Serial.println(F("*** Executing Full_Syphon_Sensor v1.0 ***"));
  pinMode(3, INPUT);
  //COPIED---------------------------------------------------------------------------------------------------------------------
  pinMode(redLed, OUTPUT);
  digitalWrite(redLed, LOW);
  pinMode(yellowLed, OUTPUT);
  digitalWrite(yellowLed, LOW);
  pinMode(greenLed, OUTPUT);
  digitalWrite(greenLed, LOW);
  pinMode(blueLed, OUTPUT);
  digitalWrite(blueLed, LOW);
  pinMode(whiteLed, OUTPUT);
  digitalWrite(whiteLed, LOW);

  RTC.DS3232RTC::begin();
  RTC.squareWave(DS3232RTC::SQWAVE_1_HZ);

  pinMode(FONA_RST, OUTPUT);
  digitalWrite(FONA_RST, HIGH);             // reset is default high

  pinMode(FONA_DTR, OUTPUT);
  digitalWrite(FONA_DTR, LOW);              // initialize to LOW so that if clock is high fona will be awake

  fona.powerOn(FONA_PWRKEY);                // power on fona by pulsing power key

  moduleSetup();                            // establish serial communication, find fona, determine device IMEI

  fona.setFunctionality(1);                 // set fona to its full functionality (AT+CFUN=1)

  fona.setNetworkSettings(F("hologram"));   // sets APN as 'hologram', used with Hologram SIM card

  //fona.set_eDRX(1,5,0100);                // sets eDRX mode (not supported by T-mobile LTE

  // first disable data
  if (!fona.enableGPRS(false)) Serial.println(F("Failed to disable data!"));

  // enable data
  while (!fona.enableGPRS(true)) {
    Serial.println(F("Failed to enable data, retrying..."));
    delay(2000); // Retry every 2s
  }
  Serial.println(F("Enabled data!"));

  // subscribe to the subscription feeds
  mqtt.subscribe(&feed_deploy);

  // set the keepalive interval in seconds
  //mqtt.setKeepAliveInterval(600);

  // connect to cell network
  while (!netStatus()) {
    Serial.println(F("Failed to connect to cell network, retrying..."));
    delay(2000); // Retry every 2s
    digitalWrite(blueLed, LOW);
  }
  Serial.println(F("Connected to cell network!"));
  digitalWrite(blueLed, HIGH);
  //Initial Value
  Serial.println("Sending initial value...");                //NOT
  contactVal = digitalRead(3);
  prevContactVal = contactVal;
  //prevContactVal = contactVal;
  //contactVal = 1-contactVal;
  Serial.print("Contact Sensor Value: ");
  Serial.println(contactVal);
  Serial.println("Sending the Value...");
  char contactValBuff[1];                                    //NOT
  dtostrf(contactVal, 1, 1, contactValBuff);                 //NOT
  MQTT_connect();                                            //NOT
  delay(1000);                                               //NOT
  MQTT_publish_checkSuccess(feed_sensorVal, contactValBuff); //NOT

  // first ensure that we are finished configuring everything in Adafruit IO and want the package to start collecting data
  while (! deployed) {

    while (!netStatus()) {
      Serial.println(F("Failed to connect to cell network, retrying..."));
      delay(2000); // Retry every 2s
      digitalWrite(blueLed, LOW);
    }

    MQTT_connect();
    // subscription packet subloop, this runs and waits for the toggle switch in Adafruit IO to turn on
    Adafruit_MQTT_Subscribe *subscription;
    while ((subscription = mqtt.readSubscription(5000))) {
      if (subscription == &feed_deploy) {
        Serial.print(F("*** Package: ")); Serial.println((char *)feed_deploy.lastread);
        if (strcmp(feed_deploy.lastread, "ON") == 0) {
          Serial.println(F("***Package is deployed"));
          deployed = true;
        }
        else if (strcmp(feed_deploy.lastread, "OFF") == 0) {
          Serial.println(F("***Package not ready"));
          //delay(5000);    // wait five seconds to not spam the serial monitor
        }
      }
    }
  }
    delay(3000);
  //END COPIED-----------------------------------------------------------------------------------------------------------------
  

  //configure interrupt, MEGA can only do LOW interrupts to wake
  //attachInterrupt(digitalPinToInterrupt(2), ISR__Wake, LOW);
  Serial.println("Success Setup");
}
void loop() { //---------------------------------------------------------------------- LOOP ------------------------------------------------------------
/*
//COPIED
  // wake up the fona (should be done in the interrupt function, add here too for error handling)
  digitalWrite(FONA_DTR, LOW);

  // connect to cell network
  while (!netStatus()) {
    Serial.println(F("Failed to connect to cell network, retrying..."));
    delay(2000); // Retry every 2s
    digitalWrite(blueLed, LOW);
  }
//  Serial.println(F("Connected to cell network!"));
  digitalWrite(blueLed, HIGH);
  //readRSSI();

  digitalWrite(yellowLed, HIGH);
//END COPIED
*/
  delay(1000);
  counter++;
  sleepCount = 3 - (counter-1);       //counts down seconds before arduino enters sleep mode
  contactVal = digitalRead(3);
  Serial.print("Seconds until Sleep: ");
  Serial.print(sleepCount, DEC);
  Serial.println(" second");
  Serial.print("Sensor Value: ");
  Serial.println(contactVal);         //Want this to be 1 all 3 times before the sleep
  if(counter == 3)
  {
    Serial.println("Entering sleep");
    delay(200);
    counter = 0;
    //digitalWrite(FONA_RST, LOW);
    enterSleep();
  }
}
void ISR__Wake() {
  Serial.println("Waking up ISR Successfully called.");
  delay(100);
  sleep_disable();
  contactVal = digitalRead(3);
  if (contactVal == prevContactVal)
  {
    Serial.println("--------No change, back to sleep!--------");
    enterSleep();
  }
  detachInterrupt(digitalPinToInterrupt(2));
  digitalWrite(FONA_DTR, LOW);
  delay(500);
}

void enterSleep(void)
{
  
  /* Setup pin2 as an interrupt and attach handler. */
  //attachInterrupt(digitalPinToInterrupt(2), ISR__Wake, LOW);
  delay(100);
  prevContactVal = contactVal;

  fona.println("AT+CSCLK=1");
  if (fona.available()) {
    Serial.println(fona.read());
  }
  delay(500);
  digitalWrite(FONA_DTR, HIGH);
  sleep_enable();
  attachInterrupt(digitalPinToInterrupt(2), ISR__Wake, LOW);
  delay(100);
  set_sleep_mode(SLEEP_MODE_PWR_DOWN);
  
  sleep_cpu();
  
  /* The program will continue from here. */
  /* First thing to do is disable sleep. */
  sleep_disable();
  if (contactVal != prevContactVal)
  {
    stuffOuttaSleep();
  }
  else
  {
    Serial.println("--------No change, back to sleep!--------");
    enterSleep();
  }
  //contactVal = digitalRead(3);
  //contactVal = 1-contactVal;    //invert pin value
//  char contactValBuff[1];
//  dtostrf(contactVal, 1, 1, contactValBuff);
  //Serial.println("Woken up success ");
  //Serial.print("Contact Sensor Value ");
  //Serial.println(contactVal); 

}

void stuffOuttaSleep()
{
  Serial.println("stuffOuttaSleep Function Success Called...");
  //pinMode(redLed, OUTPUT);
  //digitalWrite(redLed, LOW);
  //pinMode(yellowLed, OUTPUT);
  //digitalWrite(yellowLed, LOW);
  //pinMode(greenLed, OUTPUT);
  //digitalWrite(greenLed, LOW);
  //pinMode(blueLed, OUTPUT);
  //digitalWrite(blueLed, LOW);
  //pinMode(whiteLed, OUTPUT);
  //digitalWrite(whiteLed, LOW);

  //pinMode(FONA_RST, OUTPUT);
  //digitalWrite(FONA_RST, HIGH);             // reset is default high

  //pinMode(FONA_DTR, OUTPUT);
  //digitalWrite(FONA_DTR, LOW);              // initialize to LOW so that if clock is high fona will be awake

  //fona.powerOn(FONA_PWRKEY);                // power on fona by pulsing power key

  //moduleSetup();                            // establish serial communication, find fona, determine device IMEI

  fona.setFunctionality(1);                 // set fona to its full functionality (AT+CFUN=1)

  fona.setNetworkSettings(F("hologram"));   // sets APN as 'hologram', used with Hologram SIM card

  //fona.set_eDRX(1,5,0100);                // sets eDRX mode (not supported by T-mobile LTE

  // first disable data
  if (!fona.enableGPRS(false)) Serial.println(F("Failed to disable data!"));

  // enable data
  while (!fona.enableGPRS(true)) {
    Serial.println(F("Failed to enable data, retrying..."));
    delay(2000); // Retry every 2s
  }
  Serial.println(F("Enabled data!"));

  MQTT_connect();
  // subscribe to the subscription feeds
  mqtt.subscribe(&feed_deploy);

  // set the keepalive interval in seconds
  //mqtt.setKeepAliveInterval(600);

  // connect to cell network
  while (!netStatus()) {
    Serial.println(F("Failed to connect to cell network, retrying..."));
    delay(2000); // Retry every 2s
    digitalWrite(blueLed, LOW);
  }
  Serial.println(F("Connected to cell network!"));
  digitalWrite(blueLed, HIGH);
  //Initial Value
  Serial.println("Sending initial value...");                //NOT
  contactVal = digitalRead(3);    //3 pin is actual sensor val
  //prevContactVal = contactVal;
  //contactVal = 1-contactVal;
  Serial.print("Contact Sensor Value: ");
  Serial.println(contactVal);
  Serial.println("Sending the Value...");
  char contactValBuff[1];                                    //NOT
  dtostrf(contactVal, 1, 1, contactValBuff);                 //NOT
  MQTT_connect();                                            //NOT
  delay(1000);                                               //NOT
  MQTT_publish_checkSuccess(feed_sensorVal, contactValBuff); //NOT
  delay(500);
}

void sensorBounceSleep()
{
  Serial.println("False alarm switching: back to sleep");
  enterSleep();
}


//COPIED FUNCTIONS-----------------------------------------------------------------------------------------------------------------
void goSleep() {
  Serial.println("Going to sleep...");
  delay(100);
  mqtt.disconnect();
  //delay(5000);
  digitalWrite(FONA_RST, LOW);
  delay(100);
  digitalWrite(FONA_RST, HIGH);

  fona.println("AT+CSCLK=1");
  if (fona.available()) {
    Serial.println(fona.read());
  }

  delay(500);

  digitalWrite(FONA_DTR, HIGH);

  // activate sleep mode, attach interrupt and assign a waking function to run
  sleep_enable();
  attachInterrupt(0, wakeUp, LOW);
  delay(100);
  set_sleep_mode(SLEEP_MODE_PWR_DOWN);              // set to full sleep mode
  sleep_cpu();
}

void wakeUp() {
  Serial.println("RTC Interrupt fired");
  delay(100);
  sleep_disable();
  detachInterrupt(0);

  digitalWrite(FONA_DTR, LOW);
  delay(500);
}

void moduleSetup() {
  // this should all take about 3s for the SIMCOM 7000 module
  fonaSS.begin(115200); // Default SIM7000 shield baud rate
  Serial.println(F("Configuring to 9600 baud"));
  fonaSS.println("AT+IPR=9600"); // Set baud rate
  delay(100); // Short pause to let the command run
  fonaSS.begin(9600);
  if (! fona.begin(fonaSS)) {
    Serial.println(F("FONA not found"));
    while (1); // Don't proceed if it couldn't find the device
  }

  uint8_t type = fona.type();
  Serial.println(F("FONA is OK"));
  Serial.print(F("Found "));
  switch (type) {
    case SIM800L:
      Serial.println(F("SIM800L")); break;
    case SIM800H:
      Serial.println(F("SIM800H")); break;
    case SIM808_V1:
      Serial.println(F("SIM808 (v1)")); break;
    case SIM808_V2:
      Serial.println(F("SIM808 (v2)")); break;
    case SIM5320A:
      Serial.println(F("SIM5320A (American)")); break;
    case SIM5320E:
      Serial.println(F("SIM5320E (European)")); break;
    case SIM7000:
      Serial.println(F("SIM7000")); break;
    case SIM7070:
      Serial.println(F("SIM7070")); break;
    case SIM7500:
      Serial.println(F("SIM7500")); break;
    case SIM7600:
      Serial.println(F("SIM7600")); break;
    default:
      Serial.println(F("???")); break;
  }

  // Print module IMEI number.
  uint8_t imeiLen = fona.getIMEI(imei);
  if (imeiLen > 0) {
    Serial.print("Module IMEI: "); Serial.println(imei);
  }
}

bool netStatus() {
  int n = fona.getNetworkStatus();

  Serial.print(F("Network status ")); Serial.print(n); Serial.print(F(": "));
  if (n == 0) Serial.println(F("Not registered"));
  if (n == 1) Serial.println(F("Registered (home)"));
  if (n == 2) Serial.println(F("Not registered (searching)"));
  if (n == 3) Serial.println(F("Denied"));
  if (n == 4) Serial.println(F("Unknown"));
  if (n == 5) Serial.println(F("Registered roaming"));

  if (!(n == 1 || n == 5)) {
    return false;
    digitalWrite(blueLed, LOW);
  }
  else return true;
}

void MQTT_connect() {
  int8_t ret;

  // Stop if already connected.
  if (mqtt.connected()) {
    digitalWrite(greenLed, HIGH);
    return;
  }

  Serial.println("Connecting to MQTT... ");

  while ((ret = mqtt.connect()) != 0) { // connect will return 0 for connected
    digitalWrite(greenLed, LOW);
    Serial.println(mqtt.connectErrorString(ret));
    Serial.println("Retrying MQTT connection in 5 seconds...");
    mqtt.disconnect();
    delay(5000);  // wait 5 seconds
  }
  digitalWrite(greenLed, HIGH);
  Serial.println("MQTT Connected!");
}

void MQTT_publish_checkSuccess(Adafruit_MQTT_Publish &feed, const char *feedContent) {
  Serial.println(F("Sending data..."));
  uint8_t txfailures = 0;
  if (! feed.publish(feedContent)) {
    for (int i = 0; i < 5; i++) {
      digitalWrite(redLed, HIGH);
      delay(200);
      digitalWrite(redLed, LOW);
    }
    Serial.println(F("Failed"));
    txfailures++;
  }
  else {
    digitalWrite(redLed, LOW);
    Serial.println(F("OK!"));
    txfailures = 0;
  }
}
//END COPIED FUNCTIONS-----------------------------------------------------------------------------------------------------------------

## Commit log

2022-01-12 add test code and necessary libraries
    [Pressure Sensor Calibration.xlsx, pressureVolt-20210910-2154.csv]
2022-01-25 add flowchart
2022-01-25 stabilize deploy_switch_tester.ino
    The deployment switch works, temp, pressure, and stage are all published successfully.
    [deploy_switch_tester.ino]
2022-01-26 stabilize deploy_switch_tester.ino
    The deployment control and publications all work, and parameters like sea level and sampling rate can be initialized before the deployment switch is pressed. Control is in void setup.
    [deploy_switch_tester.ino]
2022-01-28 fix pressure sensor reading
    [WHS_v1.1.2.ino]
2022-01-28 incorporate linear scaling equation
    [Pressure Sensor Calibration.xlsx]
2022-02-01 Update pressure_tester.ino
    add Serial input and a push button to control when readings are taken. Made for lab test descending_feb1.txt
2022-02-01 Create pressure_field_test.ino
    Serial input and a push button to control when readings are taken. Made for lab test descending_feb1.txt
2022-02-01 Revert "Update pressure_tester.ino"
    This reverts commit b91f9afb9aa6d315b22d7a460967bbe3e4502017.
    [pressure_tester.ino]
2022-02-01 change gps failure message
    [WHS_v1.1.3.ino]
2022-02-02 more debugging codes
    clock calibration and an update tester
2022-02-03 moving pressure data
    [Pressure Sensor Calibration.xlsx, fill_test_feb3.xlsx, pressureVolt-20210910-2154.csv]
2022-02-03 Create WHS_v1.2.1.ino
    Used for testing in the field, only publishes pressure and temperature data
2022-02-07 fix location boolean control
    [WHS_v1.2.1.ino]
2022-02-08 add rtc and gps power saving
2022-02-10 create v1 EDA
    [v1.kicad_pcb, v1.kicad_sch]
2022-02-12 moving things around
    [Pressure Sensor Calibration.xlsx, benchtop_observations_feb11.xlsx, fill_test_feb3.xlsx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]
2022-02-14 reorganize EDA
    [v1.kicad_pcb, v1.kicad_sch]
2022-02-14 add pie chart
    [benchtop_observations_feb11.xlsx]
2022-02-15 create 5 min cycle pie charts
    [benchtop_observations_feb11.xlsx]
2022-02-15 add contact sensor
2022-02-22 update characteristic data
    [Pressure Sensor Calibration.xlsx, benchtop_observations_feb11.xlsx, fill_test_feb3.xlsx]
2022-02-24 incorporate power saving techniques
    turn gps off after collection and in setup, fix logic on pulling DTR pin up and down, fix AT+CSCLK command
    [WHS_v1.2.1.ino]
2022-03-01 change pressure reading from hPa to psi
2022-03-15 change pins for datalogging board
2022-03-16 create power board
    [power_board_v1.kicad_pcb, power_board_v1.kicad_sch]
2022-03-16 fix connectivity issues associated with low power modes, add delay to go into sleep mode
    AT+CSCLK=1 always, DTR is pulled LOW at all times except during sleep mode. Delays are required after pulling LOW/HIGH so that everything wakes/sleeps properly. Delay required before entering sleep mode.
    [WHS_v2.0.1.ino]
2022-03-16 rename whs2.0.1 (fixed with low power)
    [WHS_v2.0.ino]
2022-03-16 add fona lipo monitor
2022-03-17 add gerber files
2022-03-17 update PCB
    [power_board_v1.kicad_pcb, power_board_v1.kicad_sch]
2022-03-21 Update WHS_v2.0.2.ino
    include tolerances, ping calculations, remainder calculations. Remainder calculations still throwing errors
    [WHS_v2.0.2.ino]
2022-03-25 add delay for ping function, initialize remainder to sampling_rate
    delay needed to avoid timeout before ping is successfully sent. remainder initialized to sampling rate to get rid of unnecessary else statement
    [WHS_v2.0.2.ino]
2022-03-30 restructuring
    new file branching off water level sensor and syphon sensor codes
2022-04-04 3/31 field test data
    [adafruit_data.csv, usgs_data.csv]
2022-04-06 Create WHS_v2.1.0_noSPI.ino
    an adaptive sampling script to adjust for the shorted SD card and SPI communications
    [WHS_v2.1.0_noSPI.ino]
2022-04-12 process field testing data
    [adaptive_stage_data.csv, pressure_data.csv, stage_data.csv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]
2022-04-18 compare filter
    [filters.csv]
2022-04-18 separately test filters
2022-04-20 add last replacement filter
    [filters.csv]
2022-04-29 testing and visualization
    [adaptive_simulations.csv]
2022-04-29 filtering testing and visualization
2022-04-29 add sensor 2 feeds
2022-04-29 plot 4/22 field test
    [pressure_data.csv, stage_data.csv, usgs_data.csv]
2022-04-29 add voltage feeds
2022-04-29 comment sensor 1 feeds
2022-05-12 change variable "tolerance" to "distError"
    "tolerance" was used twice in both the median filter and RTC alarm setting
    [WHS_v2.0.5.ino]
2022-05-12 data processing for may 3 - 9 deployment
    [pressure_data.csv, stage_data.csv, usgs_data.csv]
2022-05-16 change distance reading threshold, integrate power feeds
2022-05-20 change readings to cm, account for diode voltage drop, change reading to F
2022-05-20 change folder names
    [v1.kicad_pcb, v1.kicad_sch]
2022-05-20 plot 5/12 - 5/17 field test data
    [pressure_data.csv]
2022-05-20 plot temperature and pressure transducer drift
2022-05-25 fix pressure correction factor
    [pressure_data.csv]
2022-06-02 add may 20 - 25 field test
    [pressure_data.csv, stage_data.csv]
2022-06-12 remove post-fieldtest data
    [pressure_data.csv, stage_data.csv]
2022-06-28 process data
    [pressure_data.csv, pressure_data_filtered.csv, stage_data.csv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]
2022-06-29 change x axis title from "distance" to "elevation"
2022-07-01 add hobo test data
    [DHEC_HOBO_DATA.xlsx]
2022-07-15 add power board v2
    [power_board_v2.kicad_pcb, power_board_v2.kicad_sch]
2022-07-15 add 07/01-07/15 field test
    [pressure_data.csv, stage_data.csv, stage_data_filtered.csv]
2022-07-19 rename folder
    [pressure_data.csv, rainfall.csv, stage_data.csv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]
2022-07-19 change plot size, pressure transducer label
